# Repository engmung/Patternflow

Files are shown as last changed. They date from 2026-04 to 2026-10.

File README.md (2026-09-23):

# Patternflow








<p align="center">
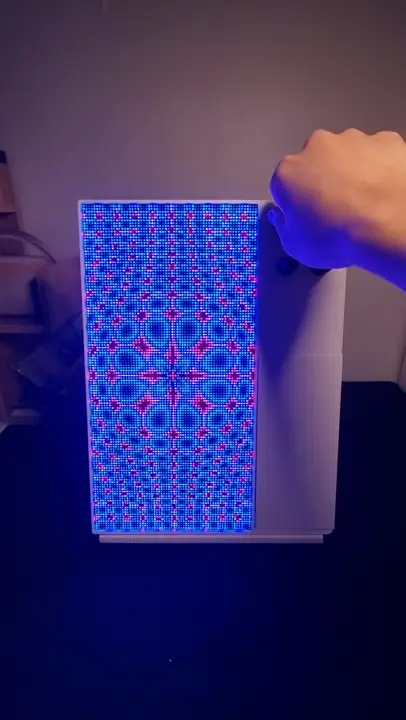
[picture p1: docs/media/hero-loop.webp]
Patternflow: a hand turns a knob and the light reshapes
  
  <a href="https://youtu.be/BPMhTChY9vg">Patternflow, the film: what it is, how it's built, and why</a>
</p>
<p align="center">
  <sub><a href="https://www.instagram.com/p/DbD2z1VSG09/">▶ the reel: <b>400k+ views</b> on Instagram</a> &nbsp;·&nbsp; <a href="https://youtu.be/BPMhTChY9vg">▶ <b>the film</b>: the whole story, on YouTube</a></sub>
</p>

> **Photosensitivity warning.** Patternflow displays rapidly changing light patterns that may trigger seizures in people with photosensitive epilepsy. If you experience any discomfort, stop use immediately.

**Patternflow is an open-source LED synthesizer.** You play it with four knobs. 8,192 pixels across a 128 × 64 matrix respond the instant you turn one; nothing is pre-rendered, every frame is computed live on the device. A pattern is just a small file, so every Patternflow plays every pattern anyone makes.

## Where it began

Almost every screen around us is a playback device. It takes in content and shows it to us, and we sit in front of it and watch. Patternflow is different: touch it and it answers in that instant, and nobody plays the same thing twice.

In January 2026 I stopped by the Nam June Paik Art Center, which happened to be running an event marking twenty years since Paik's death. That is how I ended up standing in front of *Participation TV* (1963): you speak into a microphone and the picture on the screen moves with your voice. It turned the viewer from someone watching into someone taking part. I spoke into it, and my voice became the picture.

Two months later I connected an LED matrix and a potentiometer for the first time.

Where Paik brought the audience into the work, Patternflow hands over the making of it.

I put that first pattern, *Patternflow: Origin*, on an LED matrix with four knobs and posted it online. Some people asked how to buy it; far more asked how to build it. So everything went public: schematics, firmware, 3D models, the build guide, and the whole workflow for making new patterns.

## The community responded

<p align="center">
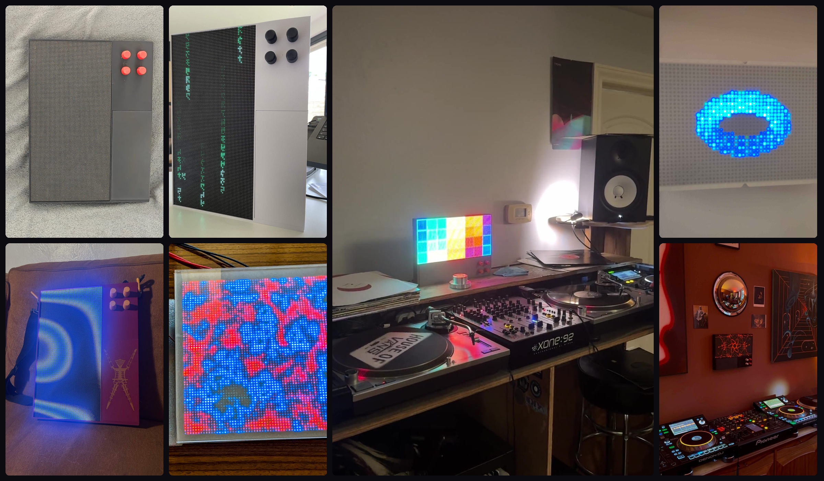
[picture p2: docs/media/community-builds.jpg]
Seven Patternflows built around the world: different enclosures, colors and materials, two of them in DJ booths
  
</p>
<p align="center">
  <sub><i>Builds by Nath (UK), shooter (Poland), day (France), Enerjoy (Norway), SimonePDA (UAE), Nick (USA), and Jon (USA).</i></sub>
</p>

Builders from around the world keep adding pins to the **[build map](https://patternflow.work/inside)**. Someone built theirs as a Raspberry Pi port with a 64 × 32 matrix, another layered paper and acrylic into a diffuser, others cut their own enclosures. Two of them live in DJ booths.

I started this alone. It hasn't worked that way for a while now. The web-upload feature wasn't mine: someone suggested it, built a proof of concept, and shared the code, and two days later it shipped as a main feature. The `.pfm` pattern modules came the same way. A contributor designed the loader, built it, and proved it on hardware before proposing it. They're core to the instrument now.

The clearest case started on the other side of the world. A media art collective took Patternflow's pattern modules, added MIDI control and a microphone, and built a browser-based instrument of their own: **[MOTIFLOW](https://azmano.art/portfolio-item/motiflow/)**, recently shown in a gallery. Patternflow had become something people build their own instruments out of.

**Patternflow is a thing we're all making now.**

## Make it yours

### 1. The device

The **[Full Build Guide](BUILD_GUIDE.md)** covers the official route: the custom PCB and a 3D-printed enclosure. Don't want to order a board? The **[Breadboard Build Guide](https://patternflow.work/build/breadboard)** wires the same electronics with jumper wires instead, and that's a real Patternflow, not a temporary prototype. Every other combination is on the **[Assembly Map](docs/assembly/README.md)**. Parts run about US$100–200 ([BOM](BUILD_GUIDE.md#1-bill-of-materials-bom)), it's all big through-hole joints, and every first-timer who has built one finished it. Most came back saying the soldering was the fun part.

**When yours lights up, tell us.** Post it in [Discord](https://discord.gg/Vr9QtsxeTk) or fill in the [Share your build](../../issues/new?template=share_build.yml) form and it goes on the build map, a globe of Patternflows where each pin carries its build's story. The map is for the ones people made themselves: every pin is someone who built one from these files, in their own material, wherever they are. The goal is simple: cover it with pins.

<p align="center">
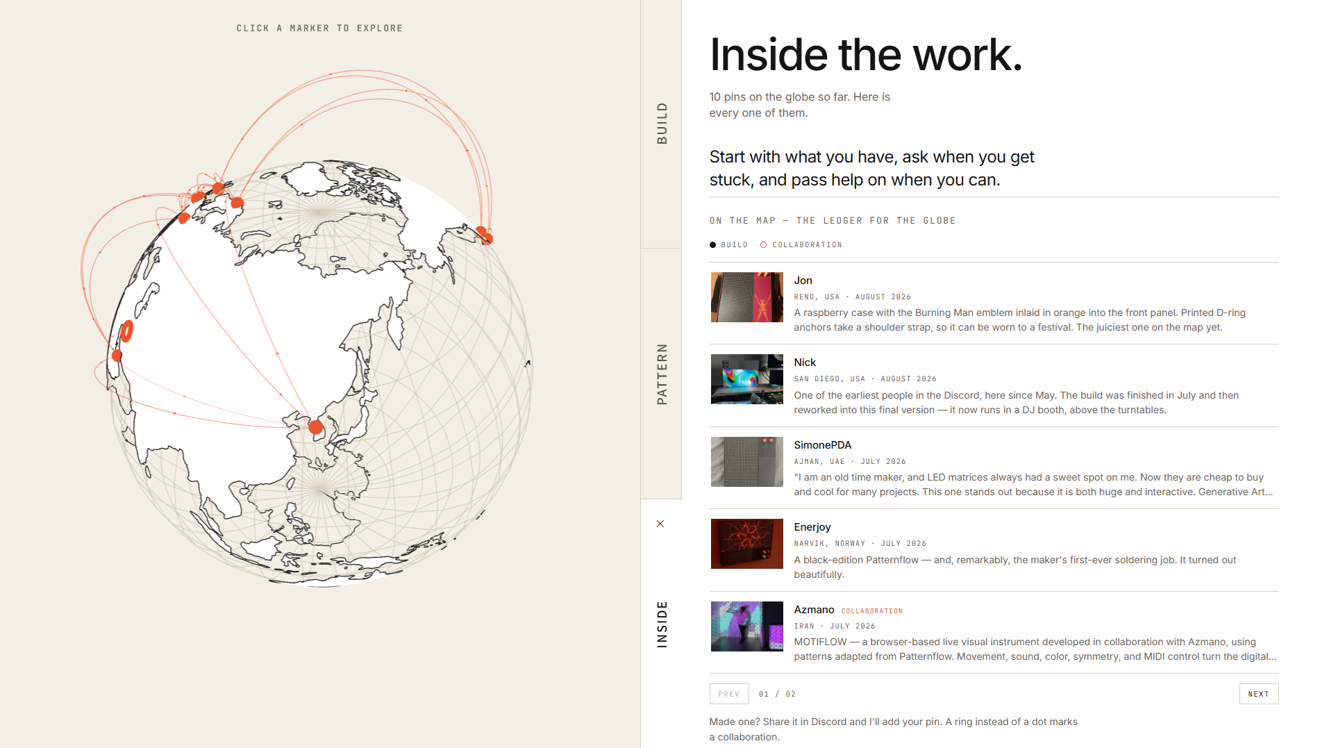
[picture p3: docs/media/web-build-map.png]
Build map: a globe of Patternflows built around the world, with the story of every build
  
</p>

If you'd rather have one arrive assembled, tested, and flashed, the **[Crowd Supply campaign](https://www.crowdsupply.com/engmung/patternflow)** is currently live. Back the campaign to have an assembled unit, DIY kit, or custom enclosure shipped worldwide.

### 2. Patterns

You don't need hardware to start. The **[Live Editor](https://patternflow.work/pattern)** is a full Patternflow simulator: turn the virtual knobs and it behaves like the real thing. Patterns start as JavaScript in the browser, and you don't have to write it yourself. Click **Copy creation prompt**, paste it into your AI assistant with a description of the look you want, paste back the code it returns, and play. You don't write GLSL or touch a rendering pipeline: the template handles the encoder mapping, brightness curve and pixel buffer, and you describe the visuals.

<p align="center">
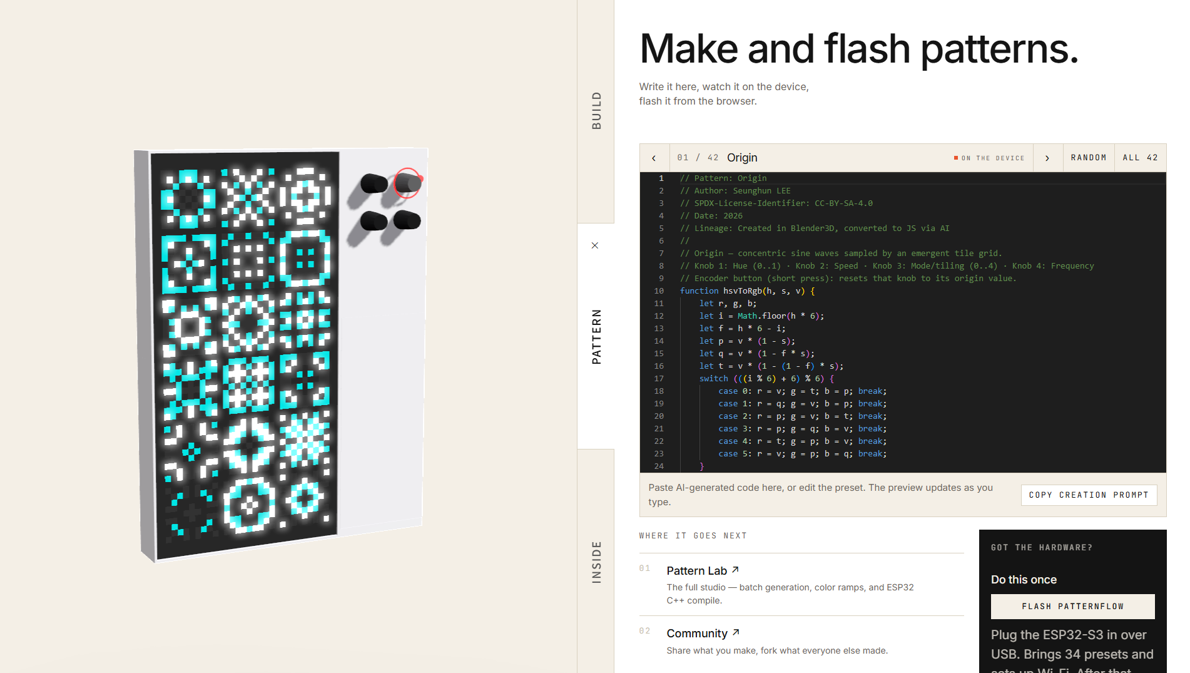
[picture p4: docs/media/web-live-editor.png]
Live Editor: a full Patternflow simulator in the browser, code beside the device
  
</p>

**[Pattern Lab](https://patternflow.work/pattern-lab)** is the full studio, and where a pattern reaches the hardware. Generate variations in batches, shape color ramps, retune knob ranges, then send it to your device: it builds into a small `.pfm` module and installs over Wi-Fi, about ten seconds start to finish. You never plug in a cable, reflash the board, or open an IDE. The Capture panel takes the same pattern off the panel: a PNG at print size for a business card, or an MP4 loop for a post, rendered in your browser with nothing uploaded.

When it looks right, publish it to the **[Community](https://community.patternflow.work/community)**. More than a hundred patterns are up already and the range keeps widening, from quiet waves to chaos-theory studies, every one written as code and every one playable under the same four knobs. Collect patterns into a deck and send it to your board in one click. Browsing needs no account, and publishing asks a username and password, no email. The **[Pattern Guide](PATTERN_GUIDE.md)** walks the whole loop.

<p align="center">
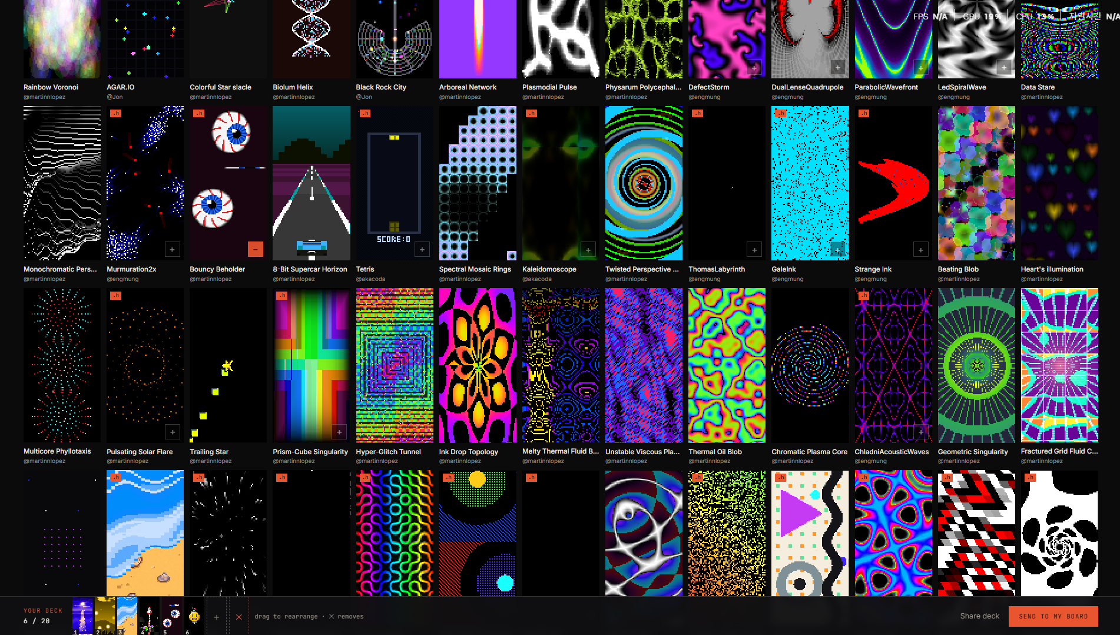
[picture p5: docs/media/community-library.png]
The community wall: dozens of patterns by different authors, each one playing, with a deck being assembled along the bottom
  
</p>

Patterns don't stay on the wall, either. New pattern studies go up on **[Instagram](https://www.instagram.com/patternflow.work)** almost daily. Publish something that stands out and it can get featured there, or ask for a collab on Instagram and we'll post yours together.

### 3. The ecosystem

Patterns are the surface. Underneath is an instrument still being designed, in the open, by whoever shows up. This is the whole system on one napkin:

<p align="center">
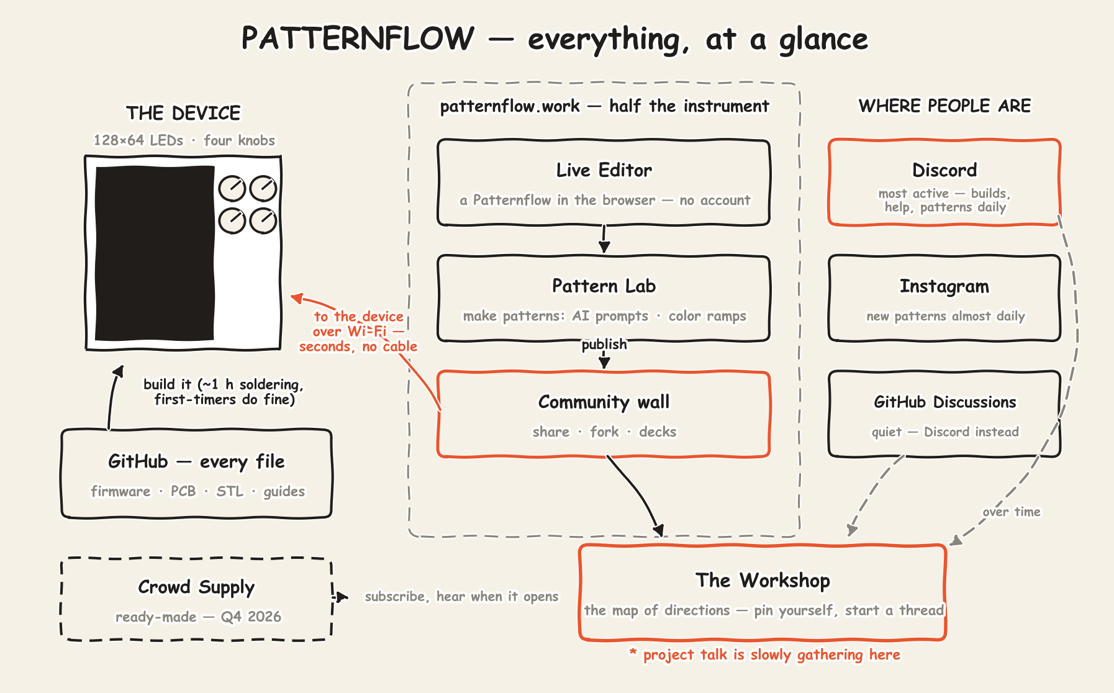
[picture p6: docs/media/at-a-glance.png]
Hand-drawn map of the Patternflow ecosystem: the device, the GitHub files and Crowd Supply routes to it; patternflow.work with the Live Editor, Pattern Lab and Community wall; Discord, Instagram and GitHub
  
</p>

It's already moving in directions I didn't choose. One contributor is building out MQTT further than I've had time to follow: units reaching each other across a network, one person's playing coming out of somebody else's device. Another is working on sound on the board itself. Another is taking the TouchDesigner link further than I did. None of it was assigned.

**[CONTRIBUTING.md](CONTRIBUTING.md)** covers how contributions flow. Questions and ideas go to the **[Discord](https://discord.gg/Vr9QtsxeTk)**; where to ask what is **[SUPPORT.md](SUPPORT.md)**.

## Quick facts

| | |
| :--- | :--- |
| **Display** | 128 × 64 HUB75 RGB LED matrix, P2.5 (320 × 160 mm) |
| **Brain** | ESP32-S3-WROOM-1 **N16R8** (16 MB flash, 8 MB PSRAM) · standalone, no sending card |
| **Input** | 4× EC11 rotary encoders with push-switch; long-press encoder 4 to switch patterns ([controls](#playing-it)) |
| **Power** | 5 V over USB from any power bank; about **4 h per 10,000 mAh** at max brightness with a typical pattern (see [runtime](#power--runtime)) |
| **Size / weight** | 245 × 325 × 36 mm (9.6 × 12.8 × 1.4 in) · 933 g (2.06 lb) |
| **Firmware** | Arduino-compatible C++, modular pattern architecture, runtime switching (no reflash) |
| **Flashing** | Everything from the browser: one USB flash the first time, then it's all Wi-Fi. Patterns install as modules in seconds, full firmware builds land wirelessly too. A local build (PlatformIO) only for firmware development or other matrix resolutions |
| **Connectivity** | Wi-Fi and USB. Network MIDI (a MIDI port in any DAW — Ableton, Logic, Bitwig), bidirectional OSC (Max/TouchDesigner/Resolume), MQTT and audio-react each ship in an [edition](docs/EDITIONS.md) you install in one click — the way patterns do — and switching keeps your patterns, networks and settings |
| **Editions** | One image ships on the board; others are a click away on [the shelf](https://patternflow.work/editions); what each feature does, with a reel of it, is on [the features page](https://patternflow.work/features). Writing a feature or cutting your own firmware starts at **[docs/EDITIONS.md](docs/EDITIONS.md)** |
| **Build** | ~1 h hands-on (≈30 min soldering + ≈30 min assembly, first-build friendly) + ~10 h 3D printing · US$100–200 in parts ([BOM](BUILD_GUIDE.md#1-bill-of-materials-bom)) |
| **License** | MIT (firmware & web code) · CC-BY-SA 4.0 (hardware, docs, bundled patterns) · community patterns are licensed by their authors ([summary](docs/LICENSE-SUMMARY.md)) |

### Power & runtime

Patternflow runs off any standard USB power bank that can supply a couple of amps at 5 V. You don't need a wall adapter, so it stays portable. Rule of thumb: **about 4 hours per 10,000 mAh** at maximum brightness with a typical pattern.

<details>
<summary>Measured runtimes</summary>

In testing, a 40,000 mAh bank dropped about 13% over 2 hours at **full brightness**, which is roughly **15 hours on a full charge**:

| Power bank | Approx. runtime (max brightness) |
| :--- | :--- |
| 10,000 mAh | ~4 hours |
| 20,000 mAh | ~8 hours |
| 40,000 mAh | ~15 hours |

These were measured with a bright generative pattern at maximum brightness, which is how the device is normally used. Lowering the brightness (long-press encoder 1) extends runtime well beyond these figures.

**Sleep mode** takes it further: the panel goes dark, the HUB75 transfer stops and the board idles, while staying on Wi-Fi so it can be woken again from MQTT or a browser. Hold encoder 2 for the NETWORK screen, then turn encoder 1; any knob or button wakes it. The pattern that was running comes back, as it does after a full power cut.

**A pattern that fills the screen with white is a different story.** The same 40,000 mAh bank dropped 9% in 30 minutes: about 26.6 W, or roughly 4.8 A at 5 V, which is above what a typical USB-A port is rated for and enough to make the connector warm. That works out to ~5.5 hours on a 40,000 mAh bank. A total-pixel-power clamp is going into the firmware so this can't happen; until then, avoid near-full-white patterns on a power bank, or use a supply and cable rated for the current.

</details>

## Playing it

Every encoder does two jobs. Turn it, or give it a short press, and you are moving the pattern that's running. Hold it down and a device function opens instead, and a second long-press closes it again.

<p align="center">
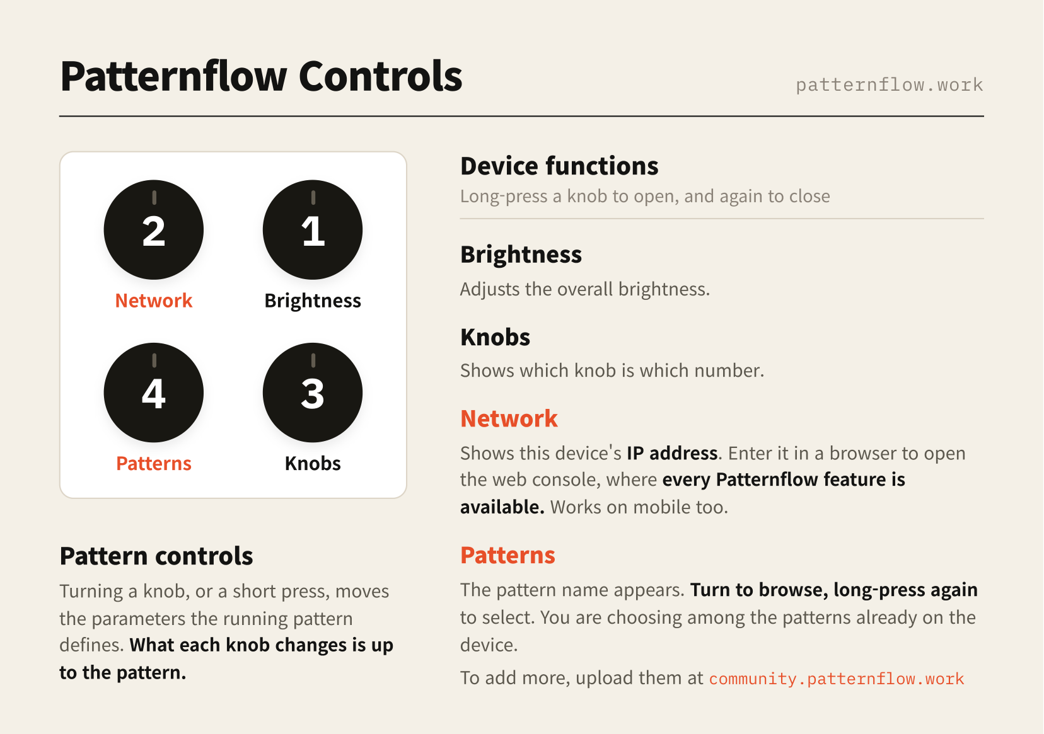
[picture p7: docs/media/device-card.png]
Patternflow controls: encoder 1 brightness, 2 network, 3 knob numbers, 4 patterns; turn or short-press to move the running pattern, long-press for device functions
  
</p>

What a knob does to a running pattern is the pattern's own decision, so the same knob feels different on every one of them. That is what encoder 3 is for: hold it and each knob puts its own number on the panel, which saves counting around the front.

The device functions themselves are fixed. Encoder 1 is brightness. Encoder 4 opens the pattern list, where you turn to browse the names and long-press again to load one, choosing from whatever is installed at the time. Encoder 2 puts the board's IP address on the panel, and typing that into a browser opens the web console, which carries every feature the device has and works from a phone.

## On the device

A new board boots into **Origin**, concentric sine waves sampled by an emergent grid, and long-pressing encoder 4 opens the list of whatever else is installed. Patterns live on the filesystem rather than inside the program. The firmware compiles in Origin alone, as the failsafe a board can always boot into, and everything else installs as **`.pfm` modules over Wi-Fi**, up to 128 of them, no reflash. Adding a pattern never costs a firmware update, and a firmware update never touches your patterns, your Wi-Fi, or your storage.

A new board is therefore nearly empty, so a set ships with it: the **Basics pack**, 33 patterns, at the top of the [decks shelf](https://community.patternflow.work/community/decks). One click installs the lot, no account and no build queue, or drop the `.zip` on your board's Patterns page yourself. The [Live Editor](https://patternflow.work/pattern) opens with its own preset library of 42 patterns, each loadable and remixable in the browser.

A local firmware build (PlatformIO, driven by `firmware/bundles/build.sh`) is only needed for feature development or targeting an LED matrix with a different resolution; the setup is [`firmware/README.md`](firmware/README.md) and a new feature starts at [FEATURE_GUIDE.md](FEATURE_GUIDE.md). Patterns never need it: [Custom Patterns](firmware/CUSTOM_PATTERNS.md). To rebuild the shipped pack from the repo's own preset sources, see [`firmware/toolchain/make_pack.py`](firmware/toolchain/make_pack.py).

## MIDI, OSC, MQTT & audio-react

<p align="center">
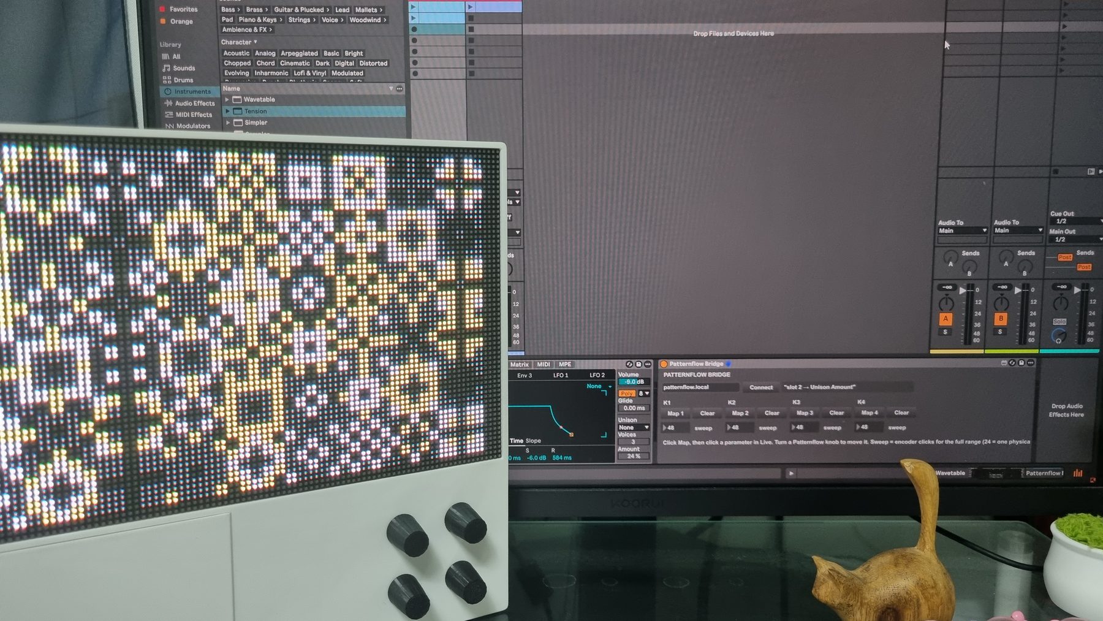
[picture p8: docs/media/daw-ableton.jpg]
Patternflow beside an Ableton Live session, with the Patternflow Bridge Max for Live device open and the four knobs mapped to Live parameters
  
</p>

Each of these lives in an **edition** — a firmware you install from [the shelf](https://patternflow.work/editions) in one click, the same way patterns arrive, and switching keeps your patterns, Wi-Fi networks and settings. MIDI, OSC and audio-react are in **Audio**; MQTT is in **Performance**, alongside sequences and the Director. Why it is arranged that way, and how to build your own: [`docs/EDITIONS.md`](docs/EDITIONS.md).

**MIDI, over the network.** *New.* The panel is a MIDI port: RTP-MIDI over Wi-Fi, native on macOS and iOS, one free driver on Windows. Its four knobs and buttons map to anything in Ableton with Ctrl-M, and a DAW drives the panel back with plain CC and Program Change — the Pattern Lab's Director exports a show as exactly those four CC lanes, so a show can play on the panel from Live's transport. Sensitivity per knob, an absolute or relative mode, and the session that reconnects itself all live on the panel's console. Step by step with screenshots: [`docs/midi-ableton.md`](docs/midi-ableton.md); the contract: [`docs/midi-spec.md`](docs/midi-spec.md).

**Bidirectional OSC.** Over Wi-Fi, Patternflow speaks OSC in both directions: knob turns, button presses, and pattern switches stream out to a remote host (Ableton Live, Max/MSP, TouchDesigner, anything that speaks OSC), and incoming OSC messages drive the device exactly like physical encoder motion. Play Patternflow as a controller for your set, let your set drive the light, or both at once. OSC is the language of Max, TouchDesigner, Resolume and Processing, and it carries more than MIDI can — pattern names, floats, a heartbeat. For Ableton Live Suite there's a ready-made Max for Live bridge in [`integrations/ableton`](integrations/ableton). Click Connect, map the four knobs to any Live parameters, done. The wire protocol is documented in [`docs/osc-spec.md`](docs/osc-spec.md).

**MQTT.** Patternflow also speaks MQTT, both ways, on the broker you already run ([the contract](docs/mqtt-spec.md)). Knob turns and pattern changes publish as they happen; messages coming the other way move the knobs and switch patterns exactly as a hand on the encoder would. Two boards pointed at the same broker follow each other, which is the short version of why it exists. It also puts the device on the same bus as the rest of a home or venue setup, so Home Assistant, Node-RED or a lighting desk can drive it without anything Patternflow-specific in the middle. Point it at a broker on the device's own **MQTT** page; a pattern can be addressed by name or by slug. Publishing `1` to `<prefix>/sleep` puts the panel to sleep and `0` wakes it, with the current state mirrored on `<prefix>/sleep/state`. That is enough for a Home Assistant switch, and it is the one command a panel obeys whether it is set to Publisher or Subscriber. Contributed by **[@SimonePDA](https://github.com/SimonePDA)** (Simone Majocchi), along with the browser-side zip unpacking that makes pattern packs install in one click.

**Audio-react.** The Chrome/Edge extension in [`tools/patternflow-audio-extension`](tools/patternflow-audio-extension) captures the current tab's audio, splits it into four bands you shape on a response graph, and sends the levels to the panel over a WebSocket. A pattern reads them as ordinary parameters, so every encoder-driven pattern reacts with no audio code of its own. The panel can also listen for itself: an on-board microphone runs the same analysis on the device, with no browser involved.

## How it's built

Patternflow is built around a standalone ESP32-S3 driving a HUB75 RGB LED matrix at low resolution, where each pixel reads as a discrete point of light with its own brightness and color. Four rotary encoders feed firmware written in Arduino-compatible C++ around a modular pattern architecture: each pattern is a self-contained module with its own setup, update, and draw routines, while the shared framework handles input, LED rendering, mode transitions, and color calibration. I designed the PCB myself; the enclosure is 3D-printed by default, with stainless steel, transparent acrylic, and laser-cut variations in progress.

## Repository & documentation

> **Moving fast.** [v3.10.4 is out](https://github.com/engmung/Patternflow/releases/tag/v3.10.4): the panel films properly on a phone. It now refreshes at exactly 300 Hz — the one rate the shutter speeds a phone actually uses (1/50, 1/60, 1/100, 1/30) all divide — so the rolling bands are gone at those; 1/120 and slow motion still band, and [the firmware README](firmware/README.md#refresh-rate-anti-flicker-for-video) says why and what to set. [v3.10.3](https://github.com/engmung/Patternflow/releases/tag/v3.10.3) made the panel's colours come out right: bright edges had been growing purple and sky-blue fringes and greys read pink; the cause was in the display driver — which bit plane each brightness window actually lights — and part of it was 3.10.1's own dark-end fix. The planes are exactly binary now, and because the fix is in the driver every installed pattern gets it without a rebuild. It also brings a [Knobs page](docs/rest-api.md#get-apiknobs-and-post-apiknobs) on the device (which way each encoder counts, set from the browser) and the [features catalogue](https://patternflow.work/features). Both editions — Audio v0.6.4, Performance v0.2.9 — are re-cut on this core. [v3.10.2](https://github.com/engmung/Patternflow/releases/tag/v3.10.2) made a Format that did not take stop reporting success, and a storage that will not mount say why. [v3.10.1](https://github.com/engmung/Patternflow/releases/tag/v3.10.1) fixed an upload that could reboot the board, a failed settings write that could make the next boot forget a good pattern, a mic-less Audio panel holding the knobs, and MIDI notes that would not let go. [v3.10.0](https://github.com/engmung/Patternflow/releases/tag/v3.10.0) made a heavy pattern come on every time. [v3.9.5](https://github.com/engmung/Patternflow/releases/tag/v3.9.5) taught the web console to survive a slow Wi-Fi link and a heavy pattern, and put thumbnails under the knob. [v3.8.0](https://github.com/engmung/Patternflow/releases/tag/v3.8.0) split the firmware into [editions](docs/EDITIONS.md) — core, Audio (on-board microphone, OSC, network MIDI) and Performance (sequences, MQTT, weather) — installable in one click and switchable without losing your patterns. [v3.2.0](https://github.com/engmung/Patternflow/releases/tag/v3.2.0) made patterns install over Wi-Fi as `.pfm` modules, no reflash. On v2.x hardware? Everything you need stays bundled at [v2.1.0](https://github.com/engmung/Patternflow/releases/tag/v2.1.0). Follow the [changelog](CHANGELOG.md) and the [journal](https://patternflow.work/journal) for what's current.

| Folder | Contents |
| :--- | :--- |
| `firmware/` | Arduino code for ESP32-S3, the custom pattern template, and the toolchain that builds patterns into `.pfm` modules and packs |
| `hardware/` | Enclosure files and electronics source files (case, PCB, Gerbers, schematic PDF) |
| `web/` | Next.js site (landing, Live Editor, Pattern Lab, community, browser flasher & build server, journal); the breadboard build guide is a React page here |
| `docs/` | The contracts (HTTP, OSC, MIDI, MQTT, audio WebSocket, show files), how the firmware is put together (`EDITIONS.md`), the assembly map, walk-throughs, records and media — indexed in [`docs/README.md`](docs/README.md), with the folder-by-folder map in [`docs/REPOSITORY.md`](docs/REPOSITORY.md) |
| `tools/` | Desktop-side helpers, including the audio-react browser extension |
| `integrations/` | Host-software bridges: Ableton Live / Max for Live (OSC knob mapping) |
| `.github/` | Issue and PR templates, and the CI that runs on every pull request (web, every firmware edition, doc links, console pages) |

**Build:** [Full Build Guide](BUILD_GUIDE.md) · [Assembly Map](docs/assembly/README.md) · [Panel Compatibility](docs/panel-compatibility.md) · [Hardware files](hardware/README.md)
**Play:** [Pattern Guide](PATTERN_GUIDE.md) · [Custom Patterns](firmware/CUSTOM_PATTERNS.md) · [Audio Guide](AUDIO_GUIDE.md) · [MIDI in Ableton](docs/midi-ableton.md)
**Extend:** [Feature Guide](FEATURE_GUIDE.md) · [Editions](docs/EDITIONS.md) · [Firmware build](firmware/README.md) · [Web architecture](web/ARCHITECTURE.md) · [HTTP API](docs/rest-api.md) · [OSC Spec](docs/osc-spec.md) · [MIDI Spec](docs/midi-spec.md) · [Director → MIDI](docs/director-midi.md)
**Project:** [Contributing](CONTRIBUTING.md) · [Support](SUPPORT.md) · [Repository map](docs/REPOSITORY.md) · [Changelog](CHANGELOG.md) · [License Summary](docs/LICENSE-SUMMARY.md) · [Manifesto](docs/manifesto.md)

**Links:** [patternflow.work](https://patternflow.work) · [Community](https://community.patternflow.work/community) · [Crowd Supply](https://www.crowdsupply.com/engmung/patternflow) · [Releases](../../releases) · [Discord](https://discord.gg/Vr9QtsxeTk) · [Instagram](https://www.instagram.com/patternflow.work)

## Contributing

Builds, documentation fixes, part sourcing tips, enclosure remixes, firmware features and host-software bridges are all welcome. **[CONTRIBUTING.md](CONTRIBUTING.md)** has one table of where each kind goes and what CI runs on it; **[SUPPORT.md](SUPPORT.md)** says where to ask. Patterns don't come here: publish them from the Pattern Lab to the Community.

## Story so far

| When | Milestone |
| :--- | :--- |
| **Jan 2026** | *Patternflow: Origin*, the first work as a new media artist, built around 3D-printed forms and the seed of what became Patternflow · visited the Nam June Paik Art Center |
| **Mar 2026** | The Origin pattern ran on a physical LED matrix with four knobs for the first time |
| **Apr 2026** | Instagram and the Arduino subreddit responded strongly (**150,000+ views and 3,700 upvotes**), and the community asked for the files, not a product, so Patternflow went open source · first PCB fabricated *(sponsored by PCBWay)* · website live |
| **May 2026** | Reached **100 GitHub stars** · the first collaborator joined · Crowd Supply agreement · Discord community growing |
| **Jun 2026** | [Crowd Supply pre-launch page](https://www.crowdsupply.com/engmung/patternflow) live, backed by countless refinements toward mass production · Instagram passed **1,000 followers** · first community-made pattern shared |
| **Jul 2026** | Refining the design for mass production · growing an active community · outreach and promotion |
| **Aug 2026** | [Crowd Supply campaign](https://www.crowdsupply.com/engmung/patternflow) officially launched worldwide · firmware split into [editions](docs/EDITIONS.md) (Audio & Performance) over an unchanged core · global press wave across Mixmag, Synthtopia, AMAZONA.de, and MATRIXSYNTH |
| **Sep 2026** | Driving the Crowd Supply campaign to funding success · preparing mass production and fulfillment logistics · FreeRTOS dual-core network isolation, fast CIE frame push, and continuous ecosystem polish |
| **Next** | Deliver rewards to backers at the highest quality · send Patternflow further out into the world · collaborate with more artists · earn academic recognition |
| **2028** | Grow Patternflow into a self-sustaining community and ecosystem, then move on to the next project |

Longer write-ups and the full story behind each step live on the **[journal](https://patternflow.work/journal)**: the whole process, written up at least weekly since the beginning, the thinking and the emotions included, and the parts that went badly too. If you want to know why this project exists and what it costs to keep alive, start there.

### Sponsor

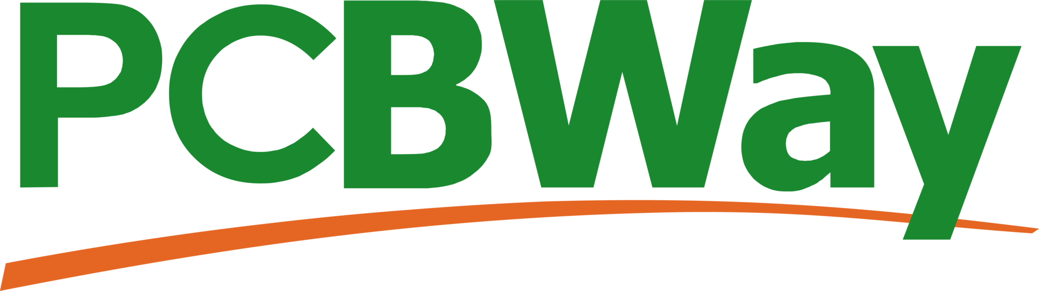
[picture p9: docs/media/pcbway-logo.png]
PCBWay


Patternflow's PCB fabrication and 3D-printed enclosure are sponsored by **[PCBWay](https://www.pcbway.com/)**. The first PCB came back clean and on-spec, ordering was straightforward, and the team has been genuinely responsive throughout. That support made these milestones possible.

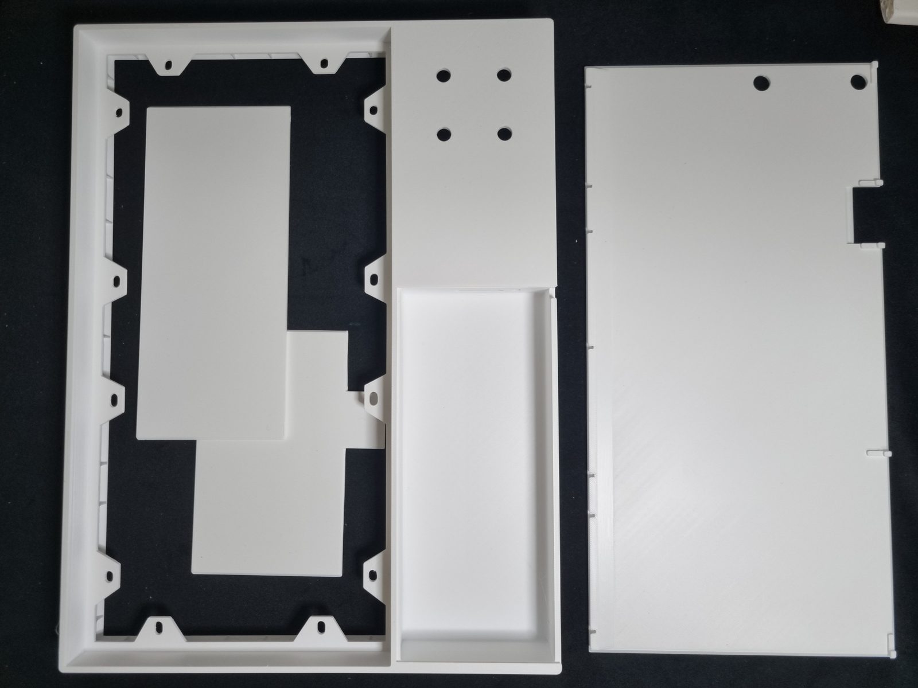
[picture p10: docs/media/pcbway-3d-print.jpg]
Patternflow enclosure parts 3D-printed by PCBWay
First Patternflow PCB fabricated by PCBWay&nbsp;&nbsp;

<sub><i>The first Patternflow PCB, fabricated by PCBWay, and the enclosure they printed.</i></sub>

## License

A file's SPDX header is the authority where one exists; folders are not license boundaries, and files that cannot carry a header (STL, Gerber, images) take the license the nearest README states. Full breakdown in the **[License Summary](docs/LICENSE-SUMMARY.md)**.

- Firmware & web code: **MIT** ([LICENSE-MIT](./LICENSE-MIT))
- Hardware, designs & docs: **CC-BY-SA 4.0** ([LICENSE-CC-BY-SA](./LICENSE-CC-BY-SA))
- Bundled patterns (the presets shipped in the firmware and the editor): **CC-BY-SA 4.0**, per-file SPDX headers.
- Patterns contributed *to the repository*: inbound = outbound. By sending a pattern as a PR, issue or Discord post you license it under CC-BY-SA 4.0, attribution kept in the code header (no CLA). See [CONTRIBUTING.md](CONTRIBUTING.md).
- Patterns published *to the Community*: **licensed by their author**, either **CC-BY-SA 4.0** (default) or **CC-BY-4.0**. Both permit commercial use with credit; CC-BY-SA additionally requires adaptations to stay under the same license. A fork can never be looser than what it came from, and carries a `Based on:` credit to the original author in its source.

"Patternflow" is a trademark of SeungHun Lee.

The Patternflow series: LED Synthesizer (2026) · Origin (2026)

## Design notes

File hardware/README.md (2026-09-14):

# Patternflow Hardware

Open hardware files for Patternflow: the board, the enclosure, the bill of materials. CC BY-SA 4.0 — see the root [LICENSE-CC-BY-SA](../LICENSE-CC-BY-SA).

## Which board is current

| Board | Status | Order | Parts | Case |
| :--- | :--- | :--- | :--- | :--- |
| **v3.9** | **Current.** The v3.0 board with the USB-C power footprint removed: `J4`, the screw terminal, is the only power input. Outline, mounting holes and every other footprint are unchanged from v3.0 | [`pcb/gerber/patternflow_v3.9_gerber.zip`](pcb/gerber/) or the [PCBWay shared project](https://www.pcbway.com/project/shareproject/Patternflow_An_LED_synthesizer_776d796c.html) | [`bom/bom_v3.9.csv`](bom/bom_v3.9.csv) | `case/bed_256mm/` or `case/bed_330mm/` + `case/knobs/` |
| v3.0 | Previous revision, fabricated and verified. If you already have one, build it: leave `USB1`, `R1`, `R2` unpopulated ([#221](https://github.com/engmung/Patternflow/issues/221)) | `pcb/gerber/patternflow_v3.0_gerber.zip` (only if you specifically want that footprint) | [`bom/bom_v3.0.csv`](bom/bom_v3.0.csv) | the same v3 cases |
| v2.1 | Legacy. Last of the v2.x generation; **does not fit the v3 cases** | `pcb/gerber/patternflow_v2.1_gerber.zip` | inside the [v2.1.0 guide](https://github.com/engmung/Patternflow/blob/v2.1.0/BUILD_GUIDE.md#1-bill-of-materials-bom) | `case/legacy_v2/` |
| v1.0, v2.0 | Archived early revisions | — | — | — |

The build itself is [`../BUILD_GUIDE.md`](../BUILD_GUIDE.md) (v3 boards) and [`../BUILD_GUIDE_v2.md`](../BUILD_GUIDE_v2.md) (v2.x); the map of every enclosure + electronics combination is [`docs/assembly/README.md`](../docs/assembly/README.md). Every v3.x firmware release runs on every v3 board; the pin map has not changed since v2.

## Folders

- `pcb/` — the circuit board ([overview with schematic and renders](pcb/README.md))
  - `kicad/` — the editable KiCad 10 project, with its local footprint and 3D libraries
  - `gerber/` — fab-ready zips, one per revision (`patternflow_vX.Y_gerber.zip`); `gerber/experiment/` is for unverified work and is empty when nothing is in flight
  - `images/` — board renders and the schematic as SVG, regenerated with `kicad-cli` (recipe in the PCB README)
  - `schematic.pdf` — the schematic without KiCad
- `case/` — the 3D-printed enclosure ([which folder to print, settings, assembly notes](case/README.md))
  - `bed_256mm/` — the standard build, split for P1S-class beds; also the Bambu Studio project `patternflow_v3.3mf`; `for_other_panels/` is the adjustable-mount variant for panels whose bolt holes differ
  - `bed_330mm/` — the one-piece body for H2S-class beds
  - `knobs/` — knob plates for 15 mm and 20 mm encoder shafts, printed with every build
  - `source/` — the Blender source for every printed part (Git LFS; download it from the [latest release](https://github.com/engmung/Patternflow/releases/latest) rather than the ZIP button)
  - `legacy_v2/` — every v2.x-board case
  - `legacy_lasercut/` — the v1/v2 acrylic drawings, kept for the record ([README](case/legacy_lasercut/README.md))
  - `remixes/` — community enclosure variants, one folder each with its own README as the license header ([how to add one](case/remixes/README.md))
- `bom/` — the machine-readable bills of materials ([sourcing notes and column reference](bom/README.md)). **`bom_v3.9.csv` is the source of truth**: the parts table in the build guide and the schematic are kept in step with it.

## How things are named

Board revisions are numbers on the file (`patternflow_v3.9_gerber.zip`, `bom_v3.9.csv`); case folders are named by the **printer bed** they fit, because the same board goes in either; and `legacy_*` holds what an older board needs. `encloser.stl` is a misspelling that shipped in a release and on MakerWorld, so the file keeps its name.

## Getting one file without cloning

GitHub's *Download ZIP* gives you every STL and Gerber (they are ordinary files). For a single file, open it on GitHub and use *Download raw file*. The Blender source is the one exception (Git LFS) — take it from a release.

## Changing the hardware

Editing the board means regenerating the Gerber zip, the renders and the schematic exports with the commands in [`pcb/README.md`](pcb/README.md), updating the BOM CSV, and checking the build guide's parts table against it — the three must agree. Editing the case means re-exporting the STLs from the Blender source as [`case/README.md`](case/README.md) describes. A variant you want to share rather than merge is a [remix](case/remixes/README.md).

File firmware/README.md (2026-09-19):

# Patternflow Firmware

Arduino-based firmware for the ESP32-S3 powering Patternflow. One image serves every board generation — the pin map is identical on v2.x, v3.0 and v3.9.

The firmware handles the ESP32-S3 DMA driver for the HUB75 LED matrix, reads four rotary encoders to control generative patterns, and supports Arduino OTA for wireless updates.

> ⚠️ **Panel compatibility.** This firmware drives the panel directly from the ESP32-S3, so the panel's **driver IC** decides whether it lights up: classic shift-register parts work, S-PWM "video wall" parts stay completely dark, and "HUB75E" on a listing proves nothing. The list of chips, and how to check before buying, is **[docs/panel-compatibility.md](../docs/panel-compatibility.md)**; the driver is selected below via `PANEL_PROFILE`.

## Reading order

This file is long because it is the firmware's reference. Most people need one part of it:

| you want to | read |
| --- | --- |
| build and flash the firmware locally | [Setup](#setup) — the board package, PlatformIO, the libraries |
| write a feature or cut an edition | [`docs/EDITIONS.md`](../docs/EDITIONS.md) first, then [Adding features — the constraints that matter](#adding-features--the-constraints-that-matter) here |
| write a pattern | [`PATTERN_GUIDE.md`](../PATTERN_GUIDE.md) (nothing here is needed); the hands-on route is [`CUSTOM_PATTERNS.md`](CUSTOM_PATTERNS.md) |
| know what a pattern can call | [Foundation modules](#foundation-modules) |
| know how `.pfm` modules load and what they cost | [Loadable pattern modules](#loadable-pattern-modules-pfm) |
| tune brightness, calibration, refresh | [Configuration](#configuration-configh) |
| know what the knobs and buttons do | [Controls](#controls), [Sleep mode](#sleep-mode) |
| drive the panel from other software | the contracts in [`docs/`](../docs/README.md): HTTP, OSC, MIDI, MQTT, audio |
| edit a console page | [`patternflow/console/README.md`](patternflow/console/README.md) |

## Building your own firmware

One image ships on the board, and it is not the only one you can run. Features
are modules in this tree; a build is a choice of which ones compile in; a
published build is an **edition**, installed from
[the shelf](https://patternflow.work/editions) in one click, with your
patterns and settings intact.

**[docs/EDITIONS.md](../docs/EDITIONS.md)** is where that starts: what a
feature is, how to write one, how to cut an edition, and the promises every
build keeps so switching stays safe. Read it before writing a feature.

## Setup

### Required board package
- ESP32 by Espressif Systems — **2.0.x, not the latest 3.x** (see below)

> ⚠️ **The core version decides how much RAM your patterns get.** Core 3.x
> ships ESP-IDF 5.5, which occupies about **71 KB more internal RAM before the
> sketch even starts** than core 2.x / IDF 4.4 — the gap is already there at the
> first heap reading in `setup()`, before Wi-Fi is up, and no sdkconfig setting
> reverses it (the Wi-Fi buffer flags are identical between the two prebuilts).
> Measured on the same board with the same source, free internal heap once the
> network services are up:
>
> | | free | largest block |
> |---|---|---|
> | core 3.3.8 (IDF 5.5) | 15,320 B | 7,668 B |
> | core 2.0.17 (IDF 4.4) | **98,708 B** | **90,100 B** |
>
> That largest-block number is the hard ceiling on a loadable module: a `.pfm`'s
> `.text` has to land in one contiguous internal executable block, because the
> S3 cannot execute loaded code from PSRAM. On core 3.x a 12 KB pattern is
> simply refused; on core 2.x it loads and runs. See
> [Internal RAM is the budget](#internal-ram-is-the-budget-everything-else-is-roomy).

### Build with PlatformIO (recommended)

`platformio.ini` in `patternflow/` pins core 2.x and is what the measurements
above come from. It also builds in ~90 s against the IDE's several minutes.

```bash
cd firmware/patternflow
pio run                       # → .pio/build/firmware/firmware.bin
pio run -t upload             # or flash it yourself at 0x10000
```

`toolchain/sync_ino_to_src.py` copies the sketch into `pio_src/` and clones the
libraries below into `lib/` on first run, so there is nothing to install by
hand. On Windows, build from a path with no non-ASCII characters, or point
`PLATFORMIO_BUILD_DIR` at one — the xtensa linker cannot write outputs
underneath a path it cannot encode.

The Arduino IDE path still works and is documented below; it is what the older
guides describe. Just install core **2.0.x** rather than the latest.

### Arduino IDE board settings
- **Board:** ESP32S3 Dev Module
- **PSRAM:** OPI PSRAM
- **Flash Size:** 16MB
- **Partition Scheme:** 16M Flash with PSRAM-aware partition
- **USB CDC On Boot:** Enabled
- **Upload Mode:** UART0 / Hardware CDC

> **Why CDC On Boot matters.** It decides whether `Serial` is the native USB
> peripheral or UART0 — and therefore which of the two USB-C ports answers the
> browser flasher's Wi-Fi setup (Improv speaks over `Serial`). Enabled puts it
> on the **left/native `USB`** port, which is what the released firmware does
> and what §8.1 of the build guide tells people to use. Building with it
> disabled produces firmware that flashes fine but whose Wi-Fi setup only
> appears on the other socket.

### Required libraries
PlatformIO clones these for you (`lib_deps` in `patternflow/platformio.ini`
is the authoritative list). For the Arduino IDE, install them via the
Library Manager:
- `ESP32-HUB75-MatrixPanel-DMA` (for driving the matrix)
- `Adafruit GFX Library` (dependency)
- `WebSockets` by Markus Sattler / Links2004 (audio-react, Audio edition)
- `NimBLE-Arduino` (the `ble` feature — in the tree, in no edition)
- `AppleMIDI` by lathoub (network MIDI, Audio edition)

> The Arduino IDE builds the default firmware. It does not build the editions:
> their feature set is chosen by `firmware/bundles/<name>/features_local.h`,
> which only `bundles/build.sh` wires in. Use PlatformIO for anything that is
> not the plain device.

> The HUB75 library is also **vendored** under `patternflow/src/hub75/`, and that
> copy is the one that compiles — it carries Patternflow's additions
> (`resumeDMAoutput()` for sleep, the brightness hook the power clamp uses). The
> installed/cloned copy only needs to satisfy headers, so its exact version does
> not matter. See `src/hub75/VENDORED.md`.

OSC uses the ESP32 Arduino core's built-in `WiFi` and `WiFiUdp` libraries, so it does not require an extra OSC library. The MQTT client (`pubsubclient`) and the HUB75 driver are vendored under `patternflow/src/`.

## Project layout

```
firmware/
├── patternflow/                 # The sketch (PlatformIO project; open patternflow.ino)
│   ├── patternflow.ino          # Main sketch: input routing, mode dispatch — THE CORE
│   ├── config.h                 # Hardware configuration (pin mappings, limits, LED calibration)
│   ├── net_config.h             # Wi-Fi / Improv / OTA / self-update defaults (core only)
│   ├── pattern_registry.h       # Presets compiled in (Origin) + .pfm modules discovered on FATFS
│   ├── platformio.ini           # The build. bundles/build.sh drives it.
│   ├── presets/                 # Curated presets (35). Only Origin is compiled in; the
│   │                            # rest ship as the Basics pack (web/public/packs/)
│   ├── abi/                     # Host ⇄ module contract for loadable patterns
│   │   ├── pf_abi.h             # Frozen C ABI: PFHostAPI, PFPatternModule, PF_ABI_VERSION
│   │   ├── pf_params.h          # The absolute parameter bus
│   │   └── pf_module.h          # Module SDK — the ONE header a .pfm pattern includes
│   ├── patternflow_secrets.example.h  # Template (copy to patternflow_secrets.h)
│   ├── src/                     # Foundation — the core, feature-free (see docs/EDITIONS.md)
│   │   ├── core_display.h       # HUB75 driver init + refresh-rate config
│   │   ├── core_encoders.h      # Encoder ISRs + InputFrame contract
│   │   ├── core_canvas.h        # 128×64 RGB888 framebuffer + gamma/WB/sat
│   │   ├── core_math.h          # PFMath — shared verbatim with modules
│   │   ├── core_color.h         # PFColor — shared verbatim with modules
│   │   ├── core_noise.h         # PFNoise — shared verbatim with modules
│   │   ├── core_mem.h           # PSRAM-first allocator (PFMem)
│   │   ├── core_tables.h        # Panel-space polar tables (host-owned, 32 KB each)
│   │   ├── core_module_loader.h # ELF loader/relocator for .pfm modules
│   │   ├── core_power.h         # Total power clamp (measures demand, caps brightness)
│   │   ├── core_sleep.h         # Sleep mode: panel off, board idle, still on the network
│   │   ├── core_wifi.h          # Multi-network Wi-Fi (up to 5 saved, tried in order)
│   │   ├── core_improv.h        # Improv-Serial provisioning from the browser flasher
│   │   ├── core_http.h          # The one port-80 WebServer every page registers on
│   │   ├── core_net_task.h      # The network task on Core 0: Wi-Fi, HTTP, Improv, OTA
│   │   ├── core_loop_sync.h     # Hands a handler's frame-touching work to the loop task
│   │   ├── core_bus.h           # Absolute knob bus (0..1000 wire scale)
│   │   ├── core_web_update.h    # Browser self-update (/update)
│   │   ├── core_patterns_http.h # Module manager (/patterns + /api/patterns)
│   │   ├── core_status_http.h   # Diagnostics (/status + /api/status)
│   │   ├── core_wifi_http.h     # Wi-Fi manager (/wifi + /api/wifi)
│   │   ├── *_index.h            # PROGMEM HTML for the pages above (generated from console/)
│   │   ├── hub75/, webserver/, pubsubclient/   # Vendored libraries (see their VENDORED.md)
│   │   └── fonts/
│   ├── features/                # Everything that is not the device: one directory each
│   │   ├── pf_feature.h         # The hook interface a feature implements
│   │   ├── pf_features.h        # The dispatcher
│   │   ├── features.h           # The default list (empty) and the escape hatch
│   │   ├── osc/  audio/  audio_in/  midi/  ble/  mqtt/  show/  weather/
│   │   └── README.md            # What a feature is and the hooks it can answer
│   ├── console/                 # The device's web pages as plain HTML — edit these
│   └── toolchain/               # PlatformIO extra_scripts (must stay sketch-relative)
├── bundles/                     # Editions: two files each naming a feature set
│   ├── audio/  performance/  clock/  midi/   # features_local.h + overrides.h (+ env)
│   ├── build.sh                 # build the default, a named edition, or `all`
│   └── shelf.sh                 # stage a publishable image for the site
├── modules/                     # The module toolchain's working folder, not an inbox — see modules/README.md
├── encoder_test/                # Standalone encoder diagnostic sketch
└── toolchain/                   # Repo-level tooling: build a module or a pack, the console pages, the CI checks — see toolchain/README.md
```

`src/` holds the foundation that patterns build on; `features/` holds everything the device can do beyond being a panel with four knobs, and the core never names any of it — that rule, and why, is [`docs/EDITIONS.md`](../docs/EDITIONS.md). Patterns and the main sketch reference the helpers via `#include "src/core_*.h"`.

The foundation files are stateless utilities — no global state to coordinate, safe to include from any pattern.

## Foundation modules

Patterns should not duplicate trig tables, color converters, or noise functions. The foundation modules provide them once, shared across every pattern.

### `core_canvas.h` — PFCanvas
The single point of contact with the LED driver. Patterns write pixels into the canvas; the canvas pushes the frame to the HUB75 panel.

```cpp
PFCanvas::setPixel(x, y, r, g, b);   // inside the pixel loop
PFCanvas::present();                  // last line of draw()
```

Patterns must not call `dma_display->drawPixelRGB888()` directly. Global brightness, gamma, white balance, saturation, and any future post-processing live in `present()` — patterns that bypass the canvas miss those.

`present()` runs three post-processing steps before pushing pixels:
1. **Saturation boost** — pulls each pixel away from its Rec.601 luma in 8.8 fixed-point. Gray pixels are mathematically unchanged; saturated colors land closer to where the JS preview puts them. LED panels look washed out vs. a calibrated monitor, so a mild boost (default 1.10×) compensates.
2. **Per-channel gamma + white balance** — three 256-entry LUTs (one per channel) with the WB gain pre-multiplied into the gamma curve. HUB75 panels are linear PWM with unbalanced LED primaries (red is brighter per duty, blue is dimmer), so a single global gamma can't cover both correction needs. The pre-folded LUT means the inner loop pays the same cost as a single lookup.
3. **DMA push** — the vendored driver's `blitRGB888()` composes both scan halves and two adjacent columns per word, preserving the DMA control bits. Saturation and LUT work above are fused into that pass.

The current word-aligned blit measured **6.86 → 5.90 ms** on the bench's
128×64, 8-bit, 260 Hz configuration, with identical output. It needs no extra
framebuffer. See the [performance and recovery bench report](../docs/investigations/2026-09-firmware-runtime.md)
for the controlled comparison and its limits.

All five calibration values are tunable from `config.h` — see "LED panel calibration" below.

### Runtime notes (3.10): activation worker, memory admission, network maintenance, MIDI transport

The follow-up [runtime research](../docs/investigations/2026-09-firmware-runtime.md)
measures whole-loop delays, upload/load overlap, simulation warm-up and memory
policy. It separates tested improvements from experimental results and proposed
architecture work; its temporary profiler is not part of a normal build.

The resulting common-runtime implementation adds a small permanent `runtime`
snapshot to `/api/status`. Its whole-loop maximum includes work outside the
rendered-frame timer; `?resetTiming=1` returns the previous snapshot and begins
a new window. This is scheduling evidence, not a physical encoder-to-photon
measurement.

Pattern activation uses one reusable Core-0 worker with a **12,288-byte stack
reserved at boot**. Keeping that stack resident costs RAM between selections,
but avoids repeatedly finding a large contiguous block in a fragmented heap.
If it cannot be created, a later activation can retry; it never runs arbitrary
module setup on the render loop as a fallback. Boot restoration still uses
the synchronous path before interactive rendering begins. An allocation refusal
can be temporary while HTTP/UDP buffers are in use. The worker retries only
that failure class, at most five times with 1.5 seconds of total backoff.
Corrupt files and unresolved symbols fail immediately; the frame never waits
on the retry delay. `moduleMemory.loaderRetries` distinguishes recovered
admission attempts from a final `loadError`.

Storage mutations use conditional frame-boundary attempts. An unfinished
loader leaves the request pending while frames continue. Once quiescent,
activation is held during file changes, and later selections retain their
module path across catalog reordering. Catalog restoration starts an
asynchronous load. The single-core HTTP fallback replies busy when it cannot
complete the attempt inline. An open upload body prevents idle recovery from
starting a module against partially written storage; abort removes that partial
file and schedules restoration.

`src/core_module_memory.h` applies a 24,576-byte internal **byte-addressable**
service reserve to module allocations, including PSRAM-to-internal fallbacks.
Admission checks the relevant largest block and rechecks service RAM after an
allocation. Executable IRAM is not presumed interchangeable with byte RAM.
This protects against module allocations consuming the reserve; unrelated
system/feature allocations can still reduce free memory. Large data prefers
PSRAM; small data can remain internal. Module dynamic allocations keep their
16-slot, unload-as-a-group lifetime and add a configurable 4 MiB limit
(`PF_MODULE_RUNTIME_MAX_BYTES`); `moduleMemory` reports usage and refusals.

During loading, the loop waits out an 8 ms minimum period and running-mode
previews refresh at most every 64 ms unless their target/canvas changes.
Input and feature hooks still run each loop. Normal rendering has no new cap.
These policies apply to existing and future modules without editing pattern
code or changing the ABI.

The network worker's Wi-Fi/name maintenance hook is also serviced while the
HTTP parser waits, a conditional loop request is pending, or a page-body
socket is backpressured. Nonblocking sends retain the existing 20 s stall /
120 s total budgets. No HTTP re-entry or extra task is involved. Filesystem
operations and other synchronous library calls can still delay maintenance;
`netMaintenance.maxGapMs` exposes those gaps.

The Audio edition's MIDI feature additionally owns a separate 4,096-byte
Core-0 transport worker. A display frame can be long enough to overflow the
SDK's six-datagram UDP mailbox when four independent CCs arrive together.
The worker parses and sends RTP-MIDI between frames, while fixed queues hand
events to/from the frame task. Their 1,536 bytes of payload storage live in
PSRAM; queue indices and synchronization remain internal. The worker never
changes the parameter bus or a pattern directly. If storage or worker creation
fails, frame polling remains available and `midi.rxDetail.worker` reports
false. This implementation lives entirely in `features/midi/`.

See the [implementation and MIDI follow-up report](../docs/investigations/2026-09-firmware-runtime.md)
for measured before/after results and remaining limitations.

### `core_math.h` — PFMath
```cpp
PFMath::buildSinLUT();                       // call from setup() — idempotent
PFMath::fastSin(angle);                      // ~5x faster than sinf in pixel loops
PFMath::fastCos(angle);
PFMath::fract(x);                            // x - floor(x), without calling floorf
PFMath::ifloor(x);                           // floor as an int; floorf() is a libm CALL here
PFMath::floorF(x);                           // floor as a float, same reason
PFMath::clamp(x, lo, hi);                    // fminf/fmaxf are libm calls too
PFMath::clamp01(x);
PFMath::jsMod(x, m);                         // JavaScript's x % m (sign of x), no fmodf
PFMath::lerp(a, b, t);
PFMath::approxLength(x, y);                  // 6.8% accurate sqrt(x*x + y*y)
```

The sin LUT is 4 KB (1024 entries, ~0.35° resolution) and shared. Do not build your own.

**`floorf`, `fminf` and `fmaxf` are function calls on this target**, not instructions - GCC emits a call into libm at every use, at every optimization level. That is what `ifloor`, `floorF`, `fract`, `clamp` and `clamp01` exist for: they truncate and correct, or compare, which the FPU does in one instruction each. Removing a single `floorf` from a per-pixel path measured *smaller* object code as well as faster, because the call sequence costs more than the inline does.

`approxLength` is an octagonal sqrt approximation — 6.8% error (measured by `toolchain/check_math.py`, which pins it; the 0.375 coefficient is the shift-friendly one, not the minimax one), no `sqrtf` in the pixel loop. Use it only when distance is a **secondary** signal. If distance IS the visual structure of the pattern (radial ripples, concentric rings, vortex centers, anything that uses `1/dist` for amplification), use real `sqrtf` instead — the octagonal contour shows up as visible polygonal artifacts in those cases.

### `core_color.h` — PFColor
```cpp
PFColor::hsvToRgb(h, s, v, r, g, b);                // h is 0..1 (not degrees)
PFColor::ColorStop ramp[] = { {0.0f, 0,0,0}, ... };
PFColor::sampleRamp(ramp, count, t, r, g, b);       // POSTERISED - flat bands, no divide
PFColor::sampleRampLerp(ramp, count, t, r, g, b);   // gradient - one divide per sample
```

### `core_noise.h` — PFNoise
```cpp
PFNoise::perlin2D(x, y);                     // NOT normalised: runs to about +/-1.51
PFNoise::valueNoise2D(x, y);                 // 0..1
PFNoise::cellHash(gx, gy);                   // 0..1
PFNoise::cellHash(gx, gy, seed);             // seed decorrelates, measured
PFNoise::fractal2D(x, y, octaves, roughness);
```

The 512-byte permutation table is shared. Do not duplicate it.

### `core_ota.h` — PatternflowOta
ArduinoOTA wrapper for wireless flashing. The main sketch only needs:

```cpp
PatternflowOta::begin();   // in setup() — connects Wi-Fi if not already up
PatternflowOta::handle();  // first line of loop() — UDP poll, ~free when idle
```

Shares Wi-Fi credentials and connection with OSC (if both are enabled, the connection is reused). When `PF_OTA_ENABLED` is 0 everything compiles to a no-op. See the [OTA Updates](#ota-updates-for-developers) section below for the user-facing workflow.

### `core_improv.h` — PatternflowImprov
Self-contained [Improv-Serial](https://www.improv-wifi.com/serial/) implementation so the **browser flasher** (ESP Web Tools, behind the website's "Flash" button) can set Wi-Fi over USB right after flashing — no rebuild, no `patternflow_secrets.h`. The main sketch only needs:

```cpp
PatternflowImprov::begin();   // in setup() — announces it speaks Improv
PatternflowImprov::handle();  // in loop()  — drains Serial, drives provisioning
```

The flasher sends the SSID/password over serial; `core_wifi.h` stores them in NVS (separate `pf_wifi` namespace) and uses them in preference to the built-in `PF_WIFI_SSID/PASS` placeholders on every boot. Shares the debug USB Serial — the host parser scans for the `IMPROV` header and ignores `println()` noise. Compiled in only when Wi-Fi is actually used (one of OTA/OSC/audio enabled) and `PF_IMPROV_ENABLED` is 1; otherwise a no-op. Set `#define PF_IMPROV_ENABLED 0` in `patternflow_secrets.h` to drop it.

## Patterns

The pattern list has two tiers:

- **Presets** — the curated showcase in `presets/`, compiled into `firmware.bin`.
  Pattern 1 is always `Origin`. They work whether or not the filesystem mounts,
  and switching between them is instant.
- **Modules** — `.pfm` files on the FATFS partition, discovered at boot and
  appended after the presets. This is how new patterns normally arrive now: a
  ~3–22 KB file installed over Wi-Fi at `http://patternflow.local/patterns`,
  **no reflash, no reboot**. See [Loadable pattern modules](#loadable-pattern-modules-pfm).

Both tiers share the same pattern shape — a namespace with:
- `NAME`
- `KNOB_LABELS`
- `setup()`
- `update(float dt, const InputFrame& input)`
- `draw()` — draws via `PFCanvas::setPixel(...)` and ends with `PFCanvas::present();`

and the same foundation (`PFCanvas`/`PFMath`/`PFColor`/`PFNoise`), so a pattern
written for one tier ports to the other mechanically. The everyday way to make
one is the Pattern Lab — [`PATTERN_GUIDE.md`](../PATTERN_GUIDE.md) — which
generates conforming C++ from a JavaScript pattern and installs it over Wi-Fi;
[`CUSTOM_PATTERNS.md`](CUSTOM_PATTERNS.md) is the hands-on route.

To add a **preset** (rare — curated set): copy `_TEMPLATE.h` into
`presets/preset_<name>.h` and add one `PATTERN_ENTRY(...)` line in
`pattern_registry.h`. To add a **module** (the usual way): see the next section.

## Loadable pattern modules (.pfm)

Patterns no longer have to be compiled into the firmware image. A pattern can
be built as a relocatable Xtensa ELF module, copied to the device over Wi-Fi,
and it appears in the list immediately.

```
firmware/modules/<slug>/pattern.cpp     ← freestanding pattern source
        │  python firmware/toolchain/build_module.py firmware/modules/<slug>
        ▼
<slug>.pfm  (+ <slug>.json sidecar)     ← 3–22 KB relocatable ELF
        │  drag onto http://patternflow.local/patterns   (several at once)
        ▼
FATFS /patterns/<slug>.pfm  →  loaded on selection in ~5–11 ms
```

The design comes from Simone Majocchi (@SimonePDA), who proved the whole idea
in a working fork: a frozen C ABI between host and module, a linker script
that collapses each module to four sections, and an on-device relocator.

**How it works, briefly.** The firmware exposes a versioned function table
(`abi/pf_abi.h` — framebuffer, present, alloc, log, millis, polar tables,
libm hooks). A module is compiled freestanding against `abi/pf_module.h`
only — never against Arduino or the HUB75 driver — and partially linked with
`toolchain/module.ld` so all code lands in one contiguous `.text` with
literals inside it. At load time `core_module_loader.h` reads the ELF from
FATFS, allocates executable internal RAM, applies `R_XTENSA_32` relocations,
resolves libm/libgcc against the host's own symbols, runs `.init_array` (so
C++ global constructors work), syncs the instruction cache, and calls the
module's entry point. Switching away unloads it; one module is resident at a
time.

**Converting an existing pattern header:**

```bash
python firmware/toolchain/port_preset.py firmware/patternflow/presets/preset_origin.h
python firmware/toolchain/build_module.py firmware/modules/origin
# outputs land in firmware/patternflow/data/patterns/ — upload from /patterns
```

The port is mechanical (drop firmware includes, add `#include "pf_module.h"`,
append `PF_REGISTER_PATTERN(Namespace)`); the body is copied verbatim because
the module SDK provides the same `PFCanvas`/`PFMath`/`PFColor`/`PFNoise`
surface — the math headers are literally the same files, included with
`-DPF_MODULE_BUILD`.

**Install paths**, easiest first:
- Community cart → "Send over Wi-Fi": opens `/patterns?src=<modules-url>`, and
  the page fetches and installs every file itself. Nothing downloaded.
- Drag any number of `.pfm`/`.json` files onto `/patterns` — a visible queue
  uploads them one by one with progress, retries, and per-file results.
- `curl -F "module=@slug.pfm" http://patternflow.local/api/patterns` for scripts.

**Costs and limits, measured on hardware** (v3.2, 2026-07, 128×64, esp32 core 3.3.8 build — a core 2.x build has more heap and renders faster; see [How to measure this](#how-to-measure-this-before-reading-it)):

| Property | Measured |
|---|---|
| Switch latency (7.5 KB module) | 6.0 ms = read 4.4 + relocate 0.6 + setup 1.0 |
| Switch latency (22 KB module) | 10.9 ms — still under one 60 fps frame |
| Runtime speed vs the same source compiled in | **~20 % slower** (Origin: 53.4 → 43.5 fps) — the cost of relocatable code (`-mlongcalls`); not fixable by `-O2` (~2 %) or memory placement |
| Comfortable module size | ~32 KB of statics on a core 2.x build — measured: 0–64 KB of static tables all render at the same 62 fps, they just spend heap. (The old "≲ 8 KB, then `.rodata` spills to PSRAM and ~14 fps" figure was the core 3.x build's 7.7 KB largest block talking; see [Required board package](#required-board-package).) |
| Panel size | Baked in at build (`-DPF_PANEL_W/H`); the loader rejects a mismatch |
| ABI | `PF_ABI_VERSION` must match; bump it on ANY layout change in `pf_abi.h` and rebuild every module |

If a module fails to load, nothing else is affected — the presets and other
modules keep working, the panel shows a `PATTERN FAILED` screen with the
reason, and `/api/status` reports it as `loadError`. Check `loadError` first
for any "this pattern is broken" report — it turns a vague complaint into a
specific one.

`unresolved symbol: X` used to be the usual cause, and it is worth knowing
what it cost before it was closed: the table carried `tanhf` but not `coshf`,
and since sech(x) = 1/cosh(x) is the closed form of a soliton, an entire
genre of wave patterns failed to load in a way that read as "too heavy for
the board". As of **v3.5.2** the table was audited in bulk — every shipped
module's demand plus a synthetic probe of the whole libc/libm surface
(hyperbolics, erf, the rintf family, 64-bit integer helpers, qsort/strto*,
string/ctype, an atexit shim) — and `build_module.py` now checks every
`.pfm` it links against the loader's own table, so a pattern the device
would refuse fails **on the build machine with the missing names spelled
out**. If a new name ever does surface, the fix is still one
`PF_HOST_SYMBOL` line in `resolveHostSymbol()` — add it there and the build
checker learns it automatically, since it parses that header.

**Pattern names are UTF-8.** "Dynamic Moiré" and "Poincaré Sphere" are real
entries in the library, and an accent used to break three layers at once: the
toolchain scripts printing a name on a cp949 console, a loader guard that
tested names for printable ASCII and called anything else a relocation bug,
and the panel's 5×7 ASCII font. Names stay UTF-8 in the ELF and in every JSON
API; only the panel folds them (`asciiFold()` in `patternflow.ino`). Any new
code that touches a name must assume UTF-8.

### How many can you install

Installing costs nothing at runtime. The registry allocates its arrays at full
capacity on boot, in PSRAM, whether or not the modules exist — so five
installed modules and 128 installed modules use exactly the same RAM. Only the
**resident** module costs internal RAM, and unloading returns all of it
(measured: 4,548 B free with a module resident → 11,692 B on a preset).

| Limit | Value | Binding? |
|---|---|---|
| Installed modules | **128** (`MAX_MODULE_PATTERNS`) | The only real cap, and it is a UX choice — 136 B of PSRAM per slot, 17 KB total |
| Storage | ~1,500 modules (10.2 MB partition, 5.9 KB median) | No — 12× the count cap |
| Per-module RAM | ~32 KB of statics comfortable on a core 2.x build (0–64 KB measured at identical fps; the old ≲ 8 KB figure was the core 3.x heap talking) | Heap only — frame rate does not move |
| Concurrent modules | 1 | By design — one pattern is selected at a time |

A large module only costs while it is the selected pattern; it has no effect
on the presets or on any other module. On the core 3.x build a resident
module dropped `heapLargest` to ~3 KB — which is what made opening a console
page pause the pattern; on the core 2.x release build the same module leaves
~65 KB and the console stays comfortable (the pause-on-open mechanism remains,
see the constraints section below).

Measured across the real 42-pattern community library: median `.pfm` 5,924 B,
largest 17,512 B, smallest 4,612 B, 281 KB for all 42 together.

### How to measure this, before reading it

`heapLargest` is not a property of a build. It decays as the device serves
HTTP, in steps of exactly 2,048 B — polling a build eighteen times walks it
down ~4 KB — so **a firmware sampled often reads worse than one sampled
rarely**, and two numbers taken over different windows do not compare.

Take it this way, or do not quote it:

> flash → `POST /api/wifi/reboot` → wait ~80 s → **one** read of `/api/status`

Two names that mean different things, and have already been mixed up here:

- **Flash.** The toolchain's figure is program storage (1,412,457 = 44.9 % of
  the 3,145,728 B partition). The `.bin` on disk is ~360 B larger — header,
  padding, hash. Say which one you mean.
- **RAM.** The build's `92,920` is static RAM *used*, 28.4 % of 327,680. Free
  internal heap is a different number and only the running device knows it.

And the rule the rest of this section exists to serve: **a heap number
travels with its build, its procedure and its date, or it is not evidence.**
The figures below are v3.5.2 on a core 2.x build and are quoted as history —
the [September 2026 runtime report](../docs/investigations/2026-09-firmware-runtime.md)
has the 3.10 numbers, taken under the protocol above. In 2026-08 the `86,004` below was copied into five
documents as a measurement of something else entirely.

### Current state (v3.5.2, measured on hardware, core 2.x build)

| | |
|---|---|
| Frame time, preset (Origin) | ~16,270 µs = **61.5 fps** |
| Internal heap, preset resident | 96,324 B free, largest block 86,004 B |
| Internal heap, module resident (Muybridge 35mm, 29 KB `.pfm`) | 76,668 B free, largest block 65,524 B — 48.5 fps |
| PSRAM | 8.33 MB idle |
| Flash | 1,148,960 B = **37 %** of the app partition |
| Globals | 84,660 B = **26 %**, 243 KB left for locals |
| Pattern storage | 131,072 / 10,235,904 B with 13 modules installed |
| Leak check | 48 consecutive page loads: **−8 B** net, largest block unchanged *(v3.1.0 measurement; not re-run since)* |

The v3.1.0 / core 3.x numbers this table used to carry — 53.4 fps, 11.7 KB
free, 7.7 KB largest block — are what the constraints section below calls the
other build. Anyone comparing a measurement against this table should first
check which core their firmware was built with.

## Adding features — the constraints that matter

Read this before adding anything to the firmware. Every item here was learned
the expensive way, with measurements to back it.

### Internal RAM is the budget. Everything else is roomy.

The ESP32-S3 has 512 KB of internal SRAM, but what a feature can actually
claim is far smaller:

```
≈320 KB   Arduino data region (of 512 KB SRAM; rest is cache/ROM/RTOS)
 −92 KB   this firmware's globals (24 KB canvas, fonts, module state…)
 =213 KB  free heap at boot                          ← measured, core 2.x
 −150 KB  HUB75 DMA framebuffers (see below)
 −49 KB   Wi-Fi socket buffers, HTTP, OSC, mDNS…
 ≈ 15 KB  steady-state free internal heap
```

**That last line is a build choice, not a hardware limit.** The figures above
are the core 3.x picture. Core 2.x gives back roughly 71 KB that IDF 5 takes
before `setup()` even runs, so the same firmware idles at **~98 KB free,
90 KB largest block** — see [Required board package](#required-board-package).
Build on core 2.x and the numbers below stop being the constraint they were.
Build on core 3.x and they are real, so know which one you measured on before
concluding a feature is too expensive.

Below roughly **10 KB free**, the web console starts failing in a maddening
way: every endpoint returns its status line and then hangs, while Wi-Fi, OSC
and OTA look perfectly healthy. A 7 KB static array added during development
took down four unrelated pages at once. So:

- **Static buffers are guilty until proven innocent.** If data is written at
  boot and read occasionally — lists, tables, names — allocate it from PSRAM
  (`heap_caps_calloc(1, size, MALLOC_CAP_SPIRAM)`). There are **8 MB** of
  PSRAM sitting idle; the pattern registry lives there for exactly this
  reason. Reserve internal RAM for hot loops and DMA.
- Check `/status` (or `/api/status`) after your change: it reports free
  internal heap, largest block, and PSRAM live from the device.

### Why HUB75 owns 150 KB and it cannot move

HUB75 panels have no framebuffer of their own and only understand on/off per
pixel. The driver therefore streams the whole frame continuously (the panel
lights 2 rows at a time) and achieves 256 brightness levels by re-sending the
frame as 8 binary-weighted bit-planes (BCM). That waveform is what DMA plays
out autonomously:

```
128 cols × 32 row-pairs × 2 B = 8 KB per bit-plane
× 8 bit-planes                = 64 KB per frame buffer
× 2 (double buffering)        = 128 KB  (+ descriptors ≈ 150 KB)
```

It must be internal RAM — PSRAM's latency jitter glitches the 15 MHz stream.
Shrinking it costs image quality directly (6-bit color = banding in exactly
the gradients these patterns live on; single buffering = tearing). This is
the standard tax every ESP32-driven HUB75 project pays; in exchange, refresh
costs zero CPU and the render loop effectively owns a core.

### The Arduino WebServer will hurt you. Known landmines:

> **Writing a client rather than a route?** The endpoints, their JSON shapes and
> the rules that follow from this section are specified in
> **[docs/rest-api.md](../docs/rest-api.md)**. Build against that file; this one
> explains *why* the server behaves as it does, which is what you need when
> adding to it.

The console shares **one** synchronous, single-client `WebServer` on port 80
(owned by `core_audio_ws.h`; other features attach routes to it). Learned so
far, each confirmed by A/B on hardware:

1. **A multipart POST with a URL query string gets an empty reply.** Send
   flags as form fields instead (`fd.append('last', …)`), never `?last=1` on
   an upload.
2. **Never do heavy work inside a request handler.** A FATFS rescan + module
   reload inside the upload handler crashed the device mid-batch — and the
   crash corrupted the FAT. Handlers set a flag; `tick()` functions called
   from `loop()` do the work ~150 ms later (see `core_patterns_http.h`).
3. **Never force-close connections from the server** (`client().stop()`).
   Each server-initiated close parks a TCP pcb in TIME_WAIT; after a couple
   of upload batches every multi-chunk transfer died until reboot.
4. **Rapid sequential uploads flake ~1 in 12** even when healthy (dead reply
   after the file was stored). Client pages pace files ~350 ms apart and
   retry each file twice; re-uploading is harmless (same bytes, same name).
5. **Never auto-format the filesystem on a failed mount.** A crash mid-write
   once corrupted the FAT and the "helpful" auto-format erased every
   installed module. Mount failure now means presets-only; formatting is an
   explicit button (`POST /api/patterns/format`).

6. **A response larger than ~5.6 KB needs the heap a loaded module is
   holding.** This one looked for a long time like a slow "leak" that
   degraded over hours; it is not. Measured on one device, one minute apart:

   ```
   module resident    internal heap  4,932   /patterns truncated at 5,633 B
                                             after a 10 s stall
   module unloaded    internal heap 11,852   /patterns whole (15,903 B), 0.43 s
   ```

   5,633 B is four TCP segments — one bufferful. Under a starved heap the
   one-shot `send()` fills that and gives up, and the client waits out the
   timeout holding half a page. The HTML renders, its script is cut
   mid-statement and never runs, and the console looks blank while every API
   underneath answers fine.

   Until 3.6.3 the console therefore **paused the pattern**: opening a page
   evicted the module and restored it after 25 s of silence. Since 3.6.3 the
   page sender streams PROGMEM in small slices under a 5-second budget, the
   pages are gzip-compressed, and the core-2 builds have the heap for it, so
   a page no longer evicts anything; `status.consolePaused` now means only
   that a pattern-install batch is in progress ([`docs/rest-api.md`](../docs/rest-api.md)).
   The memory wall below is still real, and is why pages stay small.

   **This is a memory wall, not a pacing problem.** It is tempting to read
   the 10 s stall as impatience — `NetworkClient::write()` really does send
   with `MSG_DONTWAIT` and give up after `WIFI_CLIENT_MAX_WRITE_RETRY` (10)
   non-writable selects of 1 s each, which is where the ten seconds comes
   from. Rewriting the send path to be patient does not help, because the
   number that matters is `heapLargest`: **3,060 bytes** with a module
   resident. lwIP cannot allocate the pbufs, and no amount of waiting
   creates them.

   Three fixes were tried on hardware and **do not work**; do not retry them:
   - Spilling module data sections to PSRAM to spare internal RAM — reboots
     the device the moment a module is selected.
   - Chunked transfer encoding — delivers *less*, not more (one 1 KB chunk,
     or nothing), with or without pacing between chunks.
   - 512-byte slices with a wall-clock deadline instead of a retry count
     (`core_http_send.h`, reverted in bb8e52c) — delivers **3,072 B**, worse
     than the 5,633 B it replaced, and still takes the full 10 s. It *is*
     ~3× faster than `send_P` on a healthy heap, which is exactly the trap:
     it measures beautifully in the condition that was never the problem.

   An async server (ESPAsyncWebServer or esp-idf httpd) would lift the
   one-client and upload-pacing limits, but it shares this same lwIP heap —
   do not expect it to make a 16 KB page deliverable on a 4.5 KB heap. The
   only real levers on page delivery are using less internal RAM per module
   or shrinking the pages.

### Adding a console page

The pages are plain HTML in [`patternflow/console/`](patternflow/console/); edit them there, preview with `console_serve.py`, and `console_pages.py build` splices them into the `*_index.h` headers — the whole workflow is [`patternflow/console/README.md`](patternflow/console/README.md). A page that belongs to a feature travels with the feature (`navPath`/`navLabel`/`navDesc` in its descriptor); the core never names it. Two rules that the README does not repeat:

- **Syntax-check the page's JavaScript before flashing**: extract the `<script>` body and run `node --check` on it. A single stray newline in a string once shipped a page whose script never ran — the page rendered but showed nothing, which reads as "the device is broken".
- **Never leave the render loop with nothing to draw.** If a screen decides not to paint, set `frameDrawn = false`; flipping an unpainted buffer shows a torn leftover frame, which every tester reads as "the pattern is broken".

### What is cheap and what is expensive here

Cheap (fits the platform well):
- **Wired OSC over USB-C** — the S3's native USB does CDC serial out of the
  box; OSC 1.1 over SLIP is a standard TouchDesigner/Max speak. Reuses the
  existing OSC message parser with a different transport. Near-zero RAM,
  independent of Wi-Fi entirely. A very good first contribution.
- More device pages, more OSC addresses, more module-SDK helpers (add the
  symbol to the host table + bump nothing, if it's a new function on
  `PFHostAPI` — that's an ABI bump).
- Anything whose cold data can live in PSRAM.

Expensive (think twice, or push to "Remote compute"):
- TLS clients/servers (tens of KB of internal RAM per connection).
- Many concurrent WebSockets or HTTP clients (single-threaded server today).
- Anything needing large always-resident internal-RAM buffers — that budget
  is 15 KB, total, shared with everyone.

## Configuration (`config.h`)

All hardware-specific pins and limits are centralized in `config.h`.
- **Panel Selection:** `PANEL_PROFILE` picks the driver-init path — `PANEL_STANDARD` (no init; the default and what the browser flasher ships), `PANEL_HIGHREFRESH` (FM6126A), `PANEL_FM6124`, `PANEL_ICN2038S`, `PANEL_MBI5124`, `PANEL_DP3246`. It expands to the `HUB75_DRIVER` value `core_display.h` passes to the library. **Don't set it by part number — leave it at `PANEL_STANDARD` unless the panel comes up completely dark.** The init sequence only writes a brightness register and an output-enable bit; many panels ship with those already usable, and the reference panel's FM6124 runs fine without it. A panel that genuinely needs a different profile needs one custom build. Full buyer's guide: [docs/panel-compatibility.md](../docs/panel-compatibility.md).
- **Pin Mapping:** Adjust the `R1_PIN`, `ENC1_A` etc. if you are not using the official Patternflow PCB.
- **Hardware Settings:** `INVERT_ENCODER` can be toggled depending on whether you mounted your encoders on the front or back of the PCB. `DEFAULT_BRIGHTNESS` controls the initial matrix brightness.

### LED panel calibration
LED panels render the same RGB triplets differently than a calibrated monitor — the LED primaries are at different wavelengths than sRGB phosphors, red LEDs are brighter per PWM duty than blue, and the panel reads washed-out next to a monitor showing the same frame. The defaults are the ones that ship in `config.h` (saturation tuned by eye on 2026-08-09 against the Calibration preset, on the maintainer's panel; white balance is identity since 2026-09-17, when the bit-plane weights were made binary and the earlier trim turned out to have been correcting the driver rather than the panel); every value is `#ifndef`-guarded, so a panel can override any of them from `patternflow_secrets.h`:

```cpp
#define LED_GAMMA_R   1.0f    // the pow-LUT already handles perceptual response;
#define LED_GAMMA_G   1.0f    // extra gamma here only made the panel darker
#define LED_GAMMA_B   1.0f
#define LED_WB_R      1.000f  // identity: the reference panel reads neutral uncorrected.
#define LED_WB_G      1.000f  // Judge a trim on the GRAYS screen, not on white alone
#define LED_WB_B      1.000f
#define LED_SAT_BOOST 1.62f   // strong: matches design intent on real patterns
```

Tune live from `/api/display` (the `/status` page has the sliders), then land the converged numbers in your secrets file. The comments in `config.h` above each value record how they were arrived at.

### Refresh rate (anti-flicker for video)
`core_display.h` sets the refresh floor, and the vendored driver lands the panel on **exactly 300 Hz**:

```cpp
mxconfig.i2sspeed         = HUB75_I2S_CFG::HZ_15M;  // pixel clock — see below, this is 16 MHz
mxconfig.min_refresh_rate = 240;                      // refresh floor (shipped: exactly 300 Hz)
mxconfig.latch_blanking   = 2;                        // brightness uniformity
```

> **The library's clock enum names are wrong.** `HZ_15M` is `16000000` and `HZ_10M` is `8000000` — `HZ_8M` and `HZ_10M` are the same value, and there is nothing between 8 and 16 MHz. Read the enum, not the name, and if you are hunting harmonics on a spectrum analyser the fundamental is at **16 MHz** (so 96, 112, 128, 144, 160 MHz…), not 15.

A HUB75 panel lights one row pair at a time: each row is on for 1/32 of a refresh and dark for the rest — a short pulse, not a glow. A phone's rolling shutter exposes each sensor line for the same length of time but starting a little later than the one above, so each line collects a whole number of those pulses. If the exposure is an exact multiple of the refresh period, every line collects the same number and the picture is clean. If it is not, some lines get N pulses and some N + 1, and that is the banding you see on video — its contrast is about 1/N, and how much of the picture it covers depends on how far the exposure is from a whole number of periods. A faster refresh makes the bands fainter and *more numerous*; it does not make them go away.

Exposure times are not arbitrary, though. To dodge mains flicker a phone pins them to 1/50, 1/100, 1/25 (50 Hz countries) or 1/60, 1/30 (60 Hz countries), and **300 Hz is the lowest rate all of those are whole multiples of**. The shipped chain would naturally run at 325.5 Hz — nearly the worst case for 1/50 (6.51 periods) and 1/60 (5.43) — so the driver ends every frame with 4,181 blank clocks, output off, to make it 16 MHz / 300 = 53,333 clocks exactly (`PF_TARGET_REFRESH_HZ` in `src/hub75/`, 0 to switch off; it never pads below `min_refresh_rate`). About 8% of the light, and no CPU: refresh runs on the ESP32-S3's DMA hardware in parallel with everything else.

What 300 Hz cannot fix: **1/120 and faster, and slow motion.** At 1/120 an exposure is 2.5 periods — the worst case — and the rate that would cover it, 600 Hz, is out of reach of a 16 MHz clock at 8 bits. When filming: lock the shutter at 1/60 or 1/50 (a manual camera app, or pro mode), or turn the panel *down* so the phone lengthens its exposure; lock white balance and focus; switch HDR and night modes off.

The trade-off is brightness. A row is sent as a chain of bit-plane buffers, and the vendored driver picks the brightest chain that still clears `min_refresh_rate` (`pfChainExtraPasses` in `src/hub75/`, and `VENDORED.md` beside it for why the chain is not upstream's). Every scheme is exactly binary — colour depth is never what gets sacrificed — but a shorter chain keeps less of each row lit. **Both settings move together — you cannot lower one without deciding about the other.** On the reference panel (128×64, 8-bit):

| `i2sspeed` | `min_refresh_rate` | Chain | Row lit | Actual refresh |
|---|---|---|---|---|
| 16 MHz | 240 *(shipped)* | scheme 0, 12 buffers, padded | 61% | 300 Hz exactly |
| 8 MHz | 240 | scheme 2, 8 buffers | 25% — **dimmest** | ~244 Hz |
| 8 MHz | 200 | scheme 1, 9 buffers | 44% | ~217 Hz |
| 8 MHz | 150 | scheme 0, 12 buffers — same as shipped | 66% | ~163 Hz |

So if you drop the clock, **drop `min_refresh_rate` with it** — halving the clock while leaving 240 in place is the worst of both worlds, giving up most of the panel's light to claw back a refresh rate you were not going to keep anyway. Banding on *video* of the panel is a matter of shutter against refresh, as above — at 8 MHz the frame is already longer than 1/300 s, nothing is padded, and the rates in the table are what you get. (The 8 MHz rows are computed from the chain lengths, not re-measured since the chain changed; the 16 MHz row is what the panel reports.)

> **Lowering the panel clock is also an EMI knob**, and it has been measured. 8 MHz improves Wi-Fi latency on the reference unit (median 15 → 4 ms) and one contributor found it was the difference between a usable and an unusable radio on their board — but at any `min_refresh_rate` that preserves colour depth it bands on video, so it is not shipped. Full measurements, the parts that cannot be adopted (do **not** raise the Wi-Fi TX power — it is a conformance setting), and what to try first if your unit's Wi-Fi is bad: [docs/investigations/2026-08-the-panel-clock-and-the-wifi-radio.md](../docs/investigations/2026-08-the-panel-clock-and-the-wifi-radio.md).

## Controls

The four rotary encoders control pattern-specific parameters. Each pattern exposes its own labels through `KNOB_LABELS`.

For the original defaults:
- **Encoder 1:** Hue
- **Encoder 2:** Speed
- **Encoder 3:** Mode/Preset
- **Encoder 4:** Frequency

### Longpress actions
- **Encoder 1 longpress (≥1s)** — enter/exit global brightness mode. While active, K1 rotation adjusts panel brightness (5–255, ~5 per detent), the active pattern does not see K1 input, and a "BRIGHTNESS XX%" overlay shows the current level. Exits on a second longpress or after 5 seconds of idle. Value persists across reboots via NVS.
- **Encoder 2 longpress (≥1s)** — enter/exit the NETWORK screen (portrait status view: Wi-Fi state, local IP, OSC on/off and its remote host/port, audio-react on/off). Inside the screen, settings are toggled by **knob rotation, not clicks** — right = ON, left = OFF — so that holding K2 to leave can't flip anything on the way out:
  - **turn K2** → OSC send/receive on/off (persists in NVS, so the device reboots into the same state). Wi-Fi stays connected either way; the toggle only enables/disables traffic. If the firmware was built with `PF_OSC_ENABLED 0` the row still shows but the toggle is inert ("REBUILD WITH PF_OSC_ENABLED=1").
  - **turn K3** → audio-react on/off (also persisted).
  - **turn K1** → sleep (see [Sleep mode](#sleep-mode) below). Either direction, unlike the toggles above: the screen is about to go dark, so "right = on" has nothing to mean.
  - **turn K4** → hand off to the UPDATE screen, which arms the `/update` endpoint (the arming *is* the security model — see `core_web_update.h`).

  Exits on a second K2 longpress, a **K2 click**, or after 8 seconds of idle.
- **Encoder 3 longpress (≥1s)** — enter/exit the KNOB MAP screen: it shows which physical knob is which number (front view: K1 top-right, K2 top-left, K3 bottom-right, K4 bottom-left), and turning any knob lights its digit green so each one can be verified without leaving the screen. Knob input is swallowed while it's up, so the pattern underneath never sees it. Exits on a K3 click, a second K3 longpress, or after 8 seconds of idle.
- **Encoder 4 longpress (≥1s)** — enter/exit pattern SELECT mode. In SELECT mode, K4 rotation moves the highlight through the list — three detents per pattern, so a hand does not overshoot — and the panel shows each pattern's **thumbnail** (the frame it last drew, kept from the last time it ran); the highlighted pattern loads once the knob has rested for a third of a second — on the other core, so the knob keeps answering while a heavy pattern's setup runs — then runs live behind the overlay. A pattern that has never run shows nothing but its name until it has. Longpress again to confirm — a choice the knob was still resting on loads right then.

Thumbnail ownership follows the frame boundary too: the loop owns the PSRAM
cache, and the existing network task reads/writes one immutable job at a time.
Capturing a picture copies pixels; it opens no file. A completed read is adopted
between frames, and deletion/format invalidates jobs by generation. The optional
cache and its one 16 KB work buffer use PSRAM exclusively; allocation failure
leaves the name-only preview. No extra task stack is reserved. This separation
does not shorten a module's own `setup()`; the asynchronous loader still handles
that wait. `/api/status.thumbs` separates capture cost from background I/O cost.

### One detent, one step
Knob deltas are linear: a pattern sees exactly the number of detents that were turned, however fast the turn was.

There used to be a fast-spin multiplier here (×2 to ×5 as the gap between detents shrank), meant to let one knob sweep a wide range quickly. It was removed after testing against a linear build, because it made the knobs unpredictable on exactly the parameter that most needs landing on a value — Origin's Mode knob picks a discrete preset, and a quick turn skipped five at a time. OSC had already been routed around the multiplier for the same reason, which was the tell.

**If a pattern's range feels slow to cross, raise that pattern's own step constant** (`d * 10` → `d * 25`). Linear and predictable beats a curve guessing at intent.

### Short press (per-pattern, opt-in)
There is no global short-press handler. Each pattern decides what `K1..K4 short press` does for itself, by reading `input.btnPressed[i]` inside its `update()`. The built-in patterns (`Origin`, `Wave Saw`) use short press to reset the corresponding parameter to its default. A pattern that does not handle `btnPressed` — most of the curated presets — simply ignores short presses.

When you generate a new pattern from the Live Editor, the conversion prompt does not force a particular short-press convention — if you want one, either ask for it in the prompt ("K1 short press resets hue") or add the line by hand in `update()`.

## Sleep mode

`src/core_sleep.h`. The panel goes dark and the board idles, without anything being unplugged, and it stays **on the network** the whole time.

That last part is the design decision. `esp_deep_sleep` would take the draw to microamps, but it takes the radio with it, and then the only way back is a button — which is exactly what "switch the lights off from the sofa" needs not to be true. So sleep here means:

| | |
| :--- | :--- |
| **Panel** | framebuffer blanked, brightness 0, HUB75 DMA transfer stopped |
| **Wi-Fi** | modem sleep — still associated, wakes on its DTIM beacon |
| **CPU** | 80 MHz, the floor at which the radio still works |
| **`loop()`** | returns early and yields 20 ms; no render, no flip, no power clamp |

Stopping the DMA transfer is what makes this worth more than blanking. The LEDs are most of the draw and blanking collects that, but with the transfer running the panel's driver ICs are clocked at 15 MHz forever, lit or not. `core_power.h` puts that idle floor at ~550 mA against ~1900 mA for a bright pattern.

The yield is not politeness either: without it the sleeping loop polls sockets flat out and the core never idles, so neither modem sleep nor the IDF's clock gating gets a chance.

### Entering and leaving

| Enter | Leave |
| :--- | :--- |
| the **On / Sleep** switch on the console home page (`/`) | the same switch |
| NETWORK screen (hold K2) → turn K1 | any **physical** knob turn or button press |
| MQTT `<prefix>/sleep` ← `1` / `on` / `true` / `sleep` / `toggle` | same topic ← `0` / `off` / `false` / `wake` |
| `POST /api/sleep` ← `on=1` (also `on=toggle`) | `POST /api/sleep` ← `on=0` |
| | a firmware image starting to arrive (web update or `espota`) |

"Physical" is meant literally: waking checks the raw encoder counters, not `input.knobDeltas`, because remote OSC/MQTT/audio deltas are merged into that field by the time the input frame exists. A show still streaming knob values at a sleeping panel must not switch the lights back on. Input is ignored for the first 800 ms so the second detent of the K1 turn that started the sleep doesn't end it.

Sleep is never entered while an image is being written to flash, and a device already asleep wakes when one starts arriving — whoever is flashing wants the UPDATE screen anyway.

The state is **not** persisted: a device unplugged while asleep boots awake, because a panel that stays dark after you plug it in reads as broken.

### Waking gives the pattern back

The one thing that still evicts the resident module is a pattern-install batch (a console page has not since 3.6.3). So a wake — from *any* of the three sources, not just the web switch — asks for the pattern back via `PatternflowPatternsHttp::requestReload()`, the same path the console's Play Now button uses, and gets it whether or not something was holding it. The reload happens at the frame boundary from `loop()`, never inside an HTTP transaction.

### The switch, and why `/api/sleep` is its own endpoint

The console home page carries an **On / Sleep** pair in the device card, styled like `/mqtt`'s channel buttons — the console's existing way of picking between states. It is a *view* of the device's state: K1 and MQTT change the same thing, and the page's 3-second `/api/status` poll follows them within a beat.

`POST /api/sleep` only *queues* the transition (`PatternflowSleep::request()`), so its reply reports the state as it stands, not as it will be — stopping a DMA engine and reclocking the CPU belong in `loop()`, not inside an open response. The page therefore paints optimistically and suppresses the poll for 1.5 s, or the reply would snap the switch back under the cursor.

Sleep control deliberately does **not** live on `/api/display`, where the plumbing first landed. That endpoint is independently compile-out-able (`-DPF_DISPLAY_HTTP_ENABLED=0`), which would leave the switch dead in a build with an otherwise complete console — and sleep is a power state, not a display calibration. `/api/display` still *reports* `sleep`, read-only, because a dark panel is the first thing to rule out while tuning.

### MQTT

`<prefix>/sleep` is obeyed in **either** role, unlike the knob and pattern topics — a panel set to Publisher is still a panel you want to be able to switch off. It is a broadcast for the same reason `<prefix>/message` is: one `1` on a shared prefix sleeps every panel on it. Give a panel its own prefix if that is not what you want, and send the command non-retained unless you really do want panels coming back asleep after every reconnect.

The device publishes `<prefix>/sleep/state` (`0` or `1`, non-retained) on every change and once per connection — enough for a Home Assistant switch.

```bash
mosquitto_pub -h <broker> -t patternflow/sleep -m 1
mosquitto_sub -h <broker> -t 'patternflow/sleep/state'
```

Unrecognised payloads are ignored rather than guessed at; a typo should not black out a panel.

### Compile-time flags (`config.h`)

| Flag | Default | Meaning |
| :--- | :--- | :--- |
| `PF_SLEEP_ENABLED` | `1` | compile the feature in at all |
| `PF_SLEEP_STOP_DMA` | `1` | stop the HUB75 transfer, not just blank. **Set to 0 if the panel comes back black or garbled after waking** — sleep then blanks only, which is safe on any panel and still saves the LED current |
| `PF_SLEEP_CPU_MHZ` | `80` | clock while asleep; `0` disables the switch |
| `PF_AWAKE_CPU_MHZ` | `240` | clock restored on wake |

`PF_SLEEP_STOP_DMA` depends on `resumeDMAoutput()`, a Patternflow addition to the vendored HUB75 driver — upstream's `stopDMAoutput()` is a one-way trip. See `src/hub75/VENDORED.md`.

## Remembering the selected pattern

The pattern you left running comes back after a sleep and after a full power cut. It is stored in NVS as a **slug**, not an index: installing or deleting one `.pfm` renumbers the whole list, so an index would come back as somebody else's pattern. Resolution on boot goes through `findPatternByName()` in `pattern_registry.h`, which matches display name and slug alike.

The write is debounced — it waits until SELECT mode is left and the choice has been still for 3 seconds — so spinning K4 through fifty patterns is one NVS write, not fifty. Brightness has used the same shape for longer.

A remembered pattern that is gone, or that no longer loads, falls back to Origin with a log line. The PATTERN FAILED screen is the right answer for a pattern somebody just picked and the wrong one for a boot: nobody asked for it in this session.

## Audio-react, OSC, MIDI, MQTT

None of these is in the core. They are features, and each ships in an edition you install from [the shelf](https://patternflow.work/editions): audio-react, OSC and network MIDI in **Audio**, MQTT in **Performance**. What a client sends is a written contract in `docs/` — [`audio-ws-spec.md`](../docs/audio-ws-spec.md), [`osc-spec.md`](../docs/osc-spec.md), [`midi-spec.md`](../docs/midi-spec.md), [`mqtt-spec.md`](../docs/mqtt-spec.md) — and the guides are [`AUDIO_GUIDE.md`](../AUDIO_GUIDE.md) (sound in, MIDI, OSC) and [`docs/midi-ableton.md`](../docs/midi-ableton.md). The ready-made clients are the audio extension and phone app in [`tools/`](../tools/README.md) and the Max for Live bridge in [`integrations/ableton/`](../integrations/ableton/).

From a pattern's point of view every one of them is the user turning the four encoders: audio bands, OSC deltas and MIDI CCs arrive as `knobDeltas` (or pin a lane on the absolute parameter bus), so an encoder-driven pattern reacts with no transport-specific code.

Two switches, for a local build:

- **Compile-time** — whether a feature is linked in at all is the bundle: `firmware/bundles/<edition>/features_local.h` lists the features an edition carries ([`bundles/README.md`](bundles/README.md)). A feature's own tunables live in `features/<name>/<name>_config.h` (the audio WebSocket port and knob scale in `features/audio/audio_config.h`, the OSC ports in `features/osc/osc_config.h`, the broker defaults in `features/mqtt/mqtt_config.h`), every one `#ifndef`-guarded so a line in `patternflow_secrets.h` wins. `PF_OSC_ENABLED 0` in the secrets file compiles OSC out of an edition that would otherwise carry it; the K2 info screen then shows `OFF (compile-time)`.
- **Runtime** — once compiled in, OSC and MIDI are switched on and off from the panel's NETWORK screen (hold K2), the state saved in NVS; the K2 screen shows `WAIT HOST` until the first OSC packet teaches the panel your computer's address.

## Wireless update from the browser

Once the device is on Wi-Fi, it can flash itself from any browser on the same network — no Arduino IDE, no USB cable, no TLS setup ([#232](https://github.com/engmung/Patternflow/issues/232)).

1. Get a firmware `.bin`: build one on [patternflow.work](https://patternflow.work) and hit *Download .bin*, or export one locally (`arduino-cli compile --output-dir …` — use the app image, not a merged full-flash image).
2. Open `http://patternflow.local` — the device serves a small console (audio sync / firmware update) — and pick **Firmware Update**, or go straight to `/update`. If `.local` doesn't resolve (common on Android), use `http://<ip>/update`; the device shows its IP on the NETWORK screen (hold K2) and on the UPDATE screen.
3. Drop the `.bin` on the page. The panel shows flash progress; the device verifies, reboots, and comes back on the new firmware in about ten seconds.

Notes:

- **Uploads are accepted at any time by default** (`PF_WEBUPDATE_ALWAYS_ARMED 1`): drop a .bin whenever, no trip to the device. The flip side, stated plainly: anyone on the same Wi-Fi can flash the device from a phone browser — the same exposure ArduinoOTA's no-password default already has. On shared, office, or exhibition Wi-Fi, build with `#define PF_WEBUPDATE_ALWAYS_ARMED 0` in `patternflow_secrets.h`: uploads are then refused (`403`) unless the UPDATE screen is open on the device (hold **K2** → NETWORK, turn **K4**) — a physical arming switch only someone at the device can flip; leaving the screen (K4 click, or the 10-minute idle timeout) disarms it again.
- A failed or interrupted upload leaves the old firmware running — `Update.h` only switches the boot partition after a complete, verified image. Power loss *during* the flash write is the one case to avoid; the panel says so while flashing.
- Like all wireless paths, this capability has to arrive over USB once (it ships in the stock release).
- Set `#define PF_WEBUPDATE_ENABLED 0` in `patternflow_secrets.h` to compile it out.

## OTA Updates (For Developers)

The firmware includes `ArduinoOTA` for wireless flashing from the Arduino IDE — no USB cable, no port juggling.

### One-time setup
1. Copy `patternflow/patternflow_secrets.example.h` to `patternflow/patternflow_secrets.h` and fill in your local Wi-Fi credentials:
   ```cpp
   #define PF_WIFI_SSID "your-wifi-name"
   #define PF_WIFI_PASS "your-wifi-password"
   ```
   (You don't need to enable `PF_OSC_ENABLED` — OTA brings up Wi-Fi on its own. One secrets file now covers Wi-Fi, OTA, OSC, and audio-react.)
2. Flash once over USB as normal. On boot, the serial console should print:
   ```
   [OTA] Ready — hostname "patternflow.local", IP 192.168.x.x
   ```

### Subsequent uploads
1. In Arduino IDE, open **Tools → Port** — you should see `patternflow at 192.168.x.x (ESP32)` alongside the USB ports.
2. Select that network port and hit Upload. The IDE compiles, pushes over Wi-Fi, and the device reboots into the new firmware.
3. Progress prints to serial as `[OTA] 47%` etc.

If the network port doesn't appear, make sure your computer and the device are on the same Wi-Fi subnet, and that no firewall is blocking mDNS (UDP port 5353) or the OTA port (3232).

### The upload-password prompt (and how to avoid it)
The firmware ships with **no OTA password** (`PF_OTA_PASSWORD ""`), so the device never challenges for one. But **Arduino IDE 2.x always pops a password dialog for network ports and refuses an empty field** — that's an IDE limitation, not the firmware. Two ways around it:

- **Stay in the IDE:** type any dummy character in the prompt. With no-auth firmware the device ignores it, so the upload still succeeds.
- **Skip the prompt entirely (recommended for no-password):** upload from the command line, which never asks. With the ESP32 core's bundled `espota.py`:
  ```bash
  python espota.py -i patternflow.local -p 3232 -f /path/to/patternflow.ino.bin
  ```
  (no `-a` flag = no password). Or `arduino-cli upload -p patternflow.local -b esp32:esp32:<board> patternflow/`.

To require a password instead, set `#define PF_OTA_PASSWORD "your-secret"` in `patternflow_secrets.h`.

### Known issue: `invalid int value: '{upload.port.properties.port}'`
Arduino IDE 2.x's mDNS discovery for ESP32 core 3.3.8 doesn't populate the `{upload.port.properties.port}` placeholder, so espota receives the literal string and fails:
```
espota.exe: error: argument -p/--port: invalid int value: '{upload.port.properties.port}'
```

One-time fix — create a `platform.local.txt` next to the ESP32 core's `platform.txt` (the IDE auto-merges local overrides, so this survives ESP32 core updates):

- Path on Windows: `%LOCALAPPDATA%\Arduino15\packages\esp32\hardware\esp32\3.3.8\platform.local.txt`
- Path on macOS: `~/Library/Arduino15/packages/esp32/hardware/esp32/3.3.8/platform.local.txt`
- Path on Linux: `~/.arduino15/packages/esp32/hardware/esp32/3.3.8/platform.local.txt`

Contents (one line):
```
tools.esp_ota.upload.pattern={cmd} -i {upload.port.address} -p 3232 "--auth={upload.field.password}" -f "{build.path}/{build.project_name}.bin"
```

This hardcodes the OTA port to 3232 (which is what ArduinoOTA always listens on anyway). Restart the Arduino IDE after creating the file.

### Disabling / customizing
- Set `#define PF_OTA_ENABLED 0` in `patternflow_secrets.h` to compile OTA out entirely (no Wi-Fi stack pulled in unless OSC or audio-react is also enabled).
- Set `#define PF_OTA_HOSTNAME "yourname"` to advertise as `yourname.local` instead of `patternflow.local` — useful if multiple devices are on the same network.
- OTA ships with no password by default (`PF_OTA_PASSWORD ""`). Set `#define PF_OTA_PASSWORD "your-secret"` in `patternflow_secrets.h` to require one on a shared network. See "The upload-password prompt" above for the Arduino IDE 2.x quirk.

## License

MIT - see root `LICENSE-MIT` file.

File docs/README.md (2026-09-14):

# docs/

What is here, and what is not. The rule for the split: **a guide somebody follows start to finish lives at the repository root** (`BUILD_GUIDE.md`, `BUILD_GUIDE_v2.md`, `PATTERN_GUIDE.md`, `FEATURE_GUIDE.md`, `AUDIO_GUIDE.md`); **a contract, a reference, a walk-through for one task, or a record lives here**; and a folder explains itself in its own README. The folder-by-folder map of the whole repository is [`REPOSITORY.md`](REPOSITORY.md).

## Contracts — other software is built against these, not against the firmware source

- [`rest-api.md`](rest-api.md) — the device's HTTP API (`/api/*`), the console pages, and the table for choosing between HTTP, OSC, MIDI and MQTT
- [`osc-spec.md`](osc-spec.md) — OSC over UDP (DAWs, Max, TouchDesigner)
- [`midi-spec.md`](midi-spec.md) — the panel as a network MIDI port
- [`mqtt-spec.md`](mqtt-spec.md) — MQTT topics, both directions, the roles, and why the channel decides whether a write sticks
- [`audio-ws-spec.md`](audio-ws-spec.md) — the audio-react WebSocket the browser extension and the phone app speak
- [`pfst-v2-spec.md`](pfst-v2-spec.md) — the `.pfs` show table, with test vectors in [`pfst-v2-vectors/`](pfst-v2-vectors/)
- [`panel-compatibility.md`](panel-compatibility.md) — a buying guide first (which HUB75 panels light up and which stay dark), then the reference for other sizes

## How the firmware is put together

- [`EDITIONS.md`](EDITIONS.md) — features, compositions, editions: the seam, the rule that the core names no feature, the vocabulary. **Read before touching firmware.**
- [`rfc-core-and-variants.md`](rfc-core-and-variants.md) and its [progress log](rfc-core-and-variants-progress.md) — the 2026-08 RFC that produced the seam. Historical: it says *addon* and *variant* where the tree says *feature* and *edition*, and its listing rules have been superseded by `EDITIONS.md`.

## Walk-throughs — one task, start to finish

- [`midi-ableton.md`](midi-ableton.md) — the panel as a MIDI port in Ableton Live, with screenshots
- [`director-midi.md`](director-midi.md) — how a Director show becomes a MIDI clip
- [`assembly/`](assembly/README.md) — the assembly map: which enclosure with which electronics, and where each route is documented
- [`../firmware/CUSTOM_PATTERNS.md`](../firmware/CUSTOM_PATTERNS.md) — the hands-on pattern route (the everyday one is [`PATTERN_GUIDE.md`](../PATTERN_GUIDE.md))
- [`../firmware/patternflow/console/README.md`](../firmware/patternflow/console/README.md) — editing or adding a device console page

## Building it

- [`assembly/`](assembly/README.md) — the map. The full guide is [`../BUILD_GUIDE.md`](../BUILD_GUIDE.md); the files to order are described in [`../hardware/README.md`](../hardware/README.md)
- [`build-guide/images/`](build-guide/images/) — photos for the build guides (`images/` is the v2 set, `images/v3/` the current board)
- [`LICENSE-SUMMARY.md`](LICENSE-SUMMARY.md) — MIT for code, CC BY-SA 4.0 for hardware, docs and bundled patterns, and what that means for a pattern you publish or a remix you share

## Contributing

- [`../CONTRIBUTING.md`](../CONTRIBUTING.md) — one table: what you have → where it goes → what CI runs on it
- [`../SUPPORT.md`](../SUPPORT.md) — where to ask what
- [`REPOSITORY.md`](REPOSITORY.md) — the folder-by-folder map, and the list of files that outside things link to

## Running the project

- [`RELEASING.md`](RELEASING.md) — the `dev` → `main` routine, cutting a release, what the workflows attach
- [`SERVICES.md`](SERVICES.md) — the production hosts (community, build worker) and their systemd units. Korean.

## Records

- [`investigations/`](investigations/) — dated post-mortems
- [`releases/`](releases/) — long-form notes for three July 2026 releases, kept as written; notes since 3.2 are on [GitHub Releases](https://github.com/engmung/Patternflow/releases), and `CHANGELOG.md` at the root is the complete record
- [`manifesto.md`](manifesto.md) — why Patternflow exists, and (section 6) how we treat each other
- [`images/`](images/), [`media/`](media/) — assets the guides and the site reference

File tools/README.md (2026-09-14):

# tools/

Clients that Patternflow ships and that run on their own — a browser extension, a phone app, a diagnostic script. The line between this folder and [`integrations/`](../integrations/README.md): a **tool** is a standalone program of ours; an **integration** is a bridge that runs inside or beside someone else's software (a DAW, Max, TouchDesigner, Node-RED). Both talk to the panel only through the contracts in [`docs/`](../docs/README.md#contracts--other-software-is-built-against-these-not-against-the-firmware-source).

| Folder | What it is | Contract |
| :--- | :--- | :--- |
| [`patternflow-audio-extension/`](patternflow-audio-extension/README.md) | Chrome/Edge extension: captures the current tab's audio, splits it into four bands you shape on a response graph, streams the levels to the panel | [`audio-ws-spec.md`](../docs/audio-ws-spec.md) |
| [`patternflow-audio-android/`](patternflow-audio-android/README.md) | The phone-side twin: captures what the phone is playing and drives the knobs with it, for filming | [`audio-ws-spec.md`](../docs/audio-ws-spec.md) |
| [`rtpmidi-probe/`](rtpmidi-probe/README.md) | A plain-Python RTP-MIDI session initiator that walks the MIDI contract against a panel from a machine with no MIDI driver | [`midi-spec.md`](../docs/midi-spec.md) |

## The extension is also firmware source

The band editor in `patternflow-audio-extension/` (`editor.html`, `editor.css`, `editor.js`, `editor-adapter.js`) is the **authoring source of the device's own `/audio-in` console page**: `firmware/toolchain/build_audio_in_page.py` assembles `firmware/patternflow/console/audio-in.html` from those files, and the `console-sync` workflow fails if the two drift. Edit the editor here, never the generated page, and do not move this folder — the build script and the workflow hold its path.

## License

Code in `tools/` is MIT, like the firmware and the site ([`LICENSE-MIT`](../LICENSE-MIT)). Each tool's README says how to build and run it.

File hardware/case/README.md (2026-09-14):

# Patternflow Case

3D-printable enclosure for the Patternflow LED synthesizer. Folders are named by **printer bed size** — find the folder that fits your printer.

> **These cases fit the v3 board — both v3.9 and v3.0.** The two revisions share an identical outline and mounting-hole pattern (v3.9 only removed the USB-C footprint), so either drops into the same enclosure. If you built (or are building) a v2.x board, use [`legacy_v2/`](legacy_v2/) — the v3 board is a different size and the two generations are **not** interchangeable.

> 🖨️ **Bambu printer? One-click path:** the case is on **[MakerWorld](https://makerworld.com/ko/models/3072492-patternflow-open-source-led-synthesizer-case#profileId-3459015)** with tuned print profiles — open in Bambu Studio and print. The same project ships in this repo as [`patternflow_v3.3mf`](bed_256mm/patternflow_v3.3mf) (4 pre-arranged plates, settings included). The STLs below are for everyone else.

## Which folder do I print?

| Your printer bed | Print | Design | Status |
|---|---|---|---|
| **256 mm** (Bambu P1S / X1C / A1 class) | [`bed_256mm/encloser.stl`](bed_256mm/) | The snap-fit design split for a 256 mm bed — body frame, back panels, and LED-panel mount in one STL | ✅ Standard option, ~10 h total |
| **~330 mm+** (Bambu H2S-class) | [`bed_330mm/encloser.stl`](bed_330mm/) | The one-piece original — body, closing part, and LED-panel mount in one STL, no bonding at all. Also has a **USB pass-through to the DevKit and a cable exit slot** (data only — see below) | ✅ Main design ([#113](https://github.com/engmung/Patternflow/issues/113)) |

**Whichever body you print, also print [`knobs/knobs_20mm.stl`](knobs/) — required for every build.** Knobs go in **black**, everything else in **white**; run the knob plate as its own print job. (15 mm-shaft encoders → `knobs_15mm.stl`; 15 mm and 20 mm shafts are functionally identical, and the [BOM](../bom/)'s reference part, PEC11R-4220F-S0024, is 20 mm.)

## `bed_330mm/` — one-piece snap-fit

The original mass-production-oriented design: a single-piece body plus a snap-fit closing part, wall-mount hanger hole included. No bonding step at all. Does **not** fit a 256 mm bed.

**`encloser.stl`** — everything in one STL (body, closing part, LED-panel mount), all **white** PLA; knobs from [`knobs/`](knobs/) in black. Same design as the print-&-assembly-verified 256 mm kit, just uncut.

**Wired access to the DevKit (330 mm only).** Two openings the 256 mm variant doesn't have yet: a **pass-through between the power-bank bay and the ESP32**, so a USB-C lead reaches the DevKit's own port with the case shut — that's for wired features like MIDI and OSC, and for flashing — and a **cable exit slot below the battery compartment**, so a cable leaves the enclosure instead of being pinched under the back panel.

> ⚠️ **The DevKit port is for data, not power.** Power enters at `J4`, the screw terminal, on every build — see [BUILD_GUIDE §2](../../BUILD_GUIDE.md#2-power-input--use-the-screw-terminal). Never run the panel's supply through the DevKit's USB port.

## `bed_256mm/` — the standard build

**`patternflow_v3.3mf`** is the Bambu Studio project for this kit — four pre-arranged plates with the print settings below, the same file the MakerWorld listing serves. Open it and print; the STL is for every other slicer.

**`encloser.stl`** puts the whole body in one file: frame and back-panel halves plus the LED-panel mounting part, all in **white** PLA. ~10 hours total on a P1S. Print the knobs separately from [`knobs/`](knobs/), in **black**. The LED-panel mount is sized for the panel linked in the [BOM](../bom/). **Print & assembly verified** — the [assembly video](https://youtu.be/J9C9bZgkNKs) builds from this exact file.

Design perks: **two wall-mount holes**, a **snap-fit back panel**, and recesses for the LED matrix's alignment bumps — **no more nipper-trimming** the panel back (the old [#19](https://github.com/engmung/Patternflow/issues/19) workaround).

### `for_other_panels/` — using a different LED panel?

`divided_v3_part1..5.stl` is an adjustable-mount variant whose **LED-panel mounting part adapts to varying bolt-hole positions** — panel suppliers drill them in different places. Print this instead of `encloser.stl` **only if** your panel is not the BOM-linked one. Print & assembly verified with a v3.0 board in [#169](https://github.com/engmung/Patternflow/issues/169), including USB-C port alignment.

> ⚠️ Adjustable ≠ universal: if your panel's hole layout differs a lot, even this version may not fit. Check the mounting part against your panel before committing to the full print.

### Assembly notes (both 256 mm variants)

The full photo sequence lives in the [build guide](../../BUILD_GUIDE.md) — §4 (bond the printed halves right after printing) and §6 (panel in with `HUB-75E IN` toward the top → mounting part + screws → board in, encoder nuts from the front). Two watch-outs: the panel insertion is very tight (near-zero clearance) — work it in slowly — and bonded seams can show a hairline gap, fillable with putty or baking soda + CA.

## `legacy_v2/` — v2.x boards only

Everything that fits the v2.x board generation, kept for existing builds. **None of these fit the v3 board.** Follow the [v2 build guide](../../BUILD_GUIDE_v2.md).

| File | What |
|---|---|
| `encloser_v2.1.stl` | ✅ **Recommended v2 print** — the snap-fit design cut for the v2.1 board, every part in one STL (knobs included). Print & assembly verified. No body gluing, snap-fit back panel, two wall-mount holes, and **no LED-matrix bump trimming** ([#19](https://github.com/engmung/Patternflow/issues/19) recesses built in). Assemble per the sequence in the [v3 guide §6](../../BUILD_GUIDE.md#6-case-assembly). |
| `plate_main.stl` + `plate_dividers.stl` | Classic split plates (256 mm bed, glued) — the path the [v2 guide](../../BUILD_GUIDE_v2.md) documents with full photos |
| `oneshot_v2_part1/2.stl` | One-piece snap-fit for the v2.x board (330 mm+ bed) |

(An `easyfit` plate variant existed briefly but was retired over a fit defect — [#154](https://github.com/engmung/Patternflow/issues/154). It remains browsable at the [v2.1.0 tag](https://github.com/engmung/Patternflow/tree/v2.1.0/hardware/case).)

## Print settings

- **Printer:** Bambu P1S (default profile works as-is)
- **Nozzle:** 0.4 mm
- **Layer height:** 0.2 mm (default)
- **Supports:** Standard (regular) — *not* tree supports
- **Brim:** Off
- **Aux fan:** ~20%

## `source/`

- `patternflow_case.blend` — Blender source for every printed part. Saved with **Blender 5.2 LTS**; older Blender releases will not open it.

> **Note — downloading the .blend.** The Blender source is stored in Git LFS, so GitHub's *Code → Download ZIP* gives you a small pointer file instead of the real ~52 MB file. Download it from the [latest release assets](https://github.com/engmung/Patternflow/releases/latest) instead. The STL files are regular files and download fine either way.

To re-export STLs after editing:

1. Open the `.blend` in Blender.
2. Select the entire collection for one part.
3. `File → Export → Stl (.stl)`, with **Selection Only** checked.
4. Save with the matching filename in the bed-size folder.

## `legacy_lasercut/`

`patternflow_v1.svg` / `patternflow_v2.svg` — the v1-era laser-cut acrylic case drawings, from before the printed enclosure. Kept for the record; nothing current is built from them. See [`legacy_lasercut/README.md`](legacy_lasercut/README.md).

## `remixes/` — sharing a variant

Built a different enclosure — acrylic, wood, a wall plate, a case for another panel? It goes in [`remixes/`](remixes/README.md), one folder per remix with a README that carries the author, the license and what it is based on (STL and DXF files cannot carry a header, so the README is the header). The official folders above are not edited by a remix; a remix sits beside them. Work in progress is for Discord; a folder here is something that has been built at least once.

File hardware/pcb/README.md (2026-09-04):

# Patternflow PCB

Custom board for the Patternflow LED synthesizer — ESP32-S3 DevKit on sockets, four EC11 encoders, HUB75 out, screw-terminal power input. KiCad 10 project.

**Current revision: v3.9** — the USB-C power footprint is gone. v3.0 carried a `USB1` receptacle and its `R1`/`R2` CC pull-downs that had to be left unpopulated after a delayed burnout ([#221](https://github.com/engmung/Patternflow/issues/221)); v3.9 removes them from the board outright, so there is exactly one power input and no way to pick the wrong one. Board outline, mounting holes, and every remaining footprint are unchanged from v3.0 — **the v3 cases fit both boards**. All through-hole, no SMD parts at all; every part is listed by MPN in the [BOM](../bom/).

## Board

| Front | Back |
| :---: | :---: |
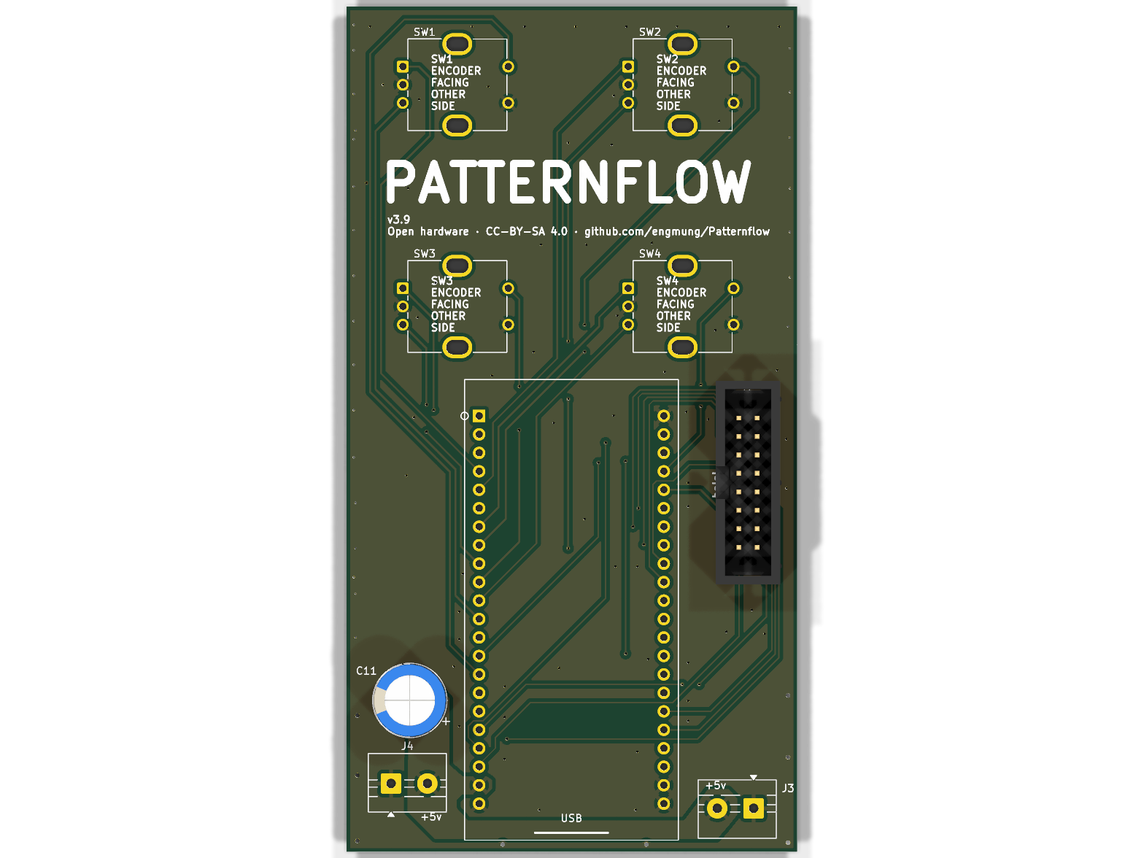
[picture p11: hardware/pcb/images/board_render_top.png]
Patternflow v3.9 board — front
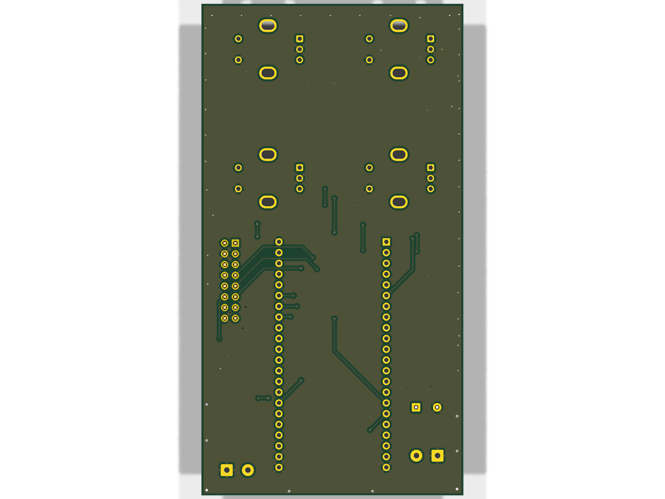
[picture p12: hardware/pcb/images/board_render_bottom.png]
Patternflow v3.9 board — back
|  |  |

- **U1** — ESP32-S3 DevKit (N16R8) on 2× 1×22 female sockets; the DevKit itself is never soldered
- **SW1–SW4** — EC11 rotary encoders, inserted from the **back** (silkscreen reminds you: *encoder facing other side*)
- **J1** — 2×8 box header; the panel's HUB75 ribbon plugs in here
- **Power — J4**: a 2-pin screw terminal on the back, and the board's only power input. Strip a USB cable from any power bank and screw the wires in. (v3.0 also had a USB-C receptacle; it was withdrawn from service after a delayed burnout at a connector pin, [#221](https://github.com/engmung/Patternflow/issues/221), and v3.9 carries no USB-C footprint at all)
- **J3** — +5V out to the LED matrix · **C11** — 1000µF bulk cap for the boot transient

## Schematic

Patternflow v3.9 schematic

Also available as [`schematic.pdf`](schematic.pdf) (no KiCad required).

## Ordering

The board is listed as a [PCBWay shared project](https://www.pcbway.com/project/shareproject/Patternflow_An_LED_synthesizer_776d796c.html) — ordering there needs no Gerber upload and supports Patternflow development. Any fab works, though: upload [`gerber/patternflow_v3.9_gerber.zip`](gerber/) to the fab of your choice (JLCPCB tends to be the cheapest).

| Gerber | Status |
|---|---|
| `patternflow_v3.9_gerber.zip` | ✅ **Order this** — current. Same board as v3.0 with the USB-C input removed |
| `patternflow_v3.0_gerber.zip` | Previous revision — fabricated, assembled, and verified ([#114](https://github.com/engmung/Patternflow/issues/114)). Fits the same cases; only order it if you specifically want the USB-C footprint, which must stay unpopulated ([#221](https://github.com/engmung/Patternflow/issues/221)) |
| `patternflow_v2.1_gerber.zip` | Legacy — last v2.x board. Only for [v2 builds](https://github.com/engmung/Patternflow/releases/tag/v2.1.0); **does not fit the v3 cases** |
| `patternflow_v1.0_gerber.zip` / `v2.0` | Archived early revisions |
| `gerber/experiment/` | Unverified WIP — never order from here |

## Folder layout

- `kicad/` — editable KiCad 10 source (`patternflow.kicad_pro/sch/pcb` + local footprint/3D libs)
- `gerber/` — fab-ready zips, one per revision
- `images/` — renders + schematic export for this README
- `schematic.pdf` — printable schematic

## Regenerating outputs

After editing the KiCad source (paths relative to `hardware/pcb/`):

```sh
# Gerbers + drill (matches the repo zip convention: 14 files, fab layers only)
kicad-cli pcb export gerbers --no-protel-ext \
  --layers F.Cu,B.Cu,F.Paste,B.Paste,F.Silkscreen,B.Silkscreen,F.Mask,B.Mask,Edge.Cuts \
  -o out/ kicad/patternflow.kicad_pcb
kicad-cli pcb export drill --excellon-separate-th --generate-map --map-format gerberx2 -o out/ kicad/patternflow.kicad_pcb

# Schematic PDF + SVG
kicad-cli sch export pdf -o schematic.pdf kicad/patternflow.kicad_sch
kicad-cli sch export svg -e -o images/ kicad/patternflow.kicad_sch

# Board renders
kicad-cli pcb render --side top    --quality high -w 1600 -h 1200 -o images/board_render_top.png    kicad/patternflow.kicad_pcb
kicad-cli pcb render --side bottom --quality high -w 1600 -h 1200 -o images/board_render_bottom.png kicad/patternflow.kicad_pcb
```

## License

CC-BY-SA 4.0 — see the root [LICENSE-CC-BY-SA](../../LICENSE-CC-BY-SA).

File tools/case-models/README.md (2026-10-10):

# Case models

The 3D models the [/build](https://patternflow.work/build) page's preview shows, one per case on its case switch, and the scripts that make them from files in this repository. Pick a case on the switch and the device in the preview is that case, with the same Patternflow inside it: the LED panel, the v3.9 board and the ESP32 DevKit, and four knobs (the official ones, or the case's own).

| Case | Model | Made from | Script |
| :--- | :--- | :--- | :--- |
| Official | `web/public/cases/official/model.glb` | `web/public/guide/case-v39.glb`, the guide's v3.9 case (itself exported from `hardware/case/source/patternflow_case.blend`) | `assemble.mjs official` |
| Besoiobiy | `web/public/cases/besoiobiy-printed/model.glb` | `hardware/case/remixes/besoiobiy-printed/source/patternbox.stl` | `besoiobiy.py`, then `assemble.mjs` |
| SimonePDA | `web/public/cases/simonepda-lasercut/model.glb` | `hardware/case/remixes/simonepda-lasercut/lasercut_layout.pdf` | `simonepda.py`, then `assemble.mjs` |
| mbchars | `web/public/cases/mbchars-horizontal-desktop-printed/model.glb` | `hardware/case/remixes/mbchars-horizontal-desktop-printed/stl/` | `mbchars.py`, then `assemble.mjs` |

Run `./build.sh` to make all four again (or `./build.sh <case>` for one). The models are committed; nothing here runs when the site builds. Every step is deterministic: the same files in give the same bytes out.

| Model | Size | Loads |
| :--- | ---: | :--- |
| `official/model.glb` | 317 KB | with the page (the guide uses it too) |
| `besoiobiy-printed/model.glb` | 345 KB | when its tab is hovered or picked |
| `simonepda-lasercut/model.glb` | 332 KB | when its tab is hovered or picked |
| `mbchars-horizontal-desktop-printed/model.glb` | 380 KB | when its tab is hovered or picked |

The landing page's model before these, `web/public/3dforweb.glb` (a v3.0 device), was 1,155 KB and loaded with the page.

## Setup

```sh
cd tools/case-models
npm ci                                   # glTF-Transform, Draco, meshoptimizer
python3 -m venv .venv && .venv/bin/pip install -r requirements.txt   # Python 3.12 or newer
```

`build.sh` uses `.venv/bin/python` when it is there (or `$PYTHON`). `preview.mjs` also needs the web app's dependencies (`npm ci` in `web/`) and Playwright with a Chromium.

## How a model is put together

A case script makes the case's *shell*: one mesh per part, assembled, in the model frame below, with material names from `lib/looks.mjs`, and a `placement.json` saying where this case holds the board and the LED panel:

```text
{ "board": [dx, dy, dz], "led": [x, y, z], "ledTurn": degrees, "knobs": "official" | "shell", "knobBaseZ": z, "knobLook": material }
```

`board` is added to where the official case has the board, the DevKit and the knobs; `led` is the panel node's translation, its z the LED face, and `ledTurn` turns the panel about its own middle (anticlockwise seen from the front), for a case that holds it on its side; `knobs` says whether the shell has its own `c1` … `c4` or takes the official ones (standing at `knobBaseZ`, in `knobLook`, black PLA unless it says otherwise). Everything but `board` and `knobs` can be left out. `assemble.mjs` then adds what every case has, from the files the guide uses and the knob's STL:

- the LED panel, `source/led_panel.glb`: the node `l` of the landing page's old model, its name, transform, geometry and UVs unchanged. `extract_led.mjs` took it out; the old file is at `git show v3.11.0:web/public/3dforweb.glb`;
- the v3.9 board, `web/public/guide/pcb-v39.glb`, and the DevKit, `web/public/guide/devkit.glb`, simplified with meshoptimizer — the preview shows them small, through a case;
- the official knob, unless the case has its own: the knob people print, `hardware/case/knobs/knobs_20mm.stl`, read and turned round (`lib/knob.mjs`, below), one mesh for all four;

sets every material's look by name (`lib/looks.mjs`; materials merge only when their names match, since the page swaps looks by name), compresses the meshes with Draco like the site's other models, and writes `web/public/cases/<case>/model.glb`.

`preview.mjs <model.glb> <out.png> [--explode]` renders a model from four sides without starting the site.

### The model frame

One unit is 10 mm. The device stands facing +z, +y up with the knobs at the top, +x to the reader's right: the LED panel on the left, the knob column on the right. It is the frame the guide's models share (`web/src/components/guide/stage/geometry.ts`, `parts.ts`); `lib/frame.mjs` copies the numbers this folder needs from there.

### The nodes the page relies on

`web/src/components/3d/caseModels.ts` finds these by name in every model, and `caseModels.test.ts` checks that they are there:

| Node | What |
| :--- | :--- |
| `l` | The LED panel. The pattern shaders draw on its front face, with its UVs. |
| `c1` … `c4` | The knobs: origin on the encoder axis at the knob's base, axis +z, no rotation. Named after the encoder nets as `case-v39.glb` names them: seen from the front, `c1` top-left, `c2` top-right, `c3` bottom-left, `c4` bottom-right. |
| `pcb_v39` | The board; its children keep `pcb-v39.glb`'s names. |
| `devkit` | The DevKit; its `module` is the ESP32 module, its `board` is renamed `devkit_board`. |

Every other top-level node is a part of the case, named by its script. Where each one goes when the preview draws the device apart is in `web/src/components/3d/cases/<case>.ts`.

## Official: `assemble.mjs official`

The guide's v3.9 case (`body`, `back_plate`, `back_slider`, `top_lid`) in white PLA, with the knobs, the board and the DevKit where the guide seats them. There is no shell script: the case is already in the model frame.

### The official knob: `lib/knob.mjs`

`case-v39.glb` has the knob as exported from the STL, a 32-sided prism, and at the size the preview draws it its flats and corners show. `lib/knob.mjs` reads `hardware/case/knobs/knobs_20mm.stl` instead: it takes one of the file's four knobs, measures its radius at every height the STL has vertices at, and turns that profile about the knob's axis with 96 sides. It keeps the outside (20 mm tall, 16.26 mm across the base, 12.89 mm across the top, a little convex), the open recess under it and the bore; it leaves out the 16 flutes round the top half, 0.14 mm deep, and the D's flat in the bore, and rounds the top edge by 0.4 mm so it catches the light (a choice for the preview: the knob prints on its top, and that edge comes off the bed sharp). Bends under 35° are smooth, the rest are edges. It stops if the STL is no longer that knob (its height and both diameters are checked). The knob's base stands where `case-v39.glb`'s does, 0.8 mm off the front.
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

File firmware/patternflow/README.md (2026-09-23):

# Patterns

> This page is about patterns. Setting up a build is [`../README.md`](../README.md); the everyday way to make a pattern is [`PATTERN_GUIDE.md`](../../PATTERN_GUIDE.md), and nothing on this page is needed for it.

A pattern reaches the panel one of two ways: as a curated **preset** compiled
into the firmware, or as a **`.pfm` module** uploaded over Wi-Fi and loaded
from the FATFS partition at runtime — no reflash, no reboot. Modules are the
normal path; presets are the showcase and the fallback a bare board boots into.

## Two kinds

```
patternflow/
└── presets/
    └── preset_<name>.h         ← curated patterns the project ships as a showcase

FATFS partition (on the device, not in this repo)
└── <slug>.pfm                  ← your own patterns, uploaded over Wi-Fi
```

- **`presets/preset_<name>.h`** is compiled into `firmware.bin`. Presets are
  curated rather than hand-edited in the IDE, so they're tucked in a subfolder.
  Because they sit one level down, their includes use `"../src/..."` (and
  `"../config.h"`). Adding one means an entry in `presetPatterns[]` and a
  rebuild — see [`../CUSTOM_PATTERNS.md`](../CUSTOM_PATTERNS.md).
- **`.pfm` modules** are how a pattern of your own gets onto a device now: a few
  KB of relocatable ELF, uploaded at `/patterns` over Wi-Fi, discovered at boot
  and appended after the presets. No reflash, no reboot, up to 128 of them.
  Build one with `firmware/toolchain/build_module.py`.

> The old `custom1.h`–`custom3.h` slots in the sketch root are **gone** —
> modules are what they were for, and no longer cost a rebuild. Only `Origin`
> is compiled in today; the rest of the curated set ships as the Basics pack
> (`web/public/packs/basics.zip`, built from `presets/` by
> `firmware/toolchain/make_pack.py`) and installs from the Patterns page.
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

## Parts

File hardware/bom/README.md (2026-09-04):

# Bill of Materials

Machine-readable BOMs for the Patternflow board and build. **The CSV is the source of truth** — the build guide's parts table is derived from it. Quantities are per unit (one Patternflow). Prices are deliberately not listed; look parts up by MPN at your distributor.

| File | Board | Status |
|---|---|---|
| `bom_v3.9.csv` | v3.9 (screw-terminal power only) | ✅ **Use this.** Same parts as v3.0 minus the USB-C receptacle and its two CC pull-downs, which the board no longer has a footprint for. Order `hardware/pcb/gerber/patternflow_v3.9_gerber.zip`. |
| `bom_v3.0.csv` | v3.0 (screw-terminal power; USB-C footprint on hold) | Previous revision — fabricated, assembled, and verified on the screw-terminal input. Kept for anyone who already has a v3.0 board; `USB1`/`R1`/`R2` stay unpopulated on it ([#221](https://github.com/engmung/Patternflow/issues/221)). |

For a v2.x build, use the BOM inside the [v2.1.0 release build guide](https://github.com/engmung/Patternflow/blob/v2.1.0/BUILD_GUIDE.md#1-bill-of-materials-bom).

## v3.9 at a glance

Seven on-board line items, all through-hole and hand-solderable. Every SMD passive went away with v2.x, and v3.9 drops the last surface-mount part on the board — the USB-C receptacle's shell — so **nothing you solder is surface-mount**, and there is no part on the BOM you're told not to populate.

**Power input: the `J4` screw terminal, on every build.** Strip a USB cable, clamp the two wires in, done — no soldering iron needed for the power input.

> 📦 **Already have a v3.0 board?** Use `bom_v3.0.csv` and leave `USB1`, `R1`, and `R2` unpopulated — those parts are not needed and should not be bought. The USB-C input was withdrawn from service after a USB-C-powered board ran fine for 20–30+ minutes and then smoked at a connector pin, destroying the receptacle and power path ([#221](https://github.com/engmung/Patternflow/issues/221)). The failure is *delayed*, so a board that seems fine at first proves nothing. v3.9 removes the footprint so the question can't come up again.

## Sourcing notes

- **Every part is specified by manufacturer part number (MPN).** Order from Mouser/DigiKey (or find the same MPN elsewhere). The one exception:
- **LED matrix panel — buy via this link:** [Full color 320×160mm P2.5 HUB75 — AliExpress](https://s.click.aliexpress.com/e/_c3SVdcQr) (affiliate link — supports Patternflow development at no extra cost). LED panels have no meaningful MPNs, and this specific listing's **mounting-screw positions are known to match the case**. Other panels may work electrically — the driver IC must be a classic shift-register type, and "HUB75E" on the listing proves nothing; read **[LED Panel Compatibility](../../docs/panel-compatibility.md)** before ordering — but are not yet verified mechanically.
- **ESP32-S3**: Espressif is the reference part; AliExpress modules generally work fine too. If yours won't cold-boot reliably, the on-module 10k GPIO0 pullup fix in [#16](https://github.com/engmung/Patternflow/issues/16) solves it — one resistor.
- **Encoders**: any 5-pin EC11 with a push switch works — the cheapest packs just fail more often. The Bourns PEC11R is the reference part; note the firmware assumes its direction ([`config.h`](../../firmware/patternflow/config.h)).

## Column reference

`category` pcb / off-board · `ref` PCB reference designator (`-` = no refdes) · `qty` per unit · `mounting` how it attaches · `optional` `no` (required — every line in `bom_v3.9.csv` is) · `notes` assembly-critical warnings — read before soldering.

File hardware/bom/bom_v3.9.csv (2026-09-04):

category | ref | qty | part | spec | mounting | mpn | manufacturer | source | optional | notes
pcb | U1 | 1 | ESP32-S3 DevKit | N16R8 (16MB Flash, 8MB PSRAM), 44-pin, 25.4mm header spacing | socketed | ESP32-S3-DevKitC-1-N16R8 | Espressif | Mouser/DigiKey/AliExpress | no | Espressif is the reference part; AliExpress modules generally work fine too. If yours shows the cold-boot issue, one 10k GPIO0 pullup on the module fixes it (Issue #16). Do NOT solder the DevKit itself; it plugs into the female sockets.
pcb | U1 (sockets) | 2 | Female pin socket header | 1x22, 2.54mm pitch | thru-hole | PPPC221LFBN-RC | Sullins | Mouser/DigiKey | no | Not a separate PCB refdes. Solder two socket rows into the U1 header-hole rows; the DevKit plugs in on top.
pcb | SW1-SW4 | 4 | Rotary encoder with push switch | EC11 footprint, 5-pin, 20mm shaft | thru-hole | PEC11R-4220F-S0024 | Bourns | Mouser/DigiKey | no | CRITICAL: insert from the BACK side — encoder bodies on back, leads soldered on front. 20mm shaft: print knobs from hardware/case/knobs/knobs_20mm.stl. Any 5-pin EC11 with a push switch works — the cheapest packs just fail more often. Substitute only if mechanically equivalent for PCB/enclosure fit.
pcb | J1 | 1 | Box header | 2x8, 2.54mm, vertical | thru-hole | 61201621621 | Würth Elektronik | Mouser/DigiKey | no | HUB75 ribbon to the LED matrix. Mechanical orientation must match PCB silkscreen/footprint.
pcb | J3 | 1 | Screw terminal | 2-pin, 5.0mm pitch | thru-hole | TB002-500-02BE | CUI Devices | Mouser/DigiKey | no | +5V output to the LED matrix. Required on every build. Equivalent part acceptable only if pitch and footprint match.
pcb | J4 | 1 | Screw terminal | 2-pin, 5.0mm pitch | thru-hole | TB002-500-02BE | CUI Devices | Mouser/DigiKey | no | THE power input, on the BACK of the board: strip a standard USB cable and screw the wires in. Required on every build.
pcb | C11 | 1 | Electrolytic capacitor | 1000µF 16V, radial D10xL13, 5.0mm pitch | thru-hole | 16PX1000MEFC10X12.5 | Rubycon | Mouser/DigiKey | no | Main bulk decoupling. Observe polarity. Equivalent part acceptable only if size/lead spacing fits the PCB.
off-board | - | 1 | LED matrix panel | HUB75, 128x64 px, P2.5, 320x160 mm, full color SMD | - | - | - | AliExpress (see README) | no | Driver IC must be a classic shift-register type (74HC595 / FM6124 / FM6126A / ICN2037 / ICN2038S / DP5125D / DP3246 / MBI5124 / SM162xx). S-PWM 'video wall' panels (ICN2053, FM6353, FM6363C/FM6373C, DP3264, ICND2055, MBI505x) stay completely dark — 'HUB75E' on the listing proves nothing. Read docs/panel-compatibility.md before ordering. Buy via the README link: its mounting-screw positions are known to match the case. Ships with HUB75 ribbon + power cable.
off-board | - | 6-12 | M4 screw | ~10mm length | - | generic | any | any | no | LED matrix mounting. The panel has 12 holes: all 12 is the exact fit, 6 spread across the corners and middle holds it firmly. Sized for the README-linked panel — if you buy a different panel, match the screws to its mounting holes instead.
off-board | - | 1 | USB cable (sacrificial) | any, will be cut | - | generic | any | any | no | Stripped and clamped into J4 — this is how the board is powered.
off-board | - | 1 | USB power bank | 5V, must physically fit the case compartment | - | - | - | user-supplied | no | Any standard USB power bank that fits and can supply a couple of amps at 5V. Runtime table (roughly 4 h per 10000 mAh at max brightness) is in the repo root README, section 'Power & runtime'.

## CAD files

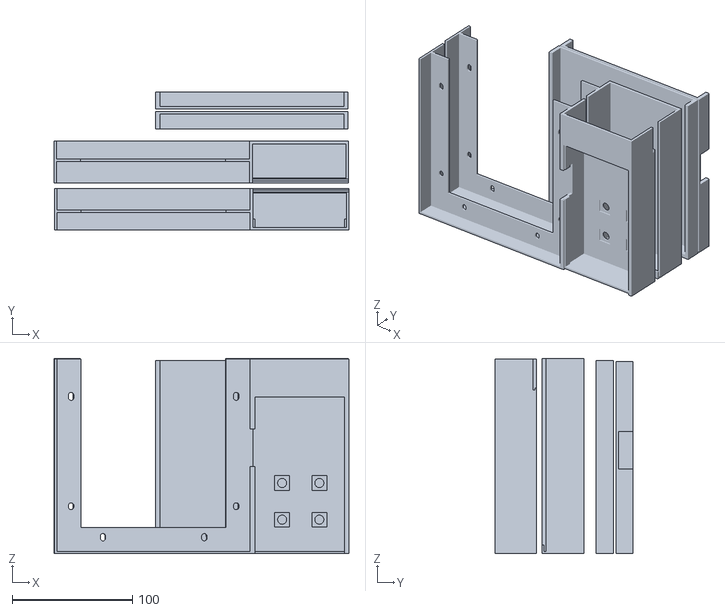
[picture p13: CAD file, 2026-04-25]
hardware/case/print-ready/01_plate_main.stl
245.6 x 115.1 x 162.7

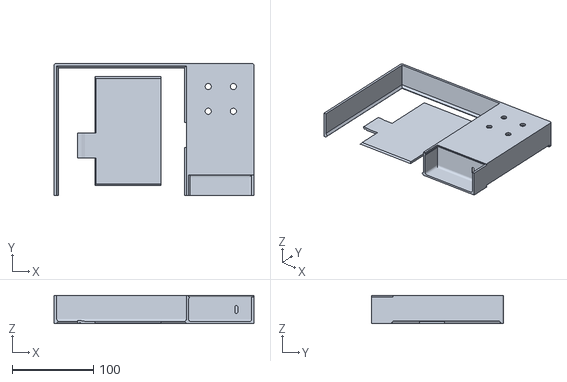
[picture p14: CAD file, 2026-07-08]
hardware/case/bed_256mm/for_other_panels/divided_v3_part2.stl
246.7 x 163.1 x 34.7

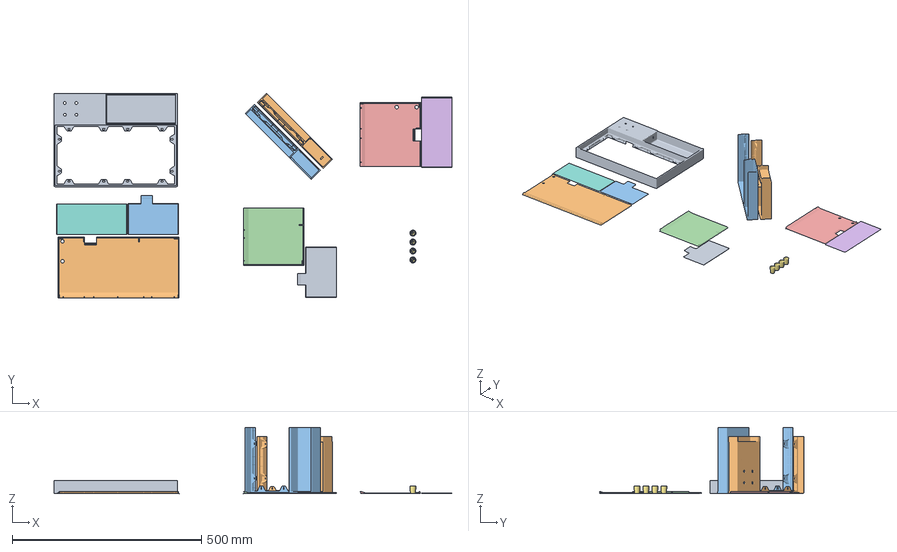
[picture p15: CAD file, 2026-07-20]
hardware/case/bed_256mm/patternflow_v3.3mf
1051.1 x 540.3 x 175.3 mm
encloser.stl_1 x 2
encloser.stl_2 x 2
encloser.stl_3 x 2
encloser.stl_4 x 2
encloser.stl_5
encloser.stl_6
knobs_20mm.stl

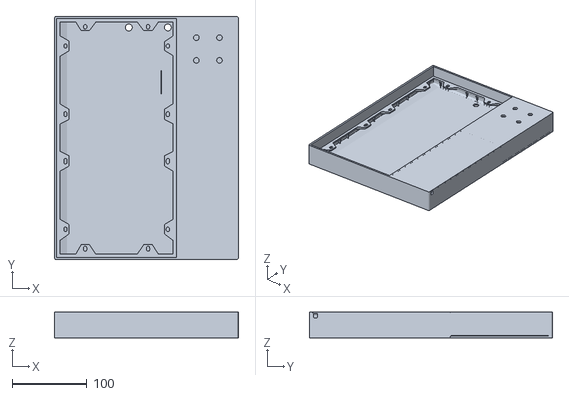
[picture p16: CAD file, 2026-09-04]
hardware/case/bed_330mm/encloser.stl
246.8 x 326.3 x 34.7

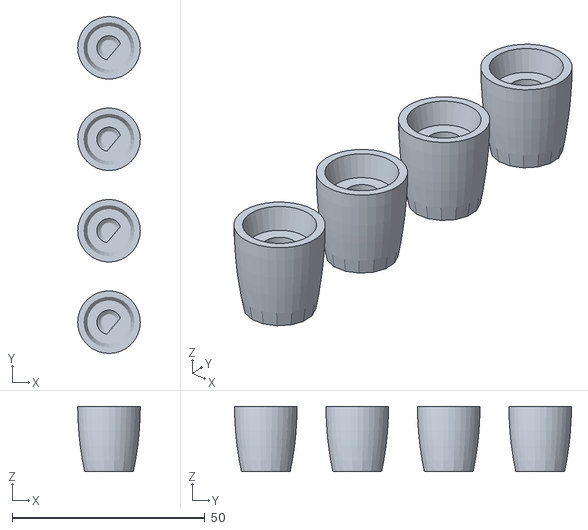
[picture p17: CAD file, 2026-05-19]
hardware/case/knobs/knobs_15mm.stl
16.3 x 87.5 x 17.0

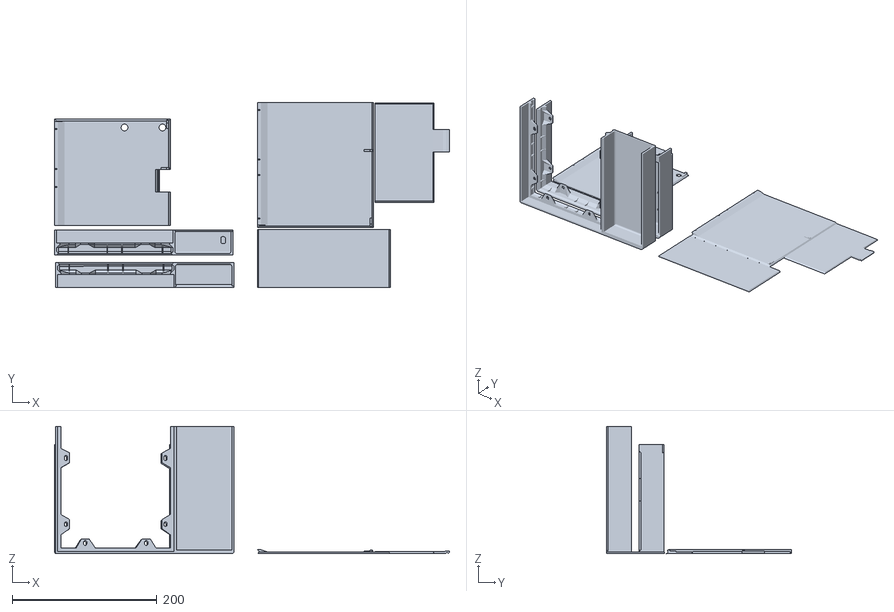
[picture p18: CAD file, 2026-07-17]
hardware/case/print-ready/experiment/v2.1_divided.stl
545.7 x 256.1 x 175.8

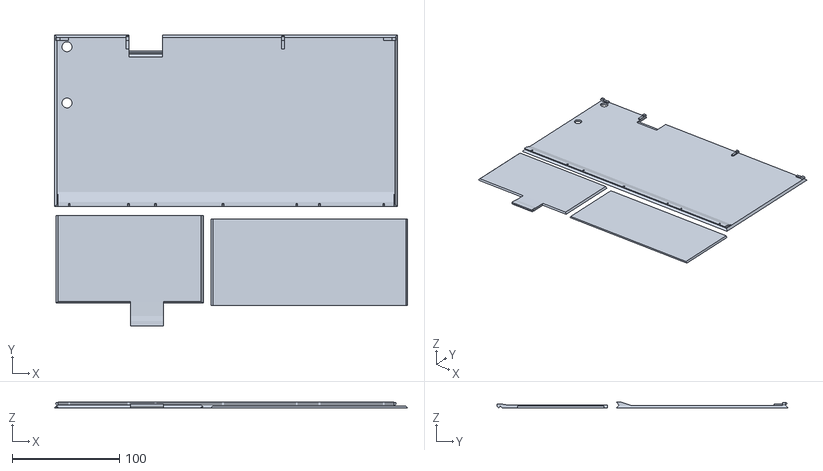
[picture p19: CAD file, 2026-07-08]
hardware/case/print-ready/variants/oneshot_v2_2.stl
329.2 x 271.6 x 5.42

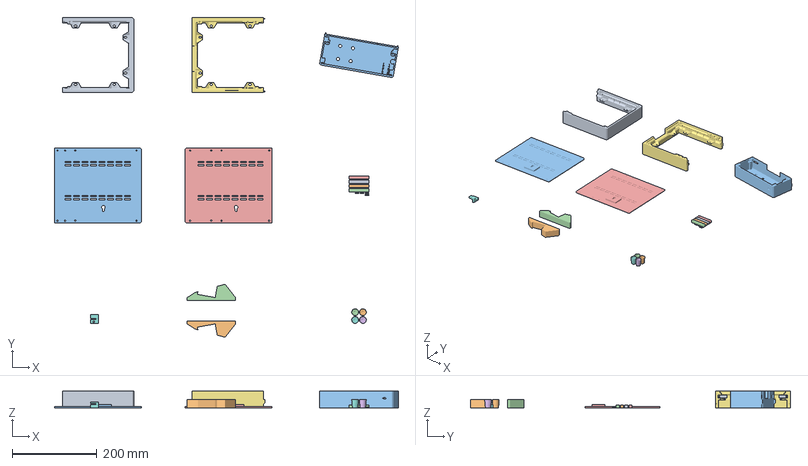
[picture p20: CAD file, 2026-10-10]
hardware/case/remixes/mbchars-horizontal-desktop-printed/print_layout.3mf
809.9 x 752.5 x 39.0 mm
white_outer_frame
knob_1
right_controls
knob_2
join_bar_1
knob_3
white_inner_frame
knob_4
join_bar_2
join_bar_3
rear_display_side
join_bar_4
rear_controls_side
pin_1
pin_2
usb_pusher_R6_short
pin_3
stand_1
pin_4
stand_2

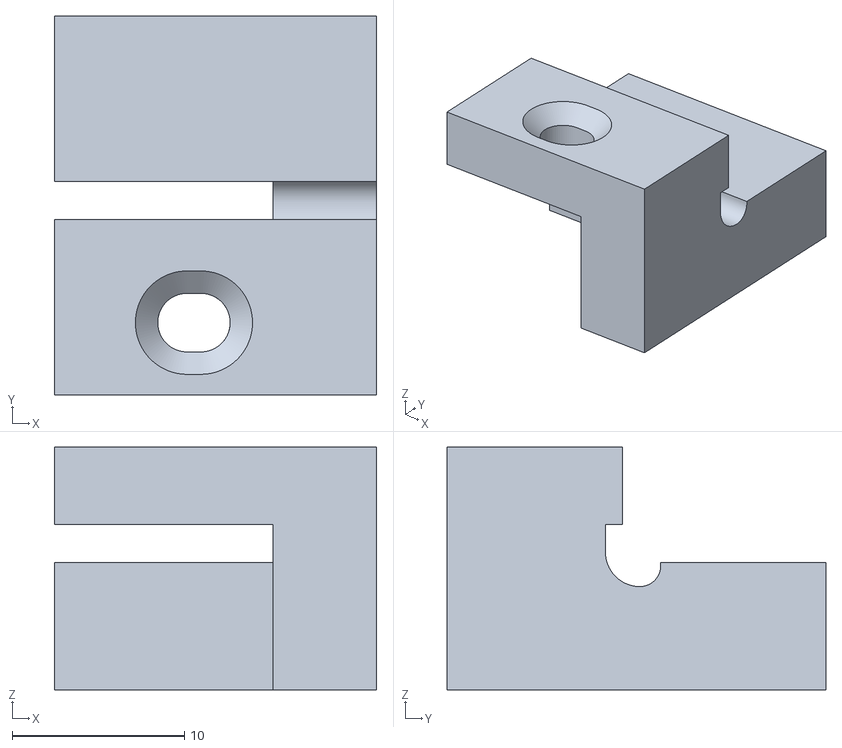
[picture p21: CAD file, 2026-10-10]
hardware/case/remixes/mbchars-horizontal-desktop-printed/stl/usb_retainer.stl
18.7 x 22.0 x 14.1

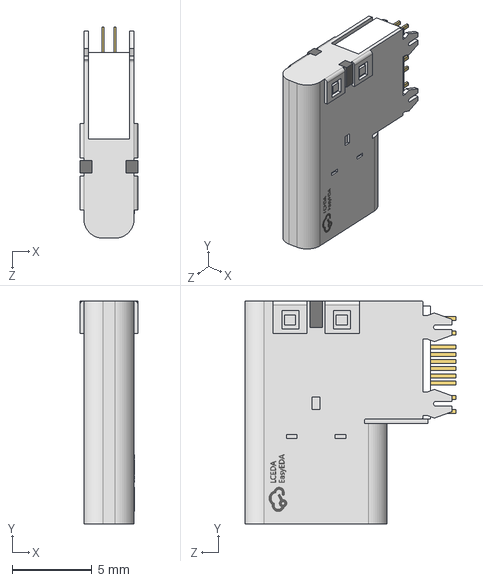
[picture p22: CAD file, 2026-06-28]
hardware/pcb/kicad/3d/TYPE-C-TH_TYPE-C-14P-CC-2.6.step
3.66 x 14.0 x 13.3 mm

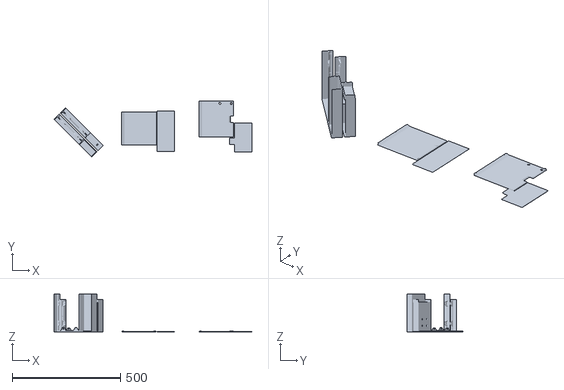
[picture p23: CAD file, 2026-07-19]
hardware/case/bed_256mm/encloser.stl
916.0 x 260.1 x 175.4

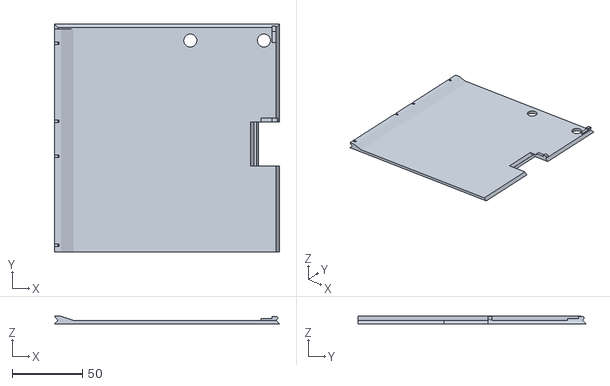
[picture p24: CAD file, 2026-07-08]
hardware/case/bed_256mm/for_other_panels/divided_v3_part4.stl
160.1 x 162.0 x 5.39

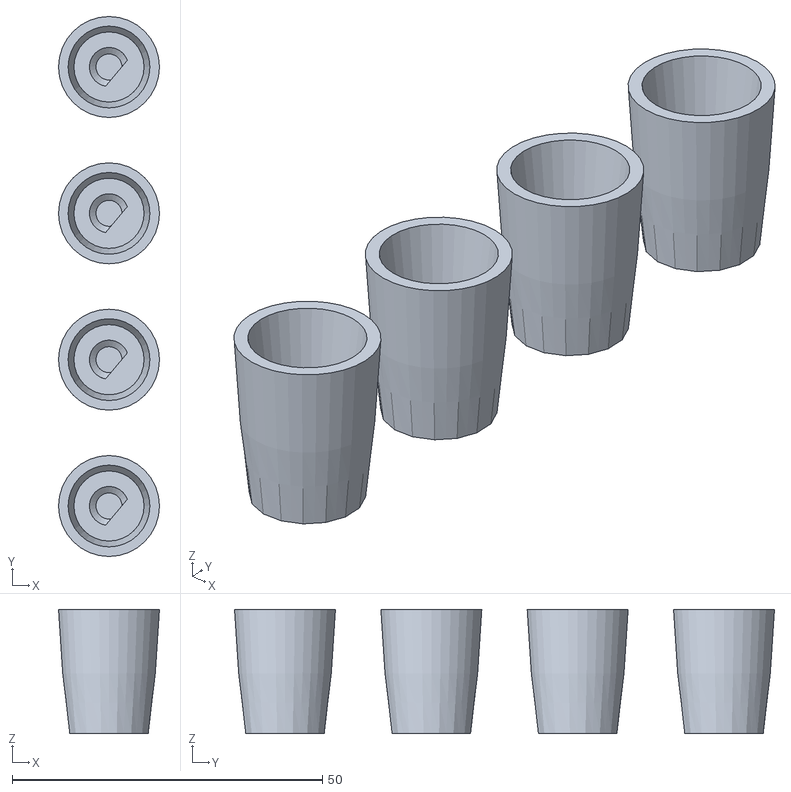
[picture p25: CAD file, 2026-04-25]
hardware/case/knobs/knobs_20mm.stl
16.3 x 87.0 x 20.0

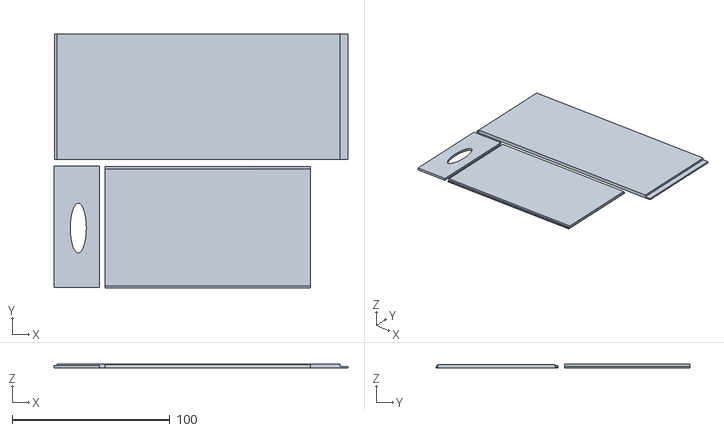
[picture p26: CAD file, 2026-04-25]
hardware/case/print-ready/02_plate_dividers.stl
186.5 x 161.3 x 2.81

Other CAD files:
hardware/case/remixes/mbchars-horizontal-desktop-printed/stl/knob.stl
hardware/case/bed_256mm/for_other_panels/divided_v3_part1.stl
hardware/case/remixes/mbchars-horizontal-desktop-printed/stl/white_outer_frame.stl
hardware/case/bed_256mm/for_other_panels/divided_v3_part3.stl
hardware/case/bed_256mm/for_other_panels/divided_v3_part5.stl
hardware/case/legacy_v2/encloser_v2.1.stl
hardware/case/legacy_v2/oneshot_v2_part1.stl
hardware/case/print-ready/variants/oneshot_v2_1.stl
hardware/case/remixes/mbchars-horizontal-desktop-printed/stl/alignment_pin_2mm.stl
hardware/case/remixes/mbchars-horizontal-desktop-printed/stl/control_section.stl
hardware/case/remixes/mbchars-horizontal-desktop-printed/stl/joint_bar.stl
hardware/case/remixes/mbchars-horizontal-desktop-printed/stl/rear_control_cover.stl
hardware/case/remixes/mbchars-horizontal-desktop-printed/stl/rear_display_cover.stl
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

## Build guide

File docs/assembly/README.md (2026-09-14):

# Build Patternflow — Assembly Map

> **Which version am I building?** Current hardware is the **v3.9 board** (the v3.0 board with the USB-C footprint removed; same case, same guide): follow **[BUILD_GUIDE.md](../../BUILD_GUIDE.md)** and take the files from the tree — [`hardware/README.md`](../../hardware/README.md) says exactly which Gerber, BOM and STL to use. The [v3.0.0 release](https://github.com/engmung/Patternflow/releases/tag/v3.0.0) bundles the previous revision's files.
> Own a **v2.x board**? Use **[BUILD_GUIDE_v2.md](../../BUILD_GUIDE_v2.md)** and the **[v2.1.0 release](https://github.com/engmung/Patternflow/releases/tag/v2.1.0)** instead. **v2 and v3 parts are not interchangeable** — the boards do not fit each other's cases.

> 🔦 **Buying the LED panel? Read [LED Panel Compatibility](../panel-compatibility.md) first.** Patternflow scans the panel directly from the ESP32-S3, so the **driver IC** decides whether it lights up — "HUB75E" on the listing does not, and a spec-matching panel with S-PWM "video wall" drivers stays completely dark with no firmware fix. Since that part number is almost never in the listing, the practical check is the **buyer reviews**: someone running it off an ESP32 or Raspberry Pi is the best evidence you'll get.

Patternflow is not a single, rigid kit. It is a modular system divided into two core parts:

1. **Enclosure** — how you house the device (3D printed; community remixes welcome).
2. **Electronics** — how you wire the hardware (custom PCB, or breadboard).

Build those two, flash the firmware, and your Patternflow is alive.

## The main route (v3.0.0)

| Enclosure | Electronics | Firmware | Status |
| --- | --- | --- | --- |
| [3D printed enclosure](../../hardware/case/README.md) | [Custom PCB, hand-soldered](../../hardware/pcb/README.md) | [Browser flash](../../BUILD_GUIDE.md#8-firmware) · [your own patterns](../../PATTERN_GUIDE.md) | **Current — fully documented** |

This is the route [BUILD_GUIDE.md](../../BUILD_GUIDE.md) walks start to finish: PLA parts on any 256 mm-bed FDM printer, the hand-soldered v3.9 board (all through-hole — deliberately kept first-timer easy), and firmware flashed from the browser. Two ordering shortcuts are wired straight to it:

- **PCB** — the [PCBWay shared project](https://www.pcbway.com/project/shareproject/Patternflow_An_LED_synthesizer_776d796c.html): no Gerber upload, and ordering there supports Patternflow development.
- **Case** — the [MakerWorld listing](https://makerworld.com/en/models/3072492-patternflow-open-source-led-synthesizer-case#profileId-3459015): tuned one-click print profiles for Bambu printers (STLs in `hardware/case/` for everyone else).

## All combinations

| Enclosure | Electronics | Status |
| --- | --- | --- |
| 3D printed enclosure | Custom PCB | **Current** — [BUILD_GUIDE.md](../../BUILD_GUIDE.md) |
| 3D printed enclosure | Breadboard / jumper-wire electronics | Available — [Breadboard Build Guide](https://patternflow.work/build/breadboard) |
| Laser-cut or any other enclosure | either | Not an official path. Community variants live in [`hardware/case/remixes/`](../../hardware/case/remixes/README.md); the old acrylic drawings are in [`legacy_lasercut/`](../../hardware/case/legacy_lasercut/README.md) |

The breadboard path exists to make Patternflow easier and cheaper to start. A breadboard build is not just a temporary prototype — if that form is enough for you, it is a valid Patternflow build. Want a more finished object later? Move to the PCB and printed-enclosure path whenever you like.

The custom PCB path is stable. PCBA may become a later electronics path for people who want the same PCB with less hand assembly.

## Firmware & custom patterns

To bring the hardware to life you flash it with firmware, and you can **create and run your own generative patterns with AI coding assistants**.

Custom patterns no longer need a local toolchain or a reflash: a pattern built in the browser installs on the panel over Wi-Fi as a `.pfm` module in seconds (the browser flasher writes the firmware itself over USB once, and sets up Wi-Fi while it is at it). The PlatformIO route remains only for firmware feature development or targeting a different LED matrix resolution.

- **[Make your own patterns](../../PATTERN_GUIDE.md)** — the Pattern Lab, the community, and sending a pattern to your device over Wi-Fi. [`firmware/CUSTOM_PATTERNS.md`](../../firmware/CUSTOM_PATTERNS.md) is the hands-on route.

## Guides & releases

| Version | Guide | Everything bundled |
| --- | --- | --- |
| **v3.9 board** (current; v3.0 is the same board with a USB-C footprint you leave empty) | [BUILD_GUIDE.md](../../BUILD_GUIDE.md) | the files in [`hardware/`](../../hardware/README.md); the [v3.0.0 release](https://github.com/engmung/Patternflow/releases/tag/v3.0.0) bundles the v3.0 revision |
| v2.1.0 (legacy) | [BUILD_GUIDE_v2.md](../../BUILD_GUIDE_v2.md) | [v2.1.0 release](https://github.com/engmung/Patternflow/releases/tag/v2.1.0) |

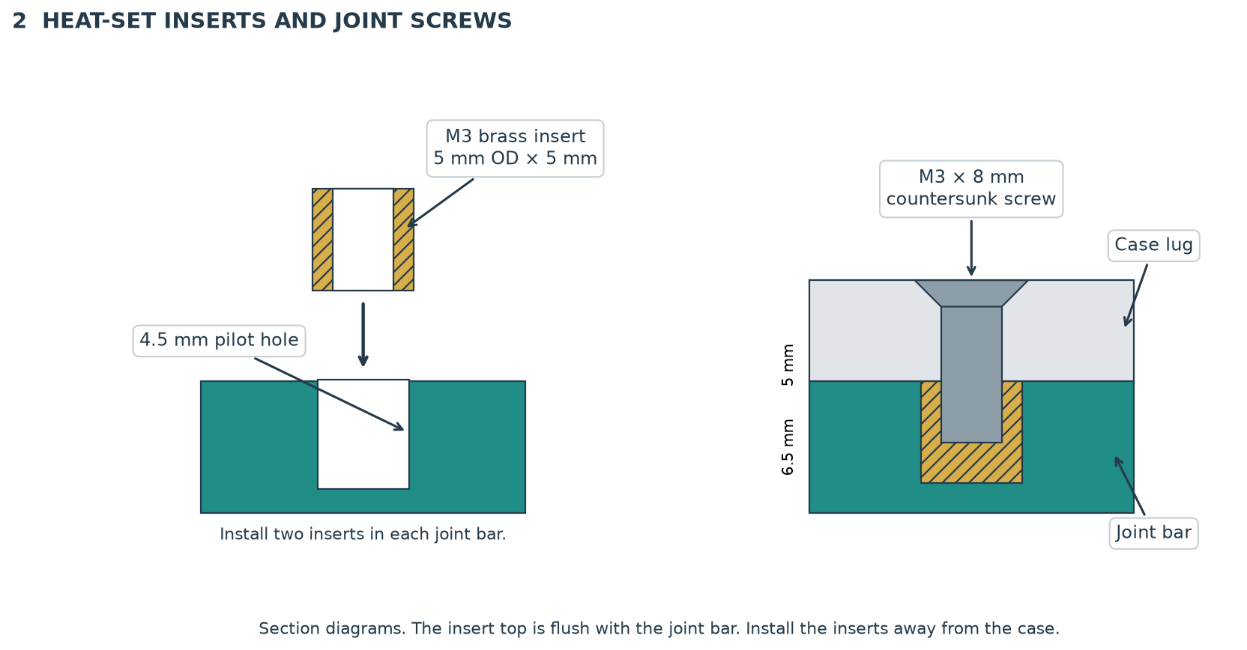
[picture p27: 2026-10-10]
hardware/case/remixes/mbchars-horizontal-desktop-printed/images/02_joint_section.png

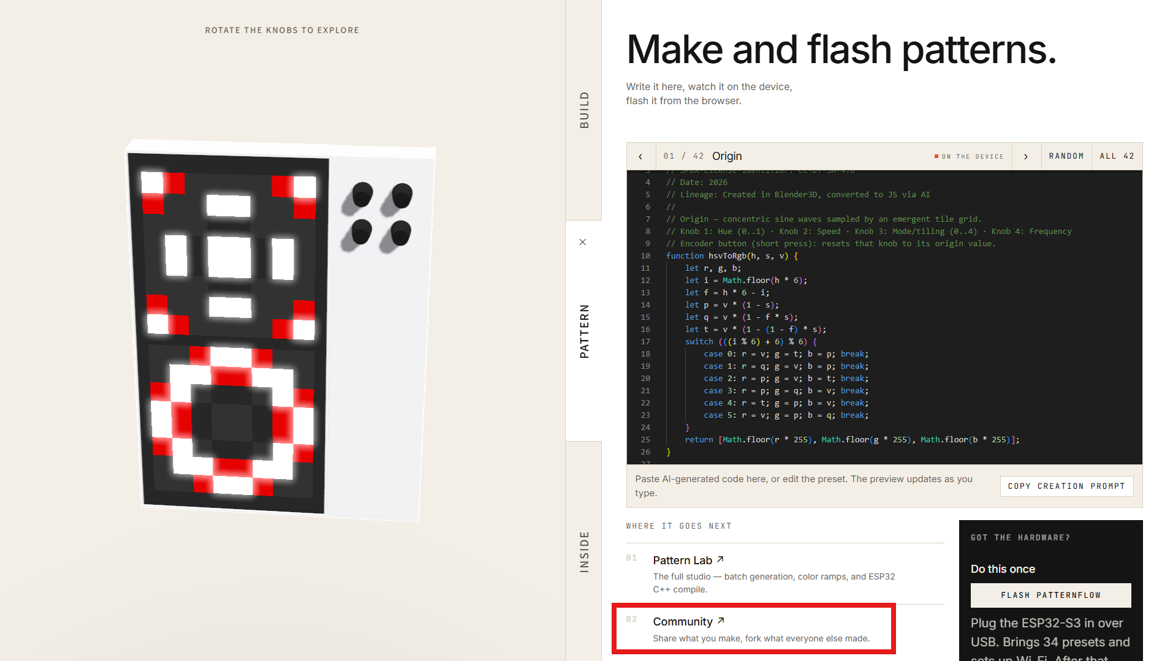
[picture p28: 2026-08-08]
docs/images/pattern-guide/01-landing-to-community.png

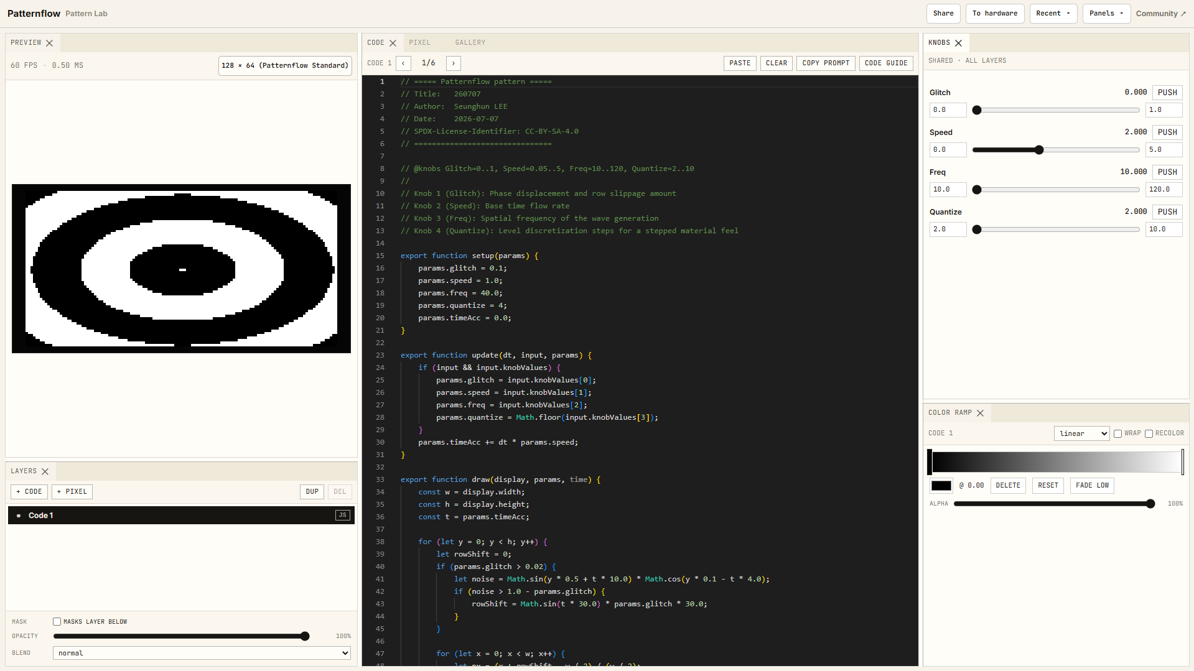
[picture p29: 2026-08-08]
docs/images/pattern-guide/11-pattern-lab.png

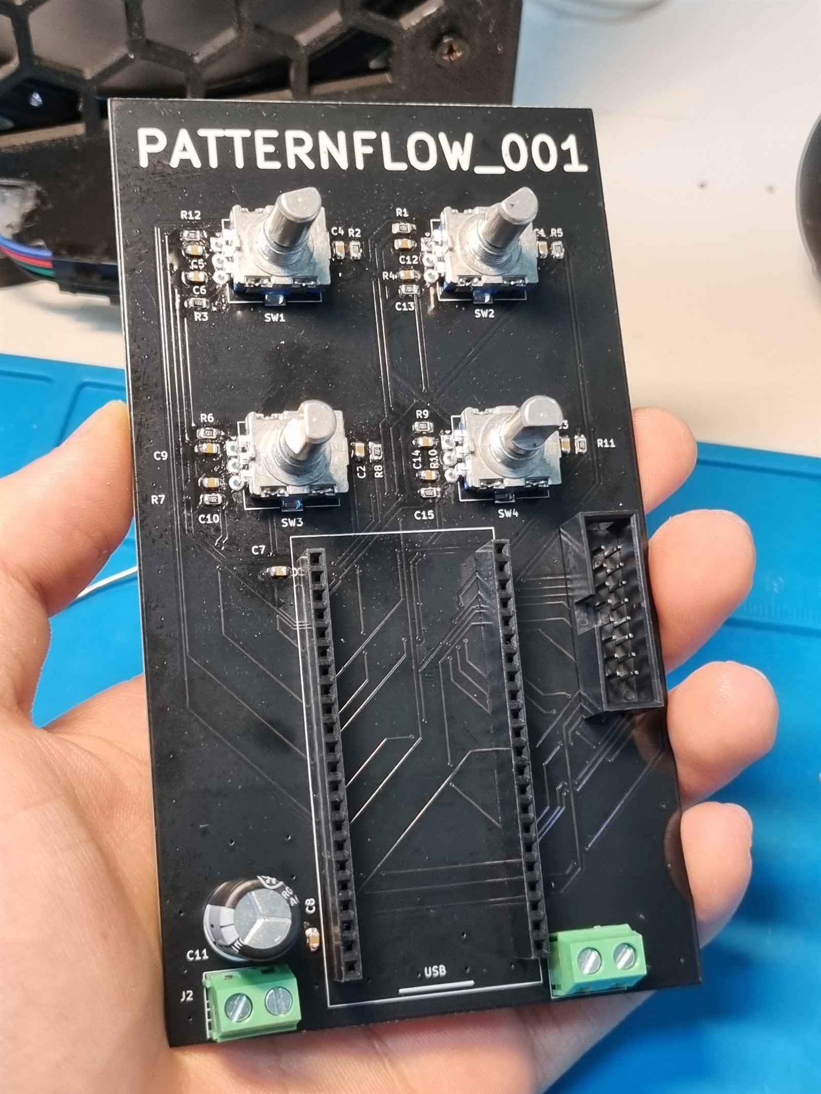
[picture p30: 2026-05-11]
docs/build-guide/images/encoder_front_wrong.jpg

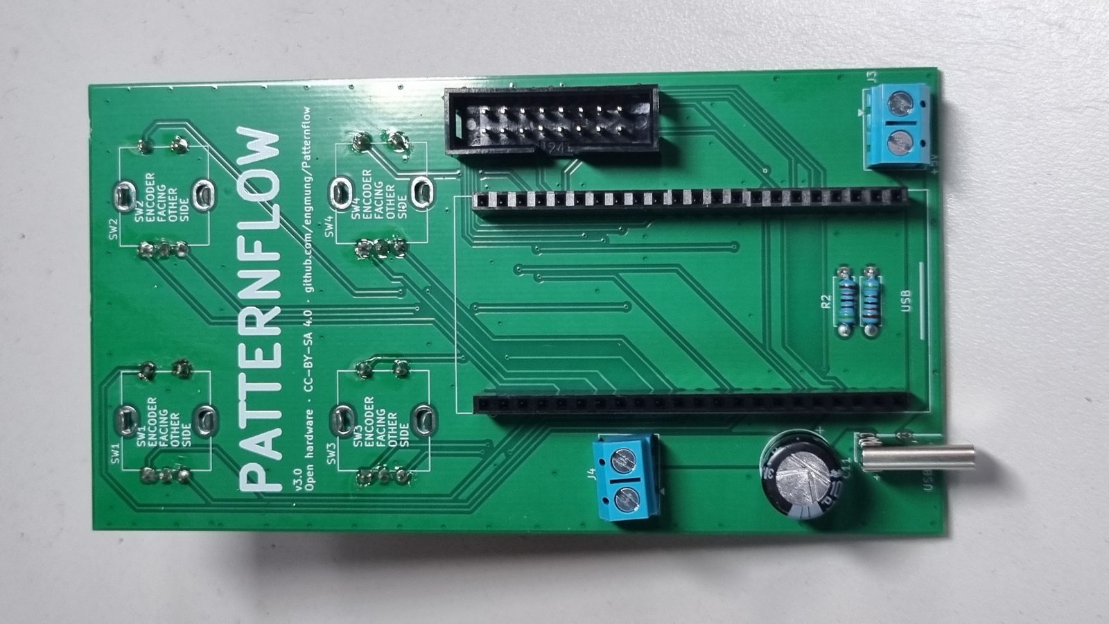
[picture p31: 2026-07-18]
docs/build-guide/images/v3/09_board_front.jpg

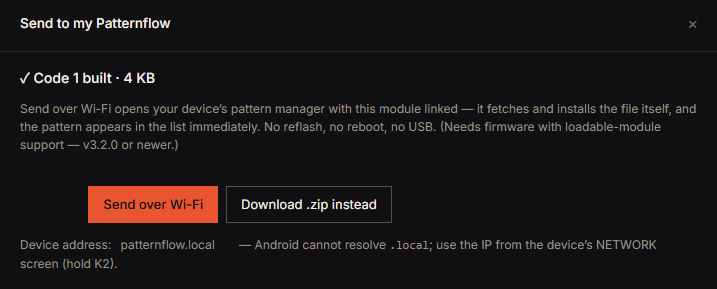
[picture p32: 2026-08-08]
docs/images/pattern-guide/17-send-over-wifi.png

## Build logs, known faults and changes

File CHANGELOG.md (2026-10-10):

# Changelog

All notable changes to Patternflow will be documented in this file, newest first. The story of each release, with its flashable images, is on [GitHub Releases](https://github.com/engmung/Patternflow/releases); this file is the complete record.

## [Unreleased]

### Hardware

- **Besoiobiy's printed case is the second enclosure remix** (`hardware/case/remixes/besoiobiy-printed/`). Two long pieces glued side by side, a frame round the panel and a box for the board and the power bank, closed at the back by four screwed-on covers, with the panel bolted through the case into its own M3 sockets. Its README takes the place of the build guide's sections 4 and 6 and sets the order of 7 to 9; check your panel against it first, because the BOM's panel takes M4 screws on another hole pattern. The build guide's printing section and the assembly map point at it.
- **Mykyta Bilous' horizontal desktop case is the third enclosure remix** (`hardware/case/remixes/mbchars-horizontal-desktop-printed/`, [#488](https://github.com/engmung/Patternflow/pull/488) by [@mbchars](https://github.com/mbchars)). The panel lies the long way across on two removable stands, with the four controls on the right. Three front sections print face down, two white frames and an orange control section, and four joint bars on brass inserts hold them together without glue; two rear covers open onto the electronics and carry wall-mount openings. There is no power-bank bay: a separate PDSink 303PDSink01 trigger module in the control section feeds J4, the screw terminal, at 5 V. One Bambu Studio project holds all nine plates, with illustrated assembly instructions and the BOM changes beside it.

### Web

- **/build lets you pick the case, and the 3D view shows the one you pick.** The Build panel's switch (the official v3.9 case, Besoiobiy's printed case, SimonePDA's laser-cut one; `?case=` links to one) brings up that case's card, a remix's opening with its README on GitHub, and swaps the device in the preview for that case, with the same v3.9 board, DevKit and LED panel inside (and, on Besoiobiy's case, its own knob caps). SimonePDA's case comes in its two finishes, acrylic and MDF. Each model is made by `tools/case-models` from the case's own files in this repository (the guide's v3.9 case, Besoiobiy's STLs, SimonePDA's cutting layout) and sits beside the case's photos, `web/public/cases/<id>/model.glb`. The model the page loads first is 0.32 MB, where the old v3.0 one (`3dforweb.glb`, now removed) was 1.15 MB; a remix's model loads when it is picked, and the guide takes its LED panel from the official one.
- **/build has a fourth case, mbchars' horizontal desktop one, in the switch and in the 3D view.** Its card is its README's facts and the author's photos, and the switch is four tabs, two by two on a phone. `tools/case-models/mbchars.py` puts its model together from the remix's STLs, since no assembled file exists, and checks it against the README; in it the panel lies the long way (`ledTurn` in `placement.json`), the official knob is printed white (`knobLook`), and the orange is the one in the author's 3MF, `#F46B16` (`pla_orange`). The model is 0.38 MB and loads when the case is picked; the other three rebuild byte for byte. The case is 41 cm across, so on a desktop's tall view it is drawn smaller, by as little as keeps it clear of the arrows; on a phone all four cases, and on a desktop the three upright ones, are still drawn at the one scale. The build map's pin for the same build goes by the maker's name now, mbchars (it was extraplojo).
- **The 3D view on /build has arrows and a name.** On the Build tab, arrows either side of the device step through the cases, round and back to the first, as the build map's arrows step through builds; the switch, the card and `?case=` follow. Over the device is whose case it is, the name on its tab (Official, Besoiobiy, SimonePDA, mbchars), in the build map's label.
- **The preview's case is white, not beige, and the rest of it looks more like the photos.** The printed parts are a neutral white PLA (`#f4f4f2`, matte), where the guide's warm white had come along; the case front measures b\* +0.4 and L\* 89.8 where it was +1.7 and 82.5. The frame goes through the shoulder of the Neutral tone curve, which leaves what is under its knee as lit and rolls off what is brighter with its channels together, so a bright light no longer clips red and green first and leaves the white yellow. The light is made on the page from light panels, as on the guide's stage, instead of an environment map fetched from a CDN at run time. The LED panel is a grid of round LEDs on a black mask where it was solid blocks on grey (each LED becomes its whole cell once it is under about three pixels across, as on a phone), its sides and back are the panel's black frame, and what glowed before (the whites, and the bright yellows and cyans of a pattern from the editor) glows as before. The official knob is the printed knob's own profile drawn round, where it was a 32-sided prism. SimonePDA's clear acrylic is clear: the canvas is see-through, and every partly covered pixel used to reach the page far too bright, which drew the sheet frosted white; its three feet, which no photo shows on it, now come out only with the parts and on Assemble. Every case is drawn at one scale, so the LED panel is the same size in all three (the remixes drew it 3.5 to 4% smaller). The three models were rebuilt with `tools/case-models/build.sh`; the official one grows by 0.8 KB.

### Docs

- **The build pages say what is true now.** Laser cut is no longer "being prepared" on /build, in the README, the v2 guide or `llms.txt`: SimonePDA's case is it. The printing time is about 10 hours for the official case on a 256 mm bed (/build said 10–12, the breadboard guide 11), the v2 guide and the assembly map name the v3.9 board, and the breadboard guide flashes through the DevKit's native USB port from the Pattern tab and links the sections that exist.

## [3.11.0] - 2026-10-04

### Firmware

- **Going back to a pattern no longer loads it again.** An installed pattern (a `.pfm` module) was unloaded the moment another pattern took the panel, so every return paid for a whole load: reading the file, relocating it, its constructors and its own `setup()`. For most of the catalogue that is 25-100 ms; for the heavy ones it was the pause you could see - Branched Flow 3.3 s, Two Stream 4.1 s, Burgers and Wave Cascade 0.6 s each. A module that has run now stays loaded in PSRAM ("parked") when another pattern takes over, and picking it again resumes it: nothing is read or relocated, `setup()` does not run again, and the pattern carries on from where it was, as the built-in presets always have. Measured on two boards, a return takes 115-197 µs. Picked while another pattern is still loading, it comes back once that load is done; picked during an install, it is loaded afresh afterwards, because an install empties what is parked. Up to 16 modules stay parked (`PF_MODULE_RESIDENT_MAX`; `0` turns this off).
- **SELECT shows patterns that are already in memory live.** A preset or a parked module comes on as the knob reaches it and runs behind the overlay instead of showing its thumbnail, as long as the pattern being left can be kept too. A pattern that has to be loaded still waits for the knob to rest.
- **A module's data now goes to PSRAM first, as its code already did.** Only a module that holds no internal RAM at all is kept, so the console and Wi-Fi give up nothing for parked patterns. Measured A-B-B-A on two boards: 13 of 16 module runs within noise (-1.1..+0.8%), Burgers +2.6% (38.9 -> 39.9 ms a frame), Wave Cascade +2.2%, Breakout Arcade +0.85%; in exchange 4-6 KB more internal heap with a module running, up to 9.9 KB.
- **Parked patterns give their memory back.** Least recently used first, whenever a new load would otherwise start with less than 4.5 MB of PSRAM free (the most one pattern may allocate, plus 512 KB), and whenever a running pattern's own allocation would leave less than 512 KB. A pattern installed, replaced or deleted - from the console, or by a feature that installs patterns - is never resumed from the old file. Checked on two boards with 12-13 modules parked: internal heap stayed flat, an install emptied the table and PSRAM came back by exactly the parked bytes (683 KB), and with five 1.5 MB test modules PSRAM never fell under about 3.1 MB free, with no refused load. `/api/status` gains `load.resumed`, `load.resumeUs` and `moduleMemory.resident`.
- **What this takes away:** a pattern that wants a fresh start every time it is picked cannot have one. `setup()` runs once per load, as `firmware/CUSTOM_PATTERNS.md` now says. A restart of the panel, or any install, delete or reorder on the Patterns page, is what starts one again.
- **The console is light, and its six core pages look like one thing.** It opens light; dark is still the toggle in the header, and a choice made there is remembered. Console, Patterns, Status, Wi-Fi, Knobs and Update now share one set of parts - buttons, chips, list rows, fields, notices, section titles - from a base block every page opens with (`console/README.md`, "The look"), with one accent, the LED orange, kept for what is live: the current tab, the playing pattern, the panel being on. The home page leads with the panel itself: what is playing with its arrows, on/sleep, brightness and the four knobs, with the device's facts under them in the same card; the arrow keys step through patterns as the arrow buttons do. Which edition the panel runs has a card of its own instead of being one more row among the facts: its name, its versions, the feature pages it carries as links, the update notice when there is one, and a button to the other editions (or a line saying the panel's own hotspot has no internet). The numbered index of every page with a paragraph each is now a list of one-line links. The header no longer scrolls sideways on a phone: Console and Patterns, the build's own feature pages, then Wi-Fi, Knobs, Update and Status, wrapped onto rows. Long explanations are a line, with the rest behind a disclosure where it is needed. Windows showed every small label in Courier New because no font in the monospace list was a Windows one; the list now includes Cascadia Mono and Consolas. The Knobs page has an *All* row that sets direction and edges per click for the four at once (it reads *Mixed* while they differ). The Status page shows the crash record (`crash` in `/api/status`) when there is one, with a button to clear it. Feature pages are not edited and take the light palette from the header. Home is 8.9 KB gzipped (was 10.9), Knobs grew by 0.15 KB for its All row, the others are within 40 bytes of what they were, and the header script is 9.6 KB. On a panel on the home network a page still opens in about 0.1 s the first time and in under 0.01 s after. Every request, control and message the pages had is still there; checked on a panel by stepping through patterns, sleeping and waking it, dimming it, dragging a knob and playing a pattern from the list. The guide's live console demo is regenerated to match.
- **The Audio page is a console page now: it says who has the knobs, and it saves only what you changed** (Audio edition). `/audio-in` was the one page the light console left behind: its own dark palette, 12 px type, square corners, a second brand line. It opens light like the rest now, with the console's buttons, chips and list rows, and it does not scroll sideways on a phone (checked at 390 and 320 px). Above the editor is a **Sources** list. *Microphone* has a chip that reads `off`, `starting`, `listening`, `not detected` (nothing on the data pin; the page says to check the DAT lead) or `not answering`, with the input gain beside it; a board with no microphone fitted used to look the same as a healthy one in a silent room. *Browser extension and phone app* is the Audio-React switch, the same one as `AUD` on the NETWORK screen, with `off`, `waiting`, `connected` or `phone app`, shown only on a build that has that path. The line at the top of the page says which of them has the knobs. It does not know about a knob pinned from the home page's sliders, MIDI CC 20-23 or `/api/params`; that knob stays pinned until its encoder is turned. Under it the mapping editor is the extension's, with what that gained in this release (see Tools): the knobs are K1 to K4 with their tabs under the plot, the level axis is in dB, and Preview takes the plot's place. On this page the line in each box, the cursor on the curve and the readout now show where the firmware has the level (`outputs` and `levelsN` from the poll); the page used to work that out a second time on its own dB scale, which is not the scale the firmware maps a hand-set window on. A panel that has heard nothing draws its stored windows dashed, where it drew four boxes flat on the axis. *Reset K1* asks the firmware for that knob's default: the page's own table of defaults was the extension's, and put a 5-16 kHz band on an axis that ends at 8. *Reset mapping* is pressed twice and says what it resets, in place of a `confirm()` dialog, which the phone app's WebView is not set up to show. Saving: nothing is written until the panel's mapping has been read. A read that failed used to leave the editor on the extension's defaults with nothing on screen to say so, and the next touch saved four default bands over the panel's own. An edit now sends the fields that changed, one request at a time - an Attack nudge is `attack=0.611`, a box's top edge is that band's `inMin` and `inMax` - where every edit posted the whole mapping, 41 arguments, and two open tabs wrote their stale copies over each other's edits. A save the panel did not take is said so, tried once more, and kept for the next change; an edit made just before leaving the page is still sent. Polling: the levels poll rides the console's shared lane (`PF.poll`) as every other page's requests do, so it waits behind an upload in another tab and slows itself on a slow link. Measured on the mock, about 9 polls a second with the microphone on, one every 1.5 s with it off (it had been 9.2 a second there too, for numbers that cannot change), one a second while the panel is not answering, and 0.6 a second on a link as slow as the hotspot. Weight: 17.2 KB gzipped as the panel sends it, where it was 19.9, because comments and indentation are dropped as the page is assembled; CI fails the page above 17.5 KB. `console_pages.py build` assembles the page as its first step, so there is one build command where there were two, and `console_serve.py` serves it assembled from its sources on every request against a port of the firmware's audio handlers, with `/mock?audio=` states for music, a quiet room, no microphone, a stalled one, the phone app and a read that never answers. Checked on that mock in Chromium, light and dark, with no console errors in any state, and on a panel with the microphone: the mapping stored on it survived the update, the page read before it wrote, one slider step posted one field (`attack=0.645`) and held across a reload, and frame time and microphone drops were unchanged with the page open. Not yet on a phone or in the phone app's WebView.
- **The Audio edition transmits at the core's Wi-Fi power** (19.5 dBm). It had been left pinned at 17 dBm when the core's 13 dBm cap was retired in 3.10.5, so it was the one build with less than full power.
- **A microphone that is not delivering no longer moves the knobs, and the microphone API takes one field at a time** (Audio edition). When the PDM driver did not start, or the microphone stopped returning samples, the analysis carried on over its built-in three-tone test signal and those tones reached the knobs, while `source` said `synth (mic stalled)`. The microphone now drives the knobs only while it is returning samples. `POST /api/audio-in` applies a band when any one of its suffixed fields is present; before, a request carrying only `inMax2` was answered `{"ok":true}` and changed nothing, because only `hzMin`, `lut`, `knob`, `muted` or `outMin` counted as naming a band. A `band` outside 0..3 is refused with `400` before anything else in the request is applied. `POST /api/audio-in/reset` takes `band=N` and resets that band and its curve alone, naming it in the answer; a full reset now includes `attack`, and still leaves the microphone switch and auto range alone. `hzRange` is printed to two decimals (`31.25`, the bound a band is really held to). The poll reply is built in one allocation where it grew through about forty, ten times a second. Nothing is removed or renamed: the phone app reads the same configuration it did, and `d=` stays in the WebSocket protocol for earlier extensions. Static RAM is what it was (161,216 bytes of DRAM, the pinned figure). `docs/rest-api.md` describes the microphone endpoints field by field, including what had been there unwritten (both spellings of a band field, `smoothing`, `attack`, `meta`, `lut`, `env`, the phone's `frame` post, every `source` string, and that a body sent without the form `Content-Type` is not read, which turns a `band=2` reset into a reset of everything). `docs/audio-ws-spec.md` 1.1 states the 500 ms lane release that version 1 said did not exist, and which senders hold a value through it: the extension does, the Android capture app does not yet. Checked on a host by running the old and the new handlers on the same requests (78 assertions), by building every composition, and by the one-field post above on a panel.

### Web

- **The guide has a fourth part: Audio** (`/guide/audio`, Korean at `/guide/audio/ko`). Getting the Audio edition onto the board first, then three sections in no order: sound from a browser tab, the on-board microphone, and MIDI with a DAW (network MIDI, Ableton Live as the worked example). The browser section runs the extension's own mapping editor on its demo source, and the boxes drawn there turn the knobs of the 3D board; a hand on a knob takes it for five seconds, as on the real one. The rest is captures of the real pages and the two photos of the microphone. OSC, the phone app and the Director's `.mid` export are links at the end. The hub (`/guide`) has four cards.

### Docs

- **The microphone is five leads on four places, and the docs say so.** `AUDIO_GUIDE.md`, the Audio card on `/editions` and `firmware/bundles/README.md` said four wires; GND and SEL both go to GND, which makes five. `AUDIO_GUIDE.md` also names the Audio page's editor by its heading, **Mapping**.
- **The MIDI console page points at Live's current settings page** (Settings → Link, Tempo & MIDI, not Preferences → MIDI) and no longer mentions a MIDI row on the board's NETWORK screen: that screen shows the first two switchable features, and on the Audio edition those are OSC and AUD. `docs/midi-spec.md` says the same.

### Tools

- **The audio extension holds the knobs through silence, and Live means the panel is being driven** (`tools/patternflow-audio-extension`, 0.2.0). The panel hands a knob back to its encoder 500 ms after the last message that set it, and the extension did not send a frame equal to the last one. So half a second into a silent tab, a paused track or a Gate curve resting on one step, the knobs were let go while the popup said Live: measured, not one message in ten seconds of silence. It now sends an unchanged frame again about every 210 ms (five a second, no gap longer than 223 ms), and the knobs rest where each band rests until Stop. A knob turned by hand during a pause goes back there when its five-second hold ends, and a microphone that is also switched on does not get the knobs during a pause. Owner's decision. Muting a knob hands it back at once (`off=N`), where it waited for the panel's timeout. *Live* used to mean the socket was open, which it also is on a panel whose Audio-React switch is off and which ignores every frame; the extension now asks the panel once when the socket opens (`GET /api/audio`), and off reads *Aud off* with a **Turn on** button. A socket that will not open is explained, where every failure read "WebSocket error": no panel at that address, a panel that does not run the Audio edition, or something that answers and refuses the socket. A silent tab reads "No sound from this tab yet." The popup has one button, Start until a tab is captured and Stop while one is; *Release knobs* is gone (Stop does that), and *Test without audio* holds each knob where its slider is put. The address is taken on Enter, on leaving the field and on Start, where it reconnected on every keystroke (typing `192.168.0.42` tried `192.168.0.4` on the way), and it has a storage key of its own, so an editor tab left open no longer writes an old address back. Closing the captured tab ends the capture and says so, and a restarted service worker no longer shows Idle over a running capture. The frequency labels under the popup's spectrum sit where their frequencies are ("1k" had been over 317 Hz). In the mapping editor the bands are K1 to K4 everywhere, the knob tabs sit directly under the plot, the level axis and the curve's readout are in dB, and the hints are plain sentences ("This band still runs its old boost curve", on a band nobody had touched, is gone). A new install starts with Auto range on and the Smooth curve, as the panel does and as `AUDIO_GUIDE.md` already said; a mapping that is already stored keeps what it has. Switching Auto range off goes back to the windows set by hand, where it replaced all four with wherever the boxes were; dragging a top or bottom edge is what takes them over. Preview puts its scope where the plot is, so the sliders, the curve and the output range it demonstrates stay in reach, where it was a dialog over them. The editor holds together at half a screen's width, and on a touch screen a swipe that starts on an empty part of the plot scrolls the page while one on a box drags it. One model (`mapping.js`) holds the defaults and the level-to-knob arithmetic for the capture, the popup, the editor and the panel's page, where the first three each had a copy. The extension keeps its cream skin. After pulling, press Reload on `chrome://extensions`; the card should read 0.2.0. Reload keeps the stored mapping, so a copy you already had opens as it was, which unless you had changed them is Auto range off and no curve: for the new defaults, press Reset on each of the four knobs in the editor and switch Auto range on, or remove the extension and load it again (which also forgets the panel's address). Checked with the unpacked extension in headless Chromium against a loopback socket and a stand-in for the panel's HTTP side (44 popup checks, and the wire in each state), and against a panel: a tone in the captured tab swung K1 between 0.30 and 0.85, four seconds of silence left the lanes held at their rest value where they used to be released after half a second, switching Audio-React off on the panel turned the popup to *Aud off*, and Stop handed the knobs back to the microphone. Touch was tried only in emulation, and the panel requests only in the Chromium Playwright ships, not in a current Chrome with its local-network permission prompt.

### Patterns

- **Installed patterns run faster, and nobody has to edit one.** A pattern on a panel is a small compiled program (a `.pfm`). Two things about how it was compiled were costing frames, and both change where a module is built:
  - It was built for size (`-Os`), on a note in the SDK that `-O2` bought about 2 %. Modules are now built at `-O2` (`build_module.py`).
  - Every `floorf`, `ceilf`, `truncf`, `roundf`, `fminf`, `fmaxf` and `fmodf` in a pixel loop was a call out of the pattern into the firmware's maths library: 185 to 840 ns each as timed (`truncf` was not), 8,192 pixels a frame. The module SDK now gives those seven inline code (`abi/pf_libm.h`), so a header that calls them per pixel - most community patterns do - stops paying for the call.

  Frame time on one board, in one boot. The Basics presets as they are today, GCC 8.4:

  | | 0510 | 0512 | 0515-4 | 0520 | 0531 | 0601 |
  |---|---|---|---|---|---|---|
  | `-Os` | 11.9 ms | 23.2 | 15.0 | 23.4 | 13.7 | 15.0 |
  | `-O2` | 10.3 ms | 22.6 | 11.2 | 19.7 | 12.4 | 13.6 |

  That is 3 to 34 % more frames a second; GCC 14.2 at `-O2` was another 1 to 8 % faster. Four presets as they stood before they were tuned by hand, with `floorf` and `fmodf` per pixel:

  | | 0510 | 0515-4 | 0520 | 0601 |
  |---|---|---|---|---|
  | built as before | 14.8 ms | 25.3 | 26.9 | 26.0 |
  | `-O2` | 13.3 ms | 23.7 | 23.1 | 24.5 |
  | `-O2`, maths inline | 10.3 ms | 17.5 | 20.3 | 20.2 |

  The last row was measured with a first version of the header. With the header as committed, all 147 distinct public community patterns build (the old recipe's compiler crashed on two of them), and each was loaded and run on a board: no reset, no refused load.
- **What is exact, and what is not.** The seven functions are exact: for every input, each returns the bits the library function returns. Each computes inline only the inputs that have one right answer, and hands the rest - a NaN, an infinity, a magnitude past the range its proof covers - to the call the pattern made before. `check_libm.py` holds them to that in CI: all 4,294,967,296 floats through `floorf`, `ceilf`, `truncf` and `roundf`, 419 million pairs through `fminf` and `fmaxf`, 481 million through `fmodf` by each of its two paths - twenty billion comparisons, no mismatch, under GCC with sanitizers and under MSVC. `check_module_libm.py` then reads a module the real compiler built, to see that this code is what a pattern's calls became, and `tests/modules/_math_probe` is the module that checks on a board what no PC can: that the panel's multiply-subtract is fused. It reported `math ok 9/9` on a board, over 1.17 million comparisons against the firmware's own library. One footnote: for `fminf`/`fmaxf` of a zero against a zero, or of a NaN, "the call the pattern made before" means what that call got from this compiler, which is not always newlib's answer for the arguments as written - GCC answers a call with constant arguments itself, and GCC 12 and later may swap the fallback's operands.

  What is not exact is the pattern's own arithmetic. `-O2` and inline code both move where GCC fuses `a*b+c` into one instruction (`-ffp-contract=fast`), so a value in a rebuilt pattern can differ in its last bit from the build before. Two cases, worked through:
  - The cell hash written as one line, `sinf(floorf(x)*12.9898f + floorf(y)*78.233f)*43758.5453f`: 20 of 128 cells hash differently.
  - A helper that ends in a multiply and that `-O2` inlines - a smoothstep: `mul.s` then `sub.s` becomes one `msub.s`.

  It shows only where a pattern amplifies the last bit: a float hash, state carried between frames, rarely the edge of a `floorf` band. Of 168 public community headers, one uses the 43758 float hash; 21 use the integer `PFNoise::cellHash`, which is unaffected.
- **The Basics pack is rebuilt**, for the first time since 15 August: the same 33 patterns in the same order, from today's preset sources, at `-O2`, with the firmware's own compiler. Against the August binaries on the same board, every one of the 33 is faster: 1.11 to 2.36 times the frames a second, 1.52 at the median (47 fps to 77 across the pack).

  | | 0510 | 0512 | 0515-4 | 0520 | 0531 | 0601 |
  |---|---|---|---|---|---|---|
  | August pack | 18.1 ms | 25.1 | 26.1 | 34.4 | 15.5 | 28.5 |
  | rebuilt | 10.3 ms | 22.6 | 11.1 | 19.7 | 11.1 | 12.7 |

  It is also the first rebuild to carry the two SDK fixes of 3.10.1, and those change what is drawn. `cellHash`'s seed decorrelates, so Firefly Hollow and Midsummer Sea get a different random stream. `hsvToRgb` rounds, so the 16 patterns in the pack that colour through it are up to one level brighter on a channel. The pack is 166 KB where it was 122, and holds 104 KB of code where it held 63.
- **What the new builds need from the firmware.**
  - **3.5.1 or later, for Basics.** Its modules are now stamped for the parameter bus (descriptor 2, where August's were 1), so a show can drive them - and firmware 3.2.0 to 3.4.0 refuses all 33. Update the firmware *before* reinstalling the pack: reinstalling replaces files that load with files that firmware will not.
  - **3.10.5 or later, for the larger ones.** Firmware before 3.10.5 places a module's code in internal RAM, and the new builds are larger: 1.36 times the code at the median, over 145 community patterns built both ways with GCC 8.4. Thirteen of those 145 fitted an Audio build's budget of about 7.8 KB before and no longer do; nor does Breakout Arcade in Basics, at 14.2 KB where it was 5.4. From 3.10.5 code runs from PSRAM, and its size does not decide whether a module loads.
  - Nothing else: a module built this way imports only names every loader since 3.2.0 resolves.
- **What you have to do.** A pattern already on a panel keeps the build it was installed with; nothing is rebuilt on the device. Update the firmware if the list above says to. Then install the Basics pack again from the site, and send a community pattern or a deck again: the community server keeps one build of each pattern, keyed by everything that goes into a build, so once it is redeployed each is compiled again the first time someone asks for it.
- **A module is 2.7 % slower than the same pattern compiled in, not 20 %.** The SDK said 20 % (a 2026-07 measurement: Origin, 53 fps against 43) and blamed the relocatable code model. Measured again on one board, A-B-B-A in one boot: Origin compiled in draws a frame in 9.56 ms, Origin as a module in 9.81.

## [3.10.5] - 2026-10-02

### Firmware

- **A panel that crashed says where.** `resetReason` in `/api/status` said `"panic"` or `"task_wdt"` and nothing else - not where, and not which of forty installed patterns was on. The SDK had been writing a core dump to its own flash partition on every panic all along, and nothing read it. At boot the firmware now reads that dump's summary - the task, the cause, the faulting address, the PC and up to sixteen return addresses, and the hash of the image that crashed - and it keeps a breadcrumb through the reset: the pattern's slug, which of its calls was running (loading, constructors, `setup`, `update`, `draw`, or none of them) and where the module's code was executing from. Status gains a `crash` object with both. With the two together an address inside a module comes out as an offset (`"+0x4e"`) that the `.pfm`'s own symbol table resolves, whether the code ran from PSRAM or from internal RAM. `DELETE /api/crash` clears it, and the same record is printed on serial at boot (`[CRASH] ...`). It reports and does nothing else: no pattern is skipped, no reboot is forced, and what the panel does after a crash is what it did before. The breadcrumb covers the boot that follows a panic or a watchdog and is gone with the power; the dump stays in flash, so a board that panicked on an older firmware shows that dump, marked `fromThisReset: false`, until it is cleared. Checked on a board: a module stored through a null pointer in `draw()` while running from PSRAM, and after the reboot status named the pattern, the phase, `pc` `+0x4e` and the caller at `+0xb6` - the offsets the module's own symbols give for those two functions - with the dump read in 62 ms; a dump left by an earlier firmware appeared as `fromThisReset: false`. It costs 296 bytes of internal RAM. `docs/rest-api.md` ("The crash record") says how to read one and decode it, and `firmware/toolchain/check_crash.py`, a new host check, boots the logic through every reset reason against every state of the breadcrumb and the dump; CI runs it.
- **Every pattern is 2.45 ms a frame faster.** Copying a finished frame to the panel's bit-planes was the largest fixed cost in the loop: 5.96 ms of every frame, nearly half of Origin's. The kernel was one long loop with more live values than the CPU has registers and a plane count it only learned at run time; it is now three short passes with the 8-bit case written in, 390 instructions a column pair where there were 635, emitting exactly the same words (`check_blit.py` compares 70 million of them). Measured on two boards, alternating images: `presentUs` 5,960 -> 3,496 µs on the default and Audio editions alike, so Origin goes from 12.1 to 9.6 ms a frame and a 30 ms pattern to 27.6. With white balance or gamma tuned away from the defaults it is 3.8 ms. It also takes 1 KB less internal RAM than the loop it replaces. `/api/status` gains `loopStackMin`.
- **A pattern's code no longer competes with the network for memory.** A loaded module's code used to need one contiguous block of internal executable RAM - the same RAM the console, lwIP and every feature run on - because "the S3 cannot execute from PSRAM". That is true only of the address the heap hands back: on the S3 the instruction and data buses share one MMU table, so the same PSRAM page can be fetched at that address + `0x06000000`. The loader now places code in PSRAM, writes and relocates it through the heap's pointer, and runs it through the alias (`src/core_module_memory.h`, `execAddress()` in `src/core_module_loader.h`). On the Audio edition a module with 23 KB or 32 KB of code was refused and now loads, and internal heap with a module resident is about 27.8 KB whatever the size of its code, where a 10 KB one used to leave 21-23 KB. On a second panel a community pattern with 8 KB of code was being refused one load in four for want of 528 bytes; it now loads every time and leaves 29 KB free instead of 22. Measured on two boards, same boot, alternating: catalogue and community modules within -0.1..+1.2% of their old frame time; modules built to be the worst case (10-32 KB of code, all of it executed every frame) 2.6-5.3% slower; 400 switches between modules of different sizes with no reset and no refusal. The code block is given whole cache lines to itself, the load reads it back through the instruction bus before calling it, and a unit on which that ever fails goes back to internal RAM until reboot (`moduleMemory.codePolicy`). `load.code` in `/api/status` says where the code is. Module files and the ABI are unchanged.
- **A request that stops half-way can no longer reboot the panel.** A multipart `POST` that ended after its first boundary - to any address, not only an upload - left the web server's form parser reading empty lines for ever with nothing to wait for, and the Core-0 watchdog reset the board five seconds later. The parser now knows a line that never ended from a blank one and gives the form up, tells an upload handler whose file had already arrived that it was aborted, and leaves none of the form's fields behind to answer for the next request (`src/webserver/VENDORED.md`, Fix 4). Reproduced on a panel before, gone after.
- **Three more requests that could reboot it, found on a PC first.** `curl -X POST` to `/api/patterns` or `/update` with no form in it called the upload handler with no upload to read and panicked the board; a multipart request naming a 9,000-character boundary overflowed the network task's stack; and a raw `PUT /update?size=N` never saw its own `size`. All three are fixed in the vendored server (`VENDORED.md`, Fix 5), and all three came out of `firmware/toolchain/check_parser.py`, a new host check that replays cut-off, stalled and malformed requests - 13,953 of them - through the real parser and fails if it ever spins or holds; CI runs it.
- **A quote in a pattern's name no longer breaks the pattern list.** `/api/patterns` wrote names into its reply unescaped, so one `"` or `\` in a title made the whole reply unparseable and the `/patterns` page could not list, select or delete anything - including the pattern responsible. Names are escaped now, a sidecar name is read as the JSON string it is - an escaped quote no longer ends it, and `\uXXXX` becomes the character, so "Dynamic Moiré" is that before the pattern has ever been loaded and not only after - and a name too long for its slot is cut between characters rather than through one. The hotspot password got the same escaping in `/api/hotspot`.
- **A module's global constructors can use the host.** They ran before the module had been handed its host API, so a pattern with a namespace-scope initialiser that allocated, logged or asked for a random number (`float* trail = PFMem::allocFloats(n);`) crashed the panel every time it was picked, having built and uploaded cleanly. Constructors now run after the entry point and before `setup()`.
- **Lanes keep working past day 25.** The five seconds a knob keeps to itself after a hand touches it was timed with a signed compare meant to survive the 49-day millisecond wrap; what it did was move the wrap to 24.9 days, after which a lane on any knob not touched since was held off for the following 24.9. A panel left alone would have stopped answering its microphone (Audio) or its weather (Performance) on day 25. Found by reading, not by waiting: the hold is a flag that ends once now.
- **A pattern that never returns no longer takes the console with it.** A module's `draw()` runs on the render loop, and the render loop is on no watchdog: one `while (a > PI) a -= 2 * PI` on a value that has reached infinity - which float32 does where the browser's doubles did not - and the panel holds its last frame for good. The first console request that needed the loop then waited for it without limit, and the `/patterns` page opens with one; the server answers one connection at a time, so `/api/status`, `/update` and Reboot, which need nothing from the loop, went silent behind it, and a frozen panel could be neither diagnosed nor restarted without pulling the plug. A request now gives the loop up once it has not reached its frame boundary for 20 s (`PF_LOOP_STALL_MS` - measured from the loop's own stamp, not from how long the request has waited, so an upload waiting out a slow `setup()` is not mistaken for it) and answers `503 render loop is not answering`; the request is taken back with one atomic exchange, so the loop can never run it on a stack frame that has already returned. `/api/status` carries `loopAgeMs`, `loopStalled` and `loopSyncGaveUp`, read without the loop's help, and every handler in the core and in the features answers the refusal instead of using what its body never set. The Status page says "not answering for 47s" in red, where it would have gone on showing the frame rate from before the stop under "awake". Nothing restarts the panel by itself: this reports and survives, and the Reboot button does the rest. Twenty seconds is clear of one feature lookup with the internet down and not of two in a row, so on Performance with a dead uplink a healthy panel can read "not answering" for some seconds and then carry on - which is why it does not say "hung". The console has to have come up once for any of this: its routes are registered by the loop on the first network link. Found by reading - no stock pattern hangs - then reproduced on a panel with a module that hangs on purpose: before, the pattern list got no reply and after it neither did status, until the board was reset over USB; after, the list answered 503 in 18 s, sixty more requests were refused at once with the heap unchanged, the Status, Update and home pages still loaded, and Reboot brought the panel back. Held by a host test that races the two sides against each other; `firmware/toolchain/tests/modules/_hang_probe` is a module that hangs on purpose, for the bench (`src/core_loop_sync.h`).
- **No more stray letters on the panel's own screens.** A portrait line holds ten characters, and Adafruit GFX wraps an eleventh onto the next line by itself: the KNOB MAP's "TURN = SHOW" put a lone "W" in front of "K3 = EXIT", the install screen's "web console" did the same, and the default host name "patternflow" lost its "w" on the hotspot and UPDATE screens. The labels are shorter now ("TURN=SHOW", "console"), and names that can be longer than a line are broken into lines of ten by `drawCenteredFit` — "pattern" / "flow-a1b2", "pattern" / "flow.local" — keeping every line where it was.
- **A deck sent from the community's dock keeps its order.** The console's one-click install from a link (`/patterns?src=`) took only `.pfm` and `.json` from a build's file list, so the `catalog.txt` every deck build carries was left behind and the deck landed in alphabetical order. It now takes exactly what a dropped zip does (`catalog.txt` and `.pfs` too) - one rule, `installable()`, for every way in.
- **A firmware upload survives a Wi-Fi hitch.** The `/update` connection now waits up to two minutes for a stalled upload instead of five seconds, and the page gives up after five minutes with a message instead of waiting forever. Checked on a panel with a 12 s stall halfway through a flash. `PUT /update` takes a raw image, for `curl -T`. From Simone Majocchi ([#450](https://github.com/engmung/Patternflow/pull/450)).
- **Two 64×64 modules chained make a 128×64 panel.** `PANEL_GEOMETRY` in `config.h` picks the stock 128×64, one 64×64, or two 64×64 daisy-chained (the `firmware64x2` PlatformIO env). The driver is told the module and the chain, and everything else sees the canvas; the stock build is unchanged. From Simone Majocchi ([#446](https://github.com/engmung/Patternflow/pull/446)).
- **Performance v0.4.0 carries the clock and a Weather face**, and its show catalogue holds 100 sequences instead of 48. An MQTT subscriber following a fast sequence stream now drains the broker and applies the latest value per knob each frame instead of falling one message per frame behind (a jump of more than 16 clicks in one frame is capped), and a publisher no longer replays its own retained snapshot when it reconnects. From Simone Majocchi ([#445](https://github.com/engmung/Patternflow/pull/445), [#448](https://github.com/engmung/Patternflow/pull/448), [#449](https://github.com/engmung/Patternflow/pull/449)).
- **The panel is a network of its own.** With no known Wi-Fi in reach it raises a hotspot, `patternflow-a1b2` (its alias), WPA2, password `patternflow` until changed, and the whole console is at `http://192.168.4.1/` on it - patterns, knobs, the Wi-Fi page to add the next place's network, updates. Modes on `/wifi`: `auto` (default: up fifteen seconds after the last link, down once a network is joined and nobody is on it), `always`, `off`; `GET`/`POST /api/hotspot`, and a `hotspot` object in status. The NETWORK screen shows the name while the hotspot is what there is. What the bench decided (`src/core_hotspot.h` says why, line by line): the channel comes from a scan - the least loaded of 1/6/11 - never a fixed one; alone, the radio runs AP-only, and the station comes back only for a rare probe with nobody connected or when credentials arrive; a DNS responder on the hotspot resolves every name to the panel and the phone's internet probe fails within a second instead of timing out for twenty; the hotspot is 20 MHz. Pretending to be the internet was tried and put a Samsung into its limited-connectivity state, which drops the network.
- **Console services start on any link.** Every core page, and the audio, microphone, clock and MQTT pages, used to wait for `WL_CONNECTED` before registering - on the hotspot a phone got an address and port 80 never opened. `PatternflowWifi::linkUp()` is the condition now, the station or the hotspot, and the hotspot raises the same link edge the station does.
- **Full transmit power.** The 13 dBm cap from 2026-08 is retired (`PF_WIFI_TX_POWER` is the radio's 19.5 dBm again). Measured on the hotspot: a phone next to the panel took 4-9 s per 10 KB page at 13 dBm and under a second at full power - the phone's own transmitter had hidden the asymmetry, and a router's antenna had hidden it on the home network. Owner's decision.
- **Switching console tabs no longer downloads the page again.** Page addresses carry the firmware's build (`/patterns?v=2a535f30`), and a page asked for under the running build is cached for good - a second visit to a tab costs no request at all (measured on a panel: `/patterns` 15.5 KB in 335 ms the first time, nothing and 16 ms after). A new build is a new address, so an update is never answered from an old copy; an open console notices the new `build` in `/api/status` and moves to it by itself, unless you are in the middle of typing or an upload, when it offers a reload instead. Pages without `v` revalidate every time (`ETag` + `304`), an old `v` gets a `302` to the current one, and the shared header script is addressed by its own checksum (`/pf-console.js?h=…`, stamped in by `console_pages.py`). Only names that can only be the panel - an IP, a bare name, `.local` - are ever given a cache lifetime: the hotspot answers every DNS name, and a phone must not keep the console as someone else's site. On a home network the other tabs are fetched in the background once the page is idle, so even a first visit is instant; not on the hotspot, where the link is the scarce thing. `/api/status` gains `build`, `viaHotspot` and `busy`, and escapes the network's and pattern's names (an SSID with a quote in it made the reply invalid JSON).
- **One header for the whole console, and one way to talk to the panel.** The shared header now lives in a shadow root, so no page's CSS moves it - it had a different height, width and position on every tab, which is most of why switching felt jumpy. On a phone it is two fixed rows with the tabs in one sideways-scrolling strip (Knobs is a tab now), and it says when the panel is not answering, restarting, or has been updated. Pages reach the device through `window.PF`: polls wait for the previous reply, back off on a slow link, pause in a hidden tab and stop the moment you tap another tab, so the next page is first in the one-connection server's queue; the page's own requests go before the header's status request; uploads hold everything else back and ask before you leave. A small fallback is stamped into every page, so a page still works if the header script fails to arrive. `console_serve.py --slow` makes the desk as slow as the hotspot (round trips, a 5.7 KB TCP window, one request at a time) to design against.
- **Setting the panel up from its own hotspot.** `/wifi` puts *Add a network* first when you are on the hotspot or nothing is saved, lists the networks the panel's channel scan saw so you can tap one instead of typing it, stops a case-only typo with an inline "did you mean" before it is saved, and reports what became of the network: joined, with the address to open, or why not - wrong password, not found, refused, no answer - on the page and on the panel's LEDs. On the hotspot with no station link, a network sent from the page is tried at once. The console's pages were gone over for phones on the way: sliders that let the page scroll, inputs that do not zoom iOS, `accept="*/*"` for the Android file picker, the hotspot shown as what it is instead of "offline", a status page that copies its diagnostics, an update page that confirms the new version after the reboot.
- **`always` no longer keeps the panel off its network after a boot.** Raising the hotspot starts with a channel scan, and the scan cuts the station's first connection attempt short; with the hotspot up the station is retried only every five minutes, so a panel set to `always` with good credentials sat off its network for five minutes after every boot (the console looked dead from the LAN). The hotspot now gives the station one attempt the moment it is up - on the bench it joined 1.4 s later - and goes AP-only only if that fails. The console also stopped calling a slow link dead: one reply over the timeout (now 12 s at least, not 5) no longer turns the header's state to offline, two failures in a row do - with the hotspot and the station both up, pages took 4-5 s and the console read "offline" after the first one.
- **The console's server waits one second, not five, for a connection that sends nothing.** A browser opens connections it never uses; each idle one held for 5 s put the page's real requests behind it, which on the hotspot was the console appearing only after the browser gave up on its spares.

### Web

- **A guide you can play along with, in three parts, at [/guide](https://patternflow.work/guide)** (work in progress, marked WIP). `/guide` is where you pick one by where your Patternflow is, each with its chapters, in order. **Build**, at [/guide/build](https://patternflow.work/guide/build), is for soldering one from bare parts: 01 Gather (the parts list is `bom_v3.9.csv` itself), 02 Order & print, 03 Solder, 04 Into the case, 05 Wire & power, 06 Firmware (which hands over to Play's 01 Flash) and 07 Check & close, each step played on the real v3.9 board and case in 3D, in the order the build happens; the board's known issues stay in `BUILD_GUIDE.md` §10, linked. **Play**, at [/guide/play](https://patternflow.work/guide/play), is the first hour with a built one, 01 Flash, 02 Knobs, 03 Patterns, 04 Console, on the real v3.9 hardware in 3D, running a port of the firmware's input logic and screens, with the real flasher dialogs and a live copy of the device console. **Make**, at [/guide/make](https://patternflow.work/guide/make), is 01 Community and 02 Pattern Lab, done by hand: on a big enough screen your own Pattern Lab, a practice community (placeholder patterns, connected to nothing) and a practice AI with set answers sit beside the steps, and a pointer shows each move and waits for yours; phones get the real screens. Sound, MIDI & OSC, MQTT, Clock, Performance and Editions join Make as they are written. Each guide numbers its own chapters from 01. Links into the first version, when Play was `/guide` itself (`/guide#flash`, `/guide#knobs-3`), land on the same step under `/guide/play`. English and Korean. Every step has a "Stuck here?" link to a GitHub issue that already says which guide, chapter and step (`guide_stuck.yml`). The 3D stage is one continuous world: moving between the hub, Build and Play is a scene rather than a page load, and pointing at a guide on the hub previews it on the device (Build comes apart, Play turns a knob, Make redraws the panel). The LED panel lights the room with the pattern it is playing, and the page's accent follows that colour. Pretendard is now served in four script-range files, so an English page no longer downloads the Hangul glyphs (a Korean page renders identically). README, BUILD_GUIDE, PATTERN_GUIDE and the assembly map link to the guide.
- **The community's Performances note says .pfs**, which is what the Director saves, instead of "Save-JSON".
- **A moderator can take a pattern or deck off the wall without deleting it.** Somebody else's public pattern or deck now offers moderators *Make private*, with an optional reason: the softer removal, for things like the same pattern posted a fifth time. Nothing about the work changes and its author keeps it — they can still open it, edit it, take it into the lab — it just stops being shown to anyone else. On a pattern the reason is posted underneath as the moderator's comment, where the author can answer it; either way the author is told in their alerts. While the take-down stands the author cannot make it public again (a take-down its subject can undo in one click is a request); *Restore to public* puts it back exactly as it was. A moderator still cannot publish what an author made private themselves. A deck slot left empty by a take-down reads "made private by a moderator", not "by its author". Moderators can now comment on private patterns and keep their alerts about them, so the thread under a take-down works both ways. Migration `0025` adds `hidden_at` to patterns and decks; `check:hidemod` drives it all through the real routes.
- **One press of Publish is one post.** A double-click on *Publish to the wall*, or a mouse switch that bounces, could put the same pattern on the wall twice in the same second ([#455](https://github.com/engmung/Patternflow/issues/455)). The button's disabled state was React state, a render too late for the second click, and after a successful publish it came back enabled while the page changed. The publish, thread, reply, deck, header, performance and report forms now refuse a second press in the same tick (`useSubmitLatch`), and a published pattern keeps its button down until the page changes; a thread whose files failed to attach offers *Open the thread* instead of posting it again. Behind them the server answers an identical submission from the same account within a minute with the post it already made, looked up and inserted in one synchronous transaction so two requests arriving together cannot both get through. `check:publish` fires two identical publishes into the route at the same instant; a version that awaits between the lookup and the insert fails it.

## [3.10.4] - 2026-09-19

### Firmware

- **The panel refreshes at exactly 300 Hz, because that is what a phone can film.** A row is lit once per refresh for 1/32 of it - a pulse, not a glow - so a rolling shutter collects a whole number of pulses per sensor line, and unless the exposure is an exact multiple of the refresh period some lines get N and some N + 1: bands. Phones pin exposure to 1/50, 1/100, 1/25 or 1/60, 1/30 to dodge mains flicker, and 300 Hz is the lowest rate all of those divide. 3.10.3's 325.5 Hz sat close to the worst case for both 1/50 (6.51 periods - the whole picture banded) and 1/60 (5.43), and it showed: more lines on video than the 260 Hz it replaced, which had happened to sit nearer whole numbers. Every frame now ends in 4,181 blank clocks, output off, bringing it to 16 MHz / 300 = 53,333. Simulated band contrast at 1/25, 1/30, 1/50, 1/60 and 1/100 goes to zero, and it looked that way through a phone. It costs about 8% of the light and no CPU at all - the DMA engine walks the chain by itself; frame and push times on the panel are unchanged. **1/120 and faster still band**, at any rate this clock can reach (that would take 600 Hz), and so does slow motion: lock the shutter at 1/60 or 1/50, or turn the panel down so the phone lengthens its exposure. `PF_TARGET_REFRESH_HZ` (0 to switch off); never pads below `min_refresh_rate`. The old claim in `firmware/README.md` - past 240 Hz a camera "averages 4+ cycles and the bands disappear" - was wrong, and is replaced with how it actually works.

## [3.10.3] - 2026-09-17

### Hardware

- **v3.9 board** (2026-09-04). The USB-C power receptacle `USB1` and its CC pull-downs `R1`/`R2` — which v3.0 shipped and every document told you to leave unpopulated after the delayed burnout in [#221](https://github.com/engmung/Patternflow/issues/221) — come off the board. `J4`, the screw terminal, is the only power input there is. Edge cuts and mounting holes are byte-identical to v3.0, so the v3 cases fit both. The 330 mm case gains a pass-through to the DevKit's USB port (data, for wired MIDI/OSC and flashing — not power) and a cable exit slot. Gerbers, BOM, renders and schematic regenerated; `bom_v3.9.csv` is the BOM source of truth.

### Firmware

- **Purple and sky-blue fringes round bright edges are gone, greys stop reading pink, and the panel refreshes at 325 Hz.** A plane's bits are on the LEDs while the *next* buffer in the DMA chain clocks in, so the OE window written into buffer `b` lights the plane latched before it - the driver's own `clearFrameBuffer()` says so. 3.10.1 read upstream's full window on buffer 0 as an LSB bug and shrank it; it was the top plane's display time, and raising a code from 127 to 128 then lowered the light by 42% (upstream: 28%). On a pattern with a near-white background each channel crosses that code at a different point along every edge that fades to dark, so edges grew a purple and then a sky-blue fringe. 3.10.1's analysis was also made at transition bit 0; this panel ran at 4. Upstream's chain cannot be made binary without throwing light away - solved exactly it keeps 42% of the row lit, and on the panel that was too dark - so the chain is new as well: twelve buffers a row (`0 1 2 3 4 5 6 7 6 7 7 7`) instead of fifteen, windows `1, 1/32 … 1/2, 1, 1`, exactly binary, 66% of the row lit (upstream, not binary: 80%) and 325 Hz where it was 260. `begin()` now picks a chain *scheme* against `min_refresh_rate` rather than a transition bit: a slower clock costs brightness, never colour depth. `oe_test.cpp` walks the chain itself instead of sharing a formula with the driver; the 30,000 assertions that passed 3.10.1 had modelled delivered light the same wrong way. Checked on hardware at every step by switching builds. The power clamp's full-white figure was measured on upstream's windows and now over-estimates by about a fifth; left alone until measured. **White balance is identity again:** `LED_WB_*` 0.930 / 1.000 / 0.975 had been converged by eye at full white on top of upstream's weights, so it corrected the driver at one level and not the panel; it read pink across the greys, and the reference panel uncorrected reads neutral (checked on the GRAYS screen). A panel that carries its own `LED_WB_*` in `patternflow_secrets.h` should re-judge it. `/panel-tuner.html?device=<ip>` connects straight to a panel.
- **Knobs page.** `/knobs` on the device console, and `GET`/`POST /api/knobs` behind it: which way each encoder counts and how many edges make one click, per knob, with a live readout to check against. These are properties of the part soldered in - some encoders count the other way round, some give two edges per detent - and until now the answer was `INVERT_ENCODER` in `config.h` and a rebuild. Stored on the device; a saved change does not move the knob. The Live guide also gains the one setting that made a wired or wireless MIDI knob pin itself and tick: *Remote* on the port's Output row sends every mapped value straight back.
- **The Clock edition leaves the shelf.** The clock is a feature; `bundles/clock` stays in the tree as a composition CI keeps compiling, and its last image, `clock-v0.1.5`, stays on the v3.10.2 tag. The shelf is what its maintainer stands behind — Core and Audio, and Performance from its own — and it is short on purpose.
- **An edition ships on its own.** `release.py edition <name> vA.B.C` bumps, shelves, points the card and commits: one command for an edition's maintainer to cut from a pull request, with no core release in between. Firmware CI builds the five compositions in parallel, one job each, and pins each one's static RAM.
- **MIDI edition** (`firmware/bundles/midi`, v0.1.0): the DevKit's USB port as a class-compliant MIDI device, beside RTP-MIDI — plug the panel into a computer with the cable it is flashed over and it is a MIDI port named `Patternflow`, no driver and no session. Same map as every transport (`docs/midi-spec.md`); `midiUsb` in `/api/status`. The port has to be the S3's USB-OTG controller for a MIDI device to exist, which is a build flag the other images cannot carry (it is what makes the port their serial console), so the edition builds in its own PlatformIO env — `env`, the third file a bundle may now have. Data only: the panel is powered from `J4` as always. In the tree and built by CI; not on the shelf yet.
- **Storage errors say why.** An upload whose destination will not open reports `errno`, so a missing `/patterns` (ENOENT) reads differently from a volume that will not write (EIO), and storage is diagnosed again after a successful mount, so a later failure carries a reason instead of an empty `fsError`. From RayWolters' investigation on [#424](https://github.com/engmung/Patternflow/issues/424).

### Web

- **The features page.** `/features` is the catalogue the shelf never was: every feature as one row — name, one line, and a tag saying where it lives (every firmware, Audio, Performance, a recipe in the tree, or an attempt that did not work) — so the whole list fits on a screen, and a row opens to what it needs, which firmware carries it, the links and a reel of it running. No headings between rows: which firmware carries a feature is a fact on its row, never a category over it, or the shelf would be back one level up. Reels are Instagram embeds by permalink, loaded only when a row is opened. The shelf and the catalogue share one header: Firmware and Features as a pair of tabs where the title was, the current one the title, the other a click away.
- **Try-out images on the features page.** The clock and the USB-MIDI build are not on the shelf, and until now trying either meant building it. Their rows carry a frozen image now — `clock-v0.1.5` as it shipped with 3.10.2, `midi-v0.1.0` built from the tree on 2026-09-17 — installed the way the shelf installs, through the panel's own `/update` page. Frozen means frozen: the image is the whole firmware as it was, core included, and nobody bumps it when the core moves; patterns, Wi-Fi networks and settings stay, and the way back is one click on the shelf. `check_versions.py` reads these folders from `features-data.ts`, so the rule that the shelf holds only what is named still holds.

### Docs

- **The repository explains itself to a contributor.** One table in `CONTRIBUTING.md` of what you have → where it goes → what CI runs on it; `docs/REPOSITORY.md` as the folder-by-folder map for people; `SUPPORT.md`, `CODE_OF_CONDUCT.md`, `SECURITY.md`, `CITATION.cff` and a root `LICENSE` pointer; a README in every contributor-facing subtree (`tools/`, `integrations/`, `firmware/modules/`, `firmware/toolchain/`, both `presets/`); `docs/mqtt-spec.md` beside the other contracts; `hardware/case/remixes/` as the named home for community enclosure variants, with a one-step CI check of its READMEs. Dead pointers removed: GitHub Discussions (never enabled), pattern pull requests (patterns are published from the Pattern Lab to the Community), the `.agents/` folder, `release.yml`. Stale facts fixed in place: the assembly map and `hardware/README.md` now name the v3.9 board, `firmware/README.md` no longer teaches the console pause that ended in 3.6.3, and the Ableton bridge says "install the Audio edition" instead of "rebuild with OSC".

## [3.10.2] - 2026-09-11

### Fixed — pattern storage

- **A Format that did not take no longer reports success.** `FFat.format()` never
  reads back what it wrote, and the flash driver never checks that a program
  landed. On a board whose flash silently drops writes, every step returned OK:
  the console said "storage ready", and the next mount failed with the same
  `Error: -1` as an unformatted board, which sent the owner round the Format
  button indefinitely (#424). The mount that follows a Format is the first read,
  so it now decides the result: if it fails, Format fails, and says why.
- **A failed mount says why.** The core's line is `Mounting FFat partition
  failed! Error: -1` whatever the cause, because FATFS's own reason is logged at
  a level this SDK compiles out. The first failure in a boot now reads the boot
  sector through the wear-levelling layer and records what it found: `not
  formatted`, `format did not stick: storage reads back blank`, or the first and
  last bytes of a sector that is not a filesystem. The reason goes to serial and
  to the new `fsError` field in `/api/status`. It runs at most once per boot and
  once after a Format, and never on a mounted volume.
- `/api/status` gains `flashId`, the flash chip's JEDEC id, so a fault that
  follows one flash part is visible without USB.
- A comment in `pattern_registry.h` still described the automatic
  format-on-failure removed in 3.2.0, and was being read as current behaviour.

## [3.10.1] - 2026-09-10

### Fixed — the pattern SDK

Two helpers that every pattern compiles into itself did not do what their
names said, and a third gained a variant it was missing. The two fixes change what a pattern draws, and because `abi/pf_module.h`
*includes* these files rather than calling into the host, the change reaches only
**newly built** `.pfm` modules: an installed module and a rebuild of its own source
will render differently on the same firmware. Rebuild a module to pick these up.

- **`PFColor::sampleRampLerp` is new; `sampleRamp` is unchanged.** `sampleRamp`
  holds the last stop at or below `t`, giving flat bands with hard edges. That
  reads like a gradient function that forgot to interpolate, and it is not one —
  Origin is built on it and its stepped colour is deliberate. Patterns that want
  a gradient now call `sampleRampLerp`, which interpolates between the bracketing
  stops and costs one soft-float division per sample; the C++ conversion prompt
  names both and says which is which.
- **`PFColor::hsvToRgb` rounds.** Each channel was `(uint8_t)(f * 255.0f)` —
  truncation, no `+ 0.5f` — so the function sat half a level dark on every channel,
  always in the same direction: a mean of **−0.470 LSB** swept over the HSV cube.
  `buildPowLUT`, four functions below in the same header, has always rounded.
- **`PFNoise::cellHash`'s seed decorrelates.** It was added to `gx` before the same
  hash, making `cellHash(x, y, s)` identical to `cellHash(x + s, y)` at **every one
  of 262,144 lattice points** — two layers seeded 0 and 1 were one field and a copy
  of it slid a cell sideways. The cost is visible in `preset_0713`, which draws seeds
  7 through 13 for each firefly's speed, phase and brightness and got one sequence
  offset by one index each time, so every "independent" parameter was the same
  stream in disguise. The seed now passes through the permutation table, because it
  cannot enter by addition anywhere in that expression: adding it to the final index
  is the same as adding it to `gy`, and adding it to both coordinates merely
  translates diagonally — measured against every shift within ±4 cells, that obvious
  repair still correlates **1.0000** with the unseeded field. What shipped correlates
  **0.0128**. Two extra reads of a 512-byte table that is already hot.
  The two-argument overload is untouched, so `valueNoise2D`, `perlin2D` and
  `fractal2D` render exactly as before.

### Improved — pattern authoring

- **`floorf`, `fminf` and `fmaxf` stop being calls inside the SDK's own helpers.**
  On this chip each one is a call into libm, not an instruction. `PFMath` gains
  `ifloor`, `floorF`, `clamp` and `clamp01`; `fract`, `hsvToRgb` and the noise
  lattice now use them, with results identical bit for bit. Measured on a rebuilt
  module on the panel: 1.2% faster. The C++ conversion prompt now tells new
  patterns to use them — and stops telling them that `sqrtf` is cheap or that
  `perlin2D` spans −1..1 (it runs to about ±1.51). Installed `.pfm` modules are
  unchanged; the helpers reach a module when it is next built.

### Fixed — the panel

- **Raising a code no longer lowers the light.** A bit plane's contribution is
  its OE window times the number of times the DMA descriptor chain repeats it,
  and the repeats already carry one factor of two per plane. The window had to
  supply the rest, and it was derived by shifting — which can only halve, and
  could not express the ratios the repeat counts need. Worse, the plane index
  was mapped through `(2 * depth - colouridx) % depth`, which sends plane 0 —
  the least significant — to the branch that hands it the same full-length
  window the most significant plane gets.

  Measured at depth 8: the planes delivered `125, 31, 126, 500, 1000, 2000,
  4000, 8000` where binary wants `62, 125, 250, 500, …`. Plane 0 twice what it
  should be, plane 1 a quarter, plane 2 a half. Swept over all 256 codes and
  three channels that is **26 places where raising the code lowers the light**,
  two of them by half, back to back — and 44 of 256 levels whose channel ratio
  departs from the configured white balance. Seen on a panel: level 14 reads red
  where level 13 is neutral grey.

  The window is computed now rather than approached: `u · 2^d / repeats(d)`.
  Inversions go to **zero** and the ratio departures to 11, at every brightness.
  Full-scale luminance moves about 1%, so the eye-converged brightness and
  white-balance constants keep their meaning. No per-pixel cost — this runs once
  when brightness changes.

  The arithmetic is now a pure function, `pfOEWindowPixels()`, lifted verbatim
  into a new host suite (`check_oe.py`). Nothing had ever tested it, because
  reaching `setBrightnessOE` needs a live DMA allocation — but the defect was
  never in writing the buffer.

- **The blit refuses a colour depth it cannot represent.** Its plane fields pack
  five planes into each of two words, so ten is the ceiling; above that the
  shifts lost bits and then became undefined, while the configuration allowed up
  to twelve. Nothing ships above eight, so this was latent — and the host suite
  swept 2–8, so nothing would have found it. It now sweeps 2–10.

- **Dark greys stop coming out coloured.** Only the top bits of the 16-bit CIE
  value reach a bit plane, and the rest was dropped rather than rounded. Truncation
  is biased downward by up to half a plane step everywhere, which is invisible in
  the bright half and is the entire signal in the dark end: eight input levels
  emitted nothing at all, and neighbouring neutral greys came out as *opposite*
  colour casts, because each channel crossed its threshold at a different code.
  Seen on the panel: a neutral level 9 read blue, 17 read cyan and 18 read red.
  Rounding to nearest is one line in a table built once per depth change — no
  per-pixel cost at all. Computed over all 256 levels and three channels: dead
  levels 8 → 4, level 9 becomes neutral, 17 and 18 both become the same neutral
  grey, and mid-tone ratios land closer to the intended white balance (level 64
  goes from 10/11/10 to 10/11/11). Full-scale white moves by one unit on blue
  only, so the hand-converged `LED_WB_*` constants keep their meaning and do not
  need re-converging.

  Because the blit is firmware rather than part of each module's compiled copy,
  this is the one fix in this release that reaches **already-installed `.pfm`
  modules** — every pattern gets it without being rebuilt.

  What this is *not*: the panel's response was already monotone. Claims that
  raising a code could lower the light were tested directly — alternating levels
  63/64, 107/108 and 127/128 against a control pair that pulses obviously — and
  nothing was visible at any of them. There are no inversions to fix.

### Fixed — audio in

- **A panel with no microphone no longer takes the knobs.** The Hann window used
  the symmetric denominator (`N - 1`) where a stream analysed hop after hop needs
  the periodic one (`N`). Only the periodic window has a DFT of exactly three
  bins, so only it keeps a constant input out of every other band — and the
  dead-rail check downstream is precisely a test for "constant input, nothing in
  the bands". Computed over the shipped band edges with a flat rail, the
  symmetric window gave 0.0666 / 1.8e-3 / 1.3e-4 / 1.3e-5, three of the four
  above the 1e-4 threshold; the periodic one gives ~1e-13 in all four. So the
  check returned false for every dead rail there has ever been, an audio-edition
  panel with the mic switched on but nothing wired claimed all four lanes and
  pinned them, and a hand on a knob sprang back. The measurement recorded in that
  function's own comment was taken before there was a window at all, which is how
  adding one broke it without touching it.
- **A backlogged microphone no longer colours the lanes for seconds.** The drain
  loop keeps only the newest hop, so after it ran the window was built from two
  pieces of audio that were not adjacent, spliced at index 256 — the exact centre,
  where the Hann term peaks at 2.0 and attenuates the discontinuity by nothing.
  Reading alternately into two hop buffers keeps the hop that actually precedes
  the newest one. The drain itself was right and is unchanged; only the seam was
  wrong.

### Fixed — MIDI

- **A stuck note can be cleared, and stops disabling the panel's own button.**
  Held-note state had exactly one clearing edge — a note-off for that note — on
  the one input path that can lose packets. Three ways out were missing: the
  channel-mode messages (All Sound Off, Reset All Controllers, All Notes Off) fell
  through the CC handler and did nothing, so the control a person reaches for when
  a note sticks was inert; turning MIDI off at runtime discarded the note-off
  while `fillInput` kept asserting the button, because it was the one handler with
  no runtime gate; and an RTP peer that vanished took the release with it. All
  three now clear. This matters more than it sounds: `observeFrame` reads
  `btnHeld && !noteHeld` to decide a press was physical, so a stuck MIDI note also
  silenced the encoder button under it.

### Fixed — the parameter bus

- **How far a legacy pattern travels no longer depends on how finely the sender
  chopped the move.** An absolute write reaches a delta-only pattern as clicks at
  ten bus units each, and the rule "never fewer than one for a change" turned a
  smooth ten-second ease into one click per update: 830 of them at 83 fps where
  the travel means 100, and half that at 41 fps. The remainder is carried now, so
  the total is the travel and the frame rate is out of it — which is what the show
  player already claimed of itself.
- **`dN` on an unheld channel works.** `applyRemoteDelta` accepted a click on any
  channel but only the held branch drained the queue, so a delta sent to a channel
  nobody was holding did nothing visible and then arrived in full the moment
  something held it, or was wiped by the next release. It is also bounded now:
  `d1=999999999` was accepted and handed to a pattern as that many clicks.
- **`POST /api/params?rN=1` releases a channel.** The bus could be written over
  HTTP but not let go of over HTTP — the only ways back were a hand on that
  encoder, or MQTT and the show player, which the default, audio and clock
  editions do not carry. And since holding a channel also clears the audio lane
  under it, one console slider could silence a mic lane with no way to undo it
  from the same console.

### Fixed — patterns and storage

- **Re-uploading a pattern updates its picture.** Both upload paths and the
  library pull invalidated the sidecar cache under a slug and not the thumbnail,
  so editing a pattern in the Lab and sending it back under the same name left the
  previous version's frame on the volume, and SELECT drew it under the new name.
  It survived reboots.
- **A stalled frame no longer makes the picture jump.** `dt` was an unbounded
  `millis()` delta, and installing a pattern, an NVS commit or a thumbnail write
  all produce frames far longer than a nominal one — measured at 273,949 µs
  against 12,000 µs on an ordinary upload session. Every pattern integrates
  against that number, so it moved everything a quarter of a second in one step.
  Bounded at 100 ms, at the single place it is produced.

### Fixed — firmware core

- **An upload that stalled could panic the board.** The wait loop in the request
  parser's `_uploadReadByte()` was the one of three that never yielded: upstream
  writes it brace-less, so inserting the maintenance poll above the `delay(2)`
  without adding braces made the poll the entire body and left the delay outside the
  loop. It runs on the network task — Core 0, priority 1 — where a loop that never
  blocks starves the idle task, and this SDK configuration watches that idle task
  with a panic at five seconds. Installing a pattern is precisely when the link is
  under load.
- **A failed settings write no longer deletes a good pattern.** Two paths cleared
  their own retry flag *before* the write it guarded. The damaging one is the boot
  latch: it cleared its flag and then wrote `pat_trying = false`, so a write that
  failed left the latch set on disk with nothing left to clear it — and the next
  boot reads a set latch as "the last boot died with this pattern resident" and
  forgets a pattern that was never at fault. Both now clear only once the write is
  confirmed, the pattern save reuses its existing 3 s debounce as a retry backoff,
  and the namespace open is checked. `/api/status` gains `nvs.usable` and
  `nvs.failures`, because the whole difficulty with this failure is that its symptom
  arrives a boot later. The brightness, power and Wi-Fi writes are unchanged.

### Added — checks

- **`check_math.py`** pins what `core_math.h`, `core_color.h` and `core_noise.h`
  compute. `abi/pf_module.h` includes those three into every `.pfm`, so they are the
  published pattern SDK — and nothing here had ever run a number through them. Their
  accuracy lived in doc-comments, two of which were wrong about their own function
  (`fastAtan2` is 7.4× tighter than it claims; `approxLength` is 6.8% where the
  comment says ~5%). 19 rows, each a **band** rather than a ceiling, so an accuracy
  change fails in either direction and has to be re-pinned deliberately. Note what
  `abi.sums` cannot do here: it hashes the three files in `abi/`, so it passes
  unmoved while the behaviour those files include changes underneath it.
- **`check_footprint.py`** reads each edition's elf and pins its static internal RAM.
  CI built four images and then printed their flash sizes — the one resource that is
  not scarce. Internal DRAM is, and the module code budget is its residual. Measured
  by the *address* of the linker's own `.dram0.heap_start` marker rather than a sum
  of section names, which would quietly measure less if a toolchain renamed them.
- **The shipped modules are priced, not just validated.** The ELF suite already
  opened all 33 `.pfm` in the Basics pack; it now sums their executable sections by
  the loader's own admission rule and fails over a ceiling. Nothing checked that the
  modules this repository ships can be admitted by the firmware it ships, which is a
  failure it has already had, and which took a hardware bisect to find.
- **A declared hook must be dispatched, and a dispatched hook must be called.** The
  boundary checker had five rules and all five policed what the core must *not* say.
  The worst regression this project has shipped went the other way: the per-frame
  feature dispatch went missing and every feature's loop silently stopped, on a build
  that compiled, linked, ran and served every route. Compiling four editions cannot
  catch that — a hook nobody calls type-checks perfectly.

## [3.10.0] - 2026-09-08

### Improved — Audio MIDI
- Network MIDI socket service runs independently of pattern rendering, with ordered, bounded event queues and PSRAM payload storage. Incoming controls still apply on the render task. Per-knob receive counters, queue overflow and RTP/parser diagnostics expose where traffic is lost.
- Absolute-bus compatibility clicks no longer appear as physical encoder MIDI output, preventing incoming automation from being reflected as outbound CCs.

### Improved — firmware core
- **Pattern storage mutations wait outside the render loop.** Conditional frame-boundary requests retry until a loader finishes; uploads/deletes then hold new activations until the catalog is rebuilt. Selections made during the hold retain their file identity across reordering. Restoration is asynchronous, and interrupted uploads remove their partial file before resuming. A reusable loader worker reserves its stack at boot, avoiding repeated stack allocation and a synchronous fallback under fragmentation; that stack is 8 KB, against a measured 2,980 B high-water across the heaviest catalog modules.
- **Module allocations are priced once, for the whole module, before anything is allocated.** The service reserve now *places* data and *prices* code: a module's executable sections are summed from its ELF section headers and admitted against `free - reserve` in a single decision, so the verdict cannot depend on the order sections are walked. Executable sections are placed first, because they are the only part with no PSRAM to fall back on; data can lose its placement to PSRAM but can never fail a load on its own. Nothing allocates in order to discover whether it was allowed to. Dynamic module allocations retain the existing 16-slot lifetime model, with a configurable 4 MiB byte limit and usage/refusal counters. `/api/status` publishes both sides of the comparison as `moduleMemory.budget` and `codeBytes`. Pattern code and the frozen ABI are unchanged.
- **Loading work has a defined cadence and the whole loop is observable.** A loading loop has an 8 ms minimum period; unchanged running-mode thumbnails refresh at most every 64 ms. Status gains whole-loop timing, short mutation timing, module allocation/worker-stack diagnostics and network-maintenance counters. Normal pattern rendering remains uncapped.
- **Slow HTTP traffic leaves opportunities for Wi-Fi/name maintenance.** Page bodies use nonblocking socket writes under the existing progress and total-time budgets; request-parser waits and conditional loop waits also service a bounded maintenance hook. This adds no network worker or stack, and does not re-enter HTTP handling.
- **The HUB75 blit now emits word accesses for its paired columns.** Its `memcpy` preserved aliasing rules but hid the DMA buffer's alignment from Xtensa GCC, which generated byte loads/stores and a stack temporary. Supplying the proven alignment retains the same colour/control bits and reduces measured `presentUs` from about **6.86 to 5.90 ms (14%)**, without another framebuffer. An odd-width buffer uses the scalar path. The host suite compares over 30 million DMA words, including FIFO order and depths 2–8. Bench conditions and frame-time results: [`docs/investigations/2026-09-firmware-runtime.md`](docs/investigations/2026-09-firmware-runtime.md).
- **Thumbnail disk I/O leaves the frame loop.** One immutable PSRAM snapshot is handed to the existing network task; completed reads become visible at a frame boundary. No additional task stack, and optional thumbnails never fall back to scarce internal RAM. Deletion/format generations reject stale results; a new capture wins over a pending read. `/api/status` gains `thumbs` counters and separate capture/I/O timing.
- **Wi-Fi gives a brief dropout time to recover on the working SSID** before cycling saved alternatives. DHCP address changes also trigger the connection hook. Name-service startup and partial registration failures retry on the network task, preserving services registered by features; duplicate announcements for one connect edge are coalesced. The MIDI feature retries its own service registration. Status gains `network` diagnostics and `POST /api/wifi/reconnect` requests a delayed reconnect without rebooting or rewriting credentials.

### Fixed — module loader
- **A module could be refused while the RAM it needed was free.** The service reserve was applied as a veto rather than a placement rule, and for executable allocations the check ignored the requested size entirely, so a 2 KB `.text` was refused exactly as hard as a 200 KB one whenever byte-addressable internal free dipped under the reserve. Combined with a persistent 12 KB loader stack, the module's share of internal RAM fell to about 3.7 KB against roughly 700 B of boot-to-boot variance — heavy patterns started intermittently, and which ones changed with every boot. Pricing the whole module up front and returning 4 KB of loader stack raises that share to about 7.8 KB, enough for the heaviest module in the shipped Basics pack (5,364 B of executable image) to clear it by 2.4 KB. An admission failure now counts as a refusal so the loader's existing retry absorbs a transient dip caused by an in-flight HTTP response.
- **`api->alloc()` is zeroed again.** The frozen ABI documents it as a PSRAM-preferred *zeroed* allocation, and the runtime rework dropped the fill, so a pattern that allocated a trail map or accumulator and read it before writing was reading whatever the previous module left behind.
- Reject overflowing allocation/relocation ranges and unterminated ELF string-table entries; share header validation between upload and load. Copy unresolved-symbol diagnostics before freeing the image they point into. The frozen module ABI is unchanged; native regression tests also accept all 33 shipped Basics modules.

## [3.9.5] - 2026-09-06

### Added
- **Clock edition** (`firmware/bundles/clock/`, v0.1.0) — a panel that tells the time, and carries nothing else. Cut for a request from outside, and shelved on `/editions` under Community rather than Official: good fun, and not what Patternflow is about — Official is the maintainer's own list of what is.
- **`features/clock/`** — the hours and minutes cut out of whatever pattern is running: huge anti-aliased digits, hours over minutes on an upright panel, four across on a wide one. Inside the digits the pattern or a solid colour; outside them the pattern dimmed to taste or a solid colour; between the rows an optional bar (across, the face's own colon), cut from the pattern exactly as the digits are; the gap adjustable; the minute change crossfaded. So one layout is a cut-out, a stencil, solid digits over the pattern, or a plain clock on a coloured ground. Seven faces to choose from — Bebas Neue, Anton, Oswald, Saira Extra Condensed, Barlow Condensed, Six Caps, Squada One, all OFL — rasterised offline into 4-bit alpha cells by `toolchain/build_clock_glyphs.py`, which is also where a face of your own goes (a TTF and one line). Everything is blended into the frame on its way to the panel rather than stamped over it afterwards. `/clock` sets it up with a live preview that draws the same glyphs the panel does and sends every change as it is made — one-tap presets for the four fills, the faces as chips drawing their own digits, and the browser's own colour picker beside the swatches; `GET`/`POST /api/clock` and `GET /clock/glyphs.bin` are the contract (`docs/rest-api.md` 1.3). The time zone is a POSIX TZ string with its DST rule — the weather page's UTC offset cannot say when summer time starts — and the clock owns it: whatever else sets `TZ` is put back within a second. On first boot the offset a panel had already given the weather page is read, never written, as the starting zone. Nothing is drawn until NTP has answered once. Orientation counts quarter turns from the wide way; 1, upright, is the default.
- Core: `PatternflowClock::beginSyncTz()` and `assertTz()` in `src/core_clock.h`, the POSIX-zone entry points beside the minutes-offset one; and **`composeFrame`**, a new hook at the tail of `PFFeature` — the finished canvas on its way to the panel, before the blit, so a feature can blend with real alpha or mask the whole frame. `PFCanvas::present()` asks one function pointer, the sketch wires it to the dispatcher, and the canvas itself is never written (patterns that accumulate across frames own it).
- The tooling knows the fourth composition: `build.sh all` builds and scans `clock` (the feature's marker is `[CLOCK] /clock ready`), `release.py cut --clock vX`, `check_versions.py`, the console page list and the fake device (`/api/clock`, `/clock/glyphs.bin`).

### Added — panel
- **Browsing with K4 no longer loads every pattern it passes.** A module's cost on the way in is its own `setup()` — 10 ms for a light one, 2.3 s for *Branched flow*, 2.9 s for *Two-stream* — and SELECT mode paid it on every detent: the loop stood still for that long while the encoder kept counting, and the accumulated detents landed all at once when it came back, a panel that froze for two seconds and then jumped five patterns. The knob now moves only the highlight, three detents per pattern (one per detent overshot); the pattern loads once the knob has rested for a third of a second, and until then the panel shows the pattern's **thumbnail** — the 128×64 frame it last drew, taken off the canvas when a pattern is left after running for two seconds, kept in PSRAM and written beside the module as `/patterns/<slug>.thumb` (16 KB each; `src/core_thumbs.h`). Captured before gamma and white balance and painted back through the same `present()`, so the picture is what the pattern looked like. A pattern nobody has played yet shows only its name until it has; the first slow pass through the list builds the set. Deleting a module deletes its picture, formatting the volume forgets them all, and `GET /api/patterns/file?ext=thumb` hands one to a console or a site. The load itself runs on a task on Core 0 (`activatePatternAsync`): the frame never stops and the knob keeps answering while a heavy `setup()` runs, the panel shows the thumbnail until the pattern is ready, and where the knob rests last is what loads next. The same path serves switches from the console, OSC, MIDI and a show; `/api/status` says `loading` while one is on its way, and uploads and deletes wait for a load in flight before evicting.

### Fixed — panel
- **The UPDATE card no longer tears against the pattern while an image is received.** Since the upload handler moved to the network core (3.9.1) its progress callback kept drawing the card and flipping the panel from there, while `loop()` went on drawing the pattern — two tasks flipping one DMA buffer for the length of the upload. The callback now only reports the percentage; `loop()` shows the card, as it does every other one.
- **The name that appears when a pattern is chosen from the console reads upright.** It was drawn along the panel's long axis — sideways on a panel stood on its end — and is now portrait like the SELECT screen, wrapped the same way for long names.

### Fixed — core
- **The console survives a slow Wi-Fi link.** A panel whose link was moving 2–5 KB/s (round trips of ~0.4 s with retransmissions; a healthy panel on the same network does 3–60 ms) got every console page cut short: the page sender's hard 5-second budget — written for the days when a send ran inside `loop()` and stalled the render — broke off with the header already promising the full `Content-Length`, so `/` arrived as 10–25 KB of 26 KB and the 63 KB audio page never at all, and the browser showed a page whose script ends mid-word. Since 3.9.1 the sender runs on the network core and the render never sees it, so the budget was only ever hurting. It now gives up only when the peer stops accepting bytes for ~20 s (or after a two-minute ceiling), and when it does it closes the connection instead of leaving a short body looking complete; on the single-core fallback the 5 s cap stays. Measured with a client holding a 1 KB window: 17.5 KB delivered whole in 22 s where it used to be cut at 5; a client that reads nothing is dropped at 20 s and the next one is served in 30 ms.
- **Console pages are sent gzip-compressed** — `console_pages.py build` lays a gzip twin under every page literal (and under `pf-console.js` and the unzip library), the handlers send that with `Content-Encoding: gzip`, and `check` proves each twin still decompresses to its page in CI. A third of the bytes cross the air (26.5 → 8.6 KB for `/`, 63 → 17.6 KB for `/audio-in`), which on a bad link is a third of the time; the raw literals stay in the headers for the tooling and drop out of the image, which shrinks by ~140 KB.
- **The network core no longer reboots on a request that stalls.** The vendored `WebServer` read request lines, headers and raw upload bodies through Arduino's `Stream::timedRead()`, a spin loop that never yields. Harmless while the server ran on Core 1; since 3.9.1 it runs on Core 0, whose idle task feeds a 5-second watchdog that panics — so a request that paused for five seconds mid-header, or a `.pfm` upload trickling in over a slow link, took the whole board down. Reproduced on a bench panel (`Task watchdog got triggered: IDLE0`, reset, back in ten seconds) and gone after: the parser now waits with `delay(1)` between bytes, bounded by the same timeouts as before (`src/webserver/VENDORED.md`, fix 2).
- **A big pattern can no longer take the console down with it.** The module loader placed a module's data sections in internal RAM whenever they fit, and internal RAM is what Wi-Fi, lwIP and every HTTP connection are made of. A community pattern whose tables came to 46 KB left 2.7 KB free after boot: the panel drew on, every connection died at the SYN, and nothing anywhere said why. Data sections over 16 KB, or any that would leave less than 24 KB of internal heap, now go to PSRAM first (`PF_MODULE_DATA_INTERNAL_MAX`, `PF_MODULE_INTERNAL_RESERVE`); the same pattern now leaves 42 KB free with 3.9 KB of it internal, and the console answers in 50 ms while it plays.

### Changed — features
- **MIDI and OSC report hands, not lanes, and MIDI knob output is paced.** On the Audio edition the microphone moves the knobs through lanes, and by the time the frame reached the MIDI and OSC features that motion looked like an encoder — so a quiet room's noise floor went out as 26–43 control changes a second (two datagrams per knob per frame over OSC, once a host is known), filled the Wi-Fi driver's eight transmit buffers, and starved the console's own traffic behind a wall of `could not send data: 12` on the serial log. Both features now skip a knob a lane is moving (`PF_MIDI_OUT_LANE_MOTION` / `PF_OSC_OUT_LANE_MOTION` restore the old behaviour), and MIDI sends at most one CC per knob per 50 ms, trailing-edge, so the last value always lands (`docs/midi-spec.md` 1.1, `docs/osc-spec.md` 1.1).

### Added — API
- **A brightness slider on the console home page**, under the panel switch — the value K1's long-press session sets, written over `GET /api/display?brightness=5..255` (applied through the power clamp on the next frame, saved to NVS once it has been still for 3 s) and reported in `/api/status` as `brightness`, so the slider follows the knob and the knob follows the slider.
- `GET /api/status` gains `resetReason` (`"poweron"`, `"sw"`, `"panic"`, `"task_wdt"`, `"brownout"`…) next to `uptime` — two reboots went unnoticed in one afternoon because from the network they look exactly like a power cut — and `load.internal` / `load.psram`, where the resident module's sections landed. The same reset reason is printed once at boot. `docs/rest-api.md` 1.4.

## [3.9.4] - 2026-09-04

### Changed — web
- **One pattern runtime.** The community's sandbox page (`public/pattern-sandbox.html`, the XSS boundary every preview and thumbnail renders inside) was a hand-kept plain-JS copy of the lab's runtime, with "keep the two in sync" notes on both sides. It is now built from the lab's own code: `scripts/build-sandbox.ts` bundles `src/sandbox/sandbox.ts` — only the canvas, the live loop and the postMessage protocol — with `lib/pattern/harness.ts`, `ramp.ts` and `matrix.ts`, and `check:sandbox-sync` (in `check:ci`) fails when the committed page is not that build. Two drifts came out in the wash: the sandbox turned a knob 20 detents a revolution where the lab and the encoder turn 24, and a pattern that threw reported its message without the line the lab quotes. The default ramp for a `setValue` pattern with no `@ramp` line is kept; every other output was compared pixel for pixel against the old page before it was replaced.

### Docs
- `docs/SERVICES.md` records the community host as it is: the build worker's systemd sandbox (the drop-in, the three writable paths, what it does not cover — files the worker's own user can read still reach a compile error, and the two steps that close that), and the host update procedure.

### Added
- **A release is two commands.** `python firmware/toolchain/release.py cut vX.Y.Z [--audio vA] [--performance vB]` bumps every version site, dates the changelog, runs `shelf.sh` for each image, points the flasher manifest and the `/editions` cards at them, runs the web checks, commits and tags; `release.py publish vX.Y.Z --notes FILE` pushes, opens and merges the dev → main pull request, and creates the GitHub release with the edition images attached. `check_versions.py` (in CI) reads the six files a version lives in and the shelf, and fails on any disagreement. `docs/RELEASING.md` keeps the checklist as the description of what the two commands do.

## [3.9.3] - 2026-09-03

### Changed — core
- **Rebuilding the pattern list no longer stops the render for two seconds.** After an install batch, and on deleting the module that is drawing, the registry rescanned `/patterns` and opened every module's sidecar twice; with forty modules that was 2.4 s with the frame held (3.9.1's `loopSyncMaxUs` put the number on it). The sidecar's two facts are now cached by path and forgotten only by the writer that changed them (upload, delete, format, library pull), and the scan reads the directory with `readdir` instead of opening every entry to build a `File`. Deleting the drawing module answers in 0.29 s where it took 2.4; the render pauses 55 ms where it paused 2,160. Boot still reads every sidecar, once.
- **`PFMath::jsMod` — JavaScript's `%` without `fmodf`.** A pattern ported from the lab reached for `fmodf` on every pixel for a hue wrap like `(h + 0.33) % 1`, and in a module that is a call into the host's libm. `jsMod(x, m)` is one division and one truncation with JS's sign rule; the 22 preset twins that used `fmodf` (52 calls) now use it, and the lab's C++ prompt says to. `0510` rebuilt: 20.8 → 17.9 ms a frame.
- **The frame push writes two columns at a time.** Adjacent columns share one aligned 32-bit word in every plane, so the blit does one read-modify-write per plane for two pixel pairs instead of two; the CIE table it sums on-time from lives in DRAM, and the function in IRAM. Bit-exact, like 3.9.2's tables. 7.0 → 6.9 ms; the DMA engine's own reads of that memory are what remains.

### Added
- **Firmware compiled in CI.** `.github/workflows/firmware-build.yml` runs `firmware/bundles/build.sh all` — default, audio, performance and the marker scan that proves each image carries exactly its features — on every pull request that touches `firmware/`, with the PlatformIO packages cached. Until now the checks in CI were greps; the compiler ran at a desk.
- **Edition write-ups are releases too.** The firmware-release workflow no longer fails on a tag that is not a core `vX.Y.Z`; an edition's own release (`audio-v0.5.3`) attaches its image by hand from the shelf. The first one is the Audio edition's.

## [3.9.2] - 2026-09-03
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

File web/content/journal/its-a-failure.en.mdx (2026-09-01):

---
title: "It's a Failure"
date: "2026-09-01T16:40:00+09:00"
excerpt: "In a different direction"
cover: "/journal/its-a-failure/pdm-mic.jpg"
coverCaption: "A PDM mic wired onto the ESP32"
hideCover: true
draft: false
---

Through last weekend I posted about Patternflow to several subreddits and sent cold emails to about fifteen magazines. I was trying somehow to drive traffic to the Crowd Supply funding page and create conversions. Naturally the response in the communities was good, and more than the cold emails, the Reddit posts that got a lot of upvotes spawned plenty of purely organic articles. Or did Crowd Supply take some action on their end? I can't tell whether they're doing anything.

Anyway, I got picked up by several electronic music and synthesizer magazines like Mixmag, Synthtopia, MATRIXSYNTH, and MMR Magazine, and traffic came in. Conversions didn't happen. Is the price the problem? GitHub stars and Discord arrivals come, but they don't buy.

The PETG 3D enclosures I'd ordered in advance, anticipating a successful funding, arrived yesterday. PCBway sponsored again, and the quality is very good. It feels much better than last time. I'd worried the material would feel more plastic-y than PLA, that it would be glossy, but it doesn't look like a problem at all. It feels cleaner, which is great. And the shipping was, again, carefully packed to avoid breakage and arrived safely.

<figure className="journal-md-figure">
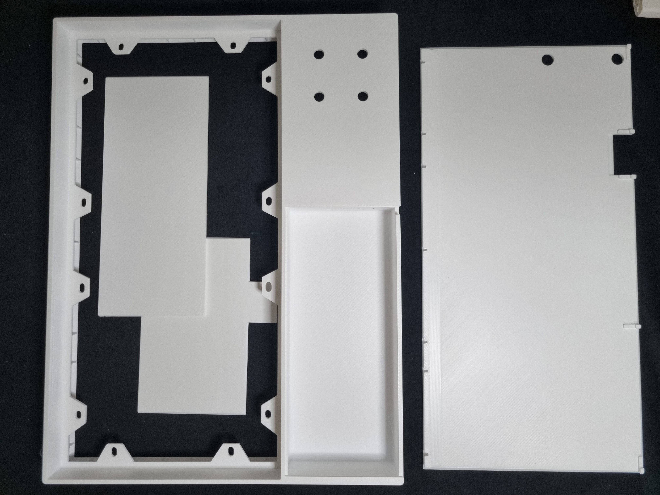
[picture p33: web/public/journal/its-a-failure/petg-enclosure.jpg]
The PETG enclosure parts printed by PCBway
  
  <figcaption>The PETG enclosure that arrived. None of the gloss I'd worried about; if anything it looks cleaner.</figcaption>
</figure>

But this too only becomes useful if the funding ends successfully… I hope it doesn't turn out to have been for nothing. To make sure it isn't, I'll have to put in a lot of effort and cost, and I've been thinking about that a lot. Do I use the new grant to force the funding into success somehow and use that as an asset for the next steps? Or, based on the data that conversion isn't happening even after generating sufficient traffic from precisely the right target, do I quickly admit failure and pivot to a different direction?

Actually, "pivot" isn't the accurate word. It's more like deciding whether to skip a bonus stage. The plan was to use the funding to bring in people who don't have time to build a Patternflow themselves, and specifically to activate the pattern community. What's already been proven wrong is that owning a Patternflow device has no connection to creating and sharing patterns. For everyone besides me, even though Pattern Lab's AI system made making patterns easy, the reason to make them is lacking. There's no reason to make a new pattern. The person who's made the most, most consistently, doesn't even own a device. Anyway, what I mean is that this is a separate problem.

On the other hand, the number of people building Patternflow themselves keeps growing. From March, when I started publicizing the project, until now, about 50 people have built their own Patternflow. Amusingly, the evidence for this came from an unintended mechanism. It comes from the AliExpress affiliate link and from a structure born out of a chronic limitation in building Patternflow right now. Whatever else you use for the other parts, I'd noted that for the LED panel specifically you should buy exactly that company's model to make building easy, so the majority of builders end up recorded as a number.

There were 64 orders in total, and assuming one person builds several units, around 50 people seems about right. One disappointing part is that the people who voluntarily share their Patternflow on Discord number only about ten. So soon I'm going to put out a request to tally up the people who've built one. Of course there's a good chance they won't bother. In which case, nothing to be done.

So the foundation for growing Patternflow as a community and an open-source ecosystem can be considered mostly in place. Which means there's enough to attempt the next steps even without the funding.

I have to build a structure where countless variations and experiments happen voluntarily within the community and get shared. To that end I recently tore up the firmware on a large scale. You can see the details in [this issue](https://github.com/engmung/Patternflow/issues/349). It made me quite uncomfortable to do. The truth is I forced the people who had already built and contributed to follow my changes, and there was a clash of opinions in the process. Whether it was really a clash or just a miscommunication, and whether the relationship has recovered, I can't tell. On the surface things are better, but when it comes to people I tend to carry a lot of worry and anxiety, so I can't easily put my mind at ease.

Now there's a foundation for people to add the features they want to the firmware and share them. And the area I'll focus my own development on is audio. Ninety percent of the people who've built and used a Patternflow were most interested in syncing with audio. I've gone back to improving the features I'd dropped while preparing the funding, and I tested attaching a PDM microphone to the ESP32. It works well, and I think there's a lot of potential this way. Except the reel I posted yesterday with high hopes came out with the worst results yet, so I do doubt a little whether this is really right.

<figure className="journal-md-figure">
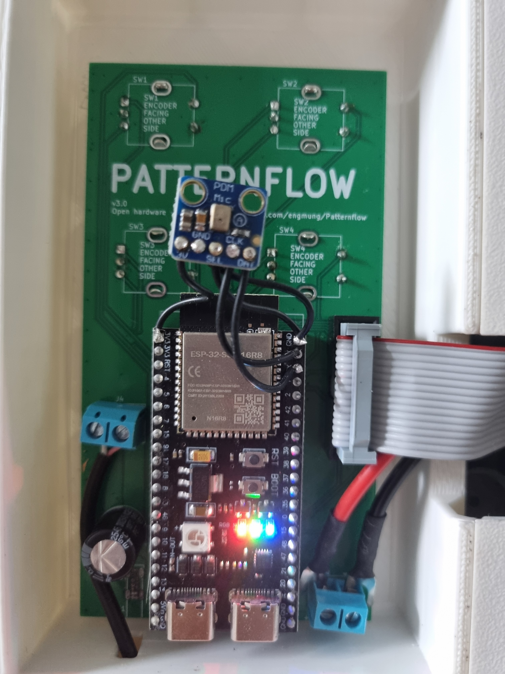
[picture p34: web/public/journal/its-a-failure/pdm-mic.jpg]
A PDM mic module wired to the ESP32 on the Patternflow board
  
  <figcaption>A PDM mic wired onto the ESP32. It works.</figcaption>
</figure>

How to document it and let people try it themselves, I don't know. There are plenty of features I want to build right now, plenty of places that need fixing, and I still don't want to give up on the funding either. And in the middle of all this, organizing what I've made and writing it up is the thing I find most tedious… but it also seems like what's most needed right now. I don't know. The project feels disorganized at the moment. I need to open up the paths…

Coming back around, then, I have to think about how to make money. Today is the first day of the semester, and I took a one-year startup leave of absence. Which means I have to make money with Patternflow. If I were just going to end it as an art project, there'd be no reason to take leave. If I sell few at a high price, the buyer could be a company or an individual. Going after companies means building up actual cases little by little; going after individuals means becoming known. I have to make good use of what I've achieved so far.

Anyway, that's how it is. My thoughts have piled up again and it's irritating. I wish some brilliant idea would just pop out, but I don't see room for that. I already know all the directions; what I lack is the conviction to boldly choose one and push. If I were doing this alone I'd just act first and think later, but with several people involved now, it seems I can't. The thing that catches most is the funding, of course. I signed a contract, and much of what I've achieved so far was built on that funding, so is giving it up right? People spent time and did work assuming the funding would succeed, so is it right to render that meaningless?

I should separate the rational perspective from the emotional one, and think about whether my discomfort right now stems from relationships with people, and whether I'm overthinking it on my own again. For now, having decided on the leave of absence, it's right to treat this not as a simple project but as a matter of survival.

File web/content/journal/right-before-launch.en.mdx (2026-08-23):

---
title: "Right Before Launch"
date: "2026-08-23T18:20:00+09:00"
excerpt: "Where things stand"
cover: "/journal/right-before-launch/business-cards.png"
coverCaption: "The business cards I ordered"
hideCover: true
draft: false
---

Launching next week. 8 o'clock on Wednesday the 26th, Korean time; the day before, US time.

I switched the 3D printing material from PLA to PETG. The Patternflow device doesn't generate much heat so I figured it'd be fine, but apparently it melts during shipping. Printing costs went up 1.6x and the sale price went up to $269. I don't know how PETG will feel. From experience, very plastic-y? That smooth… I think the slightly mass-produced feel will get stronger. PCBway kindly sponsored again so I'll receive it next week, but whether I'll like the material is uncertain. Even if I don't, nothing to be done. It's far better than having it melt.

For CE and FCC certification, I've arranged to go to a test lab next week. I've also requested the relevant documents from the panel vendor. It's hard to be optimistic in this area at all, but I hope some way through opens up. It's strange that I didn't ask the vendor sooner. I'd handled everything for the ESP32, so why? The LED panel only occurred to me now. Well, at least I've asked, so that's that.

I was selected for an arts pre-founder program. They provide 5 million won worth of indirect support along with help on market validation. Whether it can run alongside the program I was already selected for, though, I have to ask next week. I hope it works. If not, I'll have to think about which to choose. With these support programs, I've gotten some confidence in IR pitching and interviews. I go in with almost no prep, freestyle it, and pass every time. Maybe having numbers is enough that they just take you.

Since I recently registered the business, I designed and ordered business cards yesterday. For that I built a feature in Pattern Lab to export as image and video. It seems pretty decent. There are a lot of uncommon patterns, and you can adjust the colors too, so I thought people on the design side could put it to good use if they worked at it. Anyway, I only put one simple pattern on it and it looks quite distinctive, which I like.

<figure className="journal-md-figure">
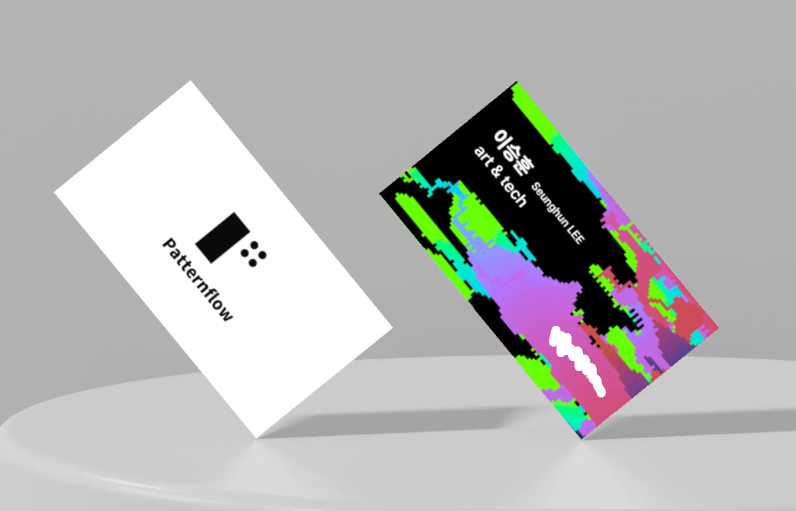
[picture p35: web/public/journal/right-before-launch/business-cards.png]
Preview of the ordered business cards, carrying a pattern exported from Pattern Lab
  
  <figcaption>The business cards I ordered. One pattern straight out of Pattern Lab.</figcaption>
</figure>

I haven't been sleeping well lately, so I'm tired. Insomnia is genuinely the worst. Yesterday too I lay down at eleven and couldn't fall asleep until three, so I got up, killed time, and slept at five. Hm.

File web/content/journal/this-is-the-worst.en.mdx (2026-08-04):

---
title: "This Is the Worst"
date: "2026-08-04T19:20:00+09:00"
excerpt: "Nothing but uncertainty"
cover: "/journal/this-is-the-worst/studio-product-shoot.jpg"
coverCaption: "Patternflow set up in the photo studio"
hideCover: true
draft: false
---

My mental state lately is truly the worst. When stress piles up I tend to dream about fighting a lot, and yesterday I spent the whole day in hand-to-hand combat. That's how irritated, anxious, and tense I am. From the moment I passed the 150 subscribers needed to move to Crowd Supply's launch stage, it's felt like some timer started running in my head. I have to handle everything as fast as possible. Crowd Supply seems to be easing back into work now that the Teardown conference is over. In the meantime I'd prepared the materials and drafts for the launch, and yesterday I got the detailed guidance.

Starting with the various certifications for selling electronics globally, then re-quoting with tariffs and fees included, then reviewing every option for production and for shipping to the Crowd Supply warehouse. My head is killing me. What's more frustrating is that I can't control any of it. I ask the other party about everything, and until a reply comes I have to wait with the uncertainty just sitting there. It's driving me mad.

I honestly don't understand how anyone manages and bears all of this alone. I've got AI's help and I'm working through it step by step, but the people before that? How they did it is genuinely worthy of respect. If I could go back a few months, I'd want to talk myself out of crowdfunding altogether. I wonder how it would have been to focus on the open source instead, on building it as a community. Not that I'm neglecting that part. I'm doing both at once. Whether I'm doing it well, I don't know.

The community does feel like it's growing bit by bit, but just as much, countless things needing improvement keep appearing. And parts of the communication have started to feel quite inefficient. How to improve that, I don't know yet. I've added a small test feature to the community page on the site. But whether to tell people about the feature I made or not, well, I'm not telling them. Probably because I'm afraid. Out of anxiety about whether it'll work properly, I'd rather not announce it, so I can take comfort in it obviously not working out.

Even if the funding launches successfully and there are plenty of buyers, I won't make money from it. Running the numbers makes that much clearer. Including the factors I haven't accounted for yet, even the currently planned $199 could be cutting it close. I could just set the price high, but the things I've told people before make me resistant to that. And I'm not sure whether it's right to sell something for several times the price when you could build it yourself for $100. Factoring in the setup, effort, and time it takes to make, is it a fair return?

I was also selected for the Seoul Foundation for Arts and Culture's arts startup incubating program. I'd wanted to take the 3 million won grant and use it for prototype production and testing costs, but I got an answer that it isn't possible. Apparently the support only covers transactions with domestic businesses. It seems to be because overseas parties can't issue tax invoices. So where on earth should this 3 million go? Should I just burn all of it on CE and FCC certification? But I don't have a feel for the quotes yet, so even that's murky. I looked into other arts startup support programs, and their usage restrictions are even more specific. In most cases I can't use it the way I want. Money's tight enough that I'm getting by on school cafeteria food for every meal, so spending my own on anything is hard. I also have to think about whether to stay enrolled for the second semester. Part of me wants to just take a leave of absence, but if it's possible, doing both is better. I think I'll decide this based on how hard the crowdfunding launch prep gets. At the level I'm feeling now, absolutely impossible.

What is there to do apart from the Crowd Supply funding prep? First, I have to update the materials in the README. All the screenshots and photos need swapping to the latest version. The photos of the Patternflow device especially, since they were shot on a phone in the very early days, absolutely have to be redone. So I'm on my way back from borrowing a camera and testing it. It looks hard to capture the feel of the LEDs, though. ISO, shutter speed, all of it… it's my first time using a proper camera at all, and it was difficult. Still, I'd rather do it myself than ask someone else to.

<figure className="journal-md-figure">
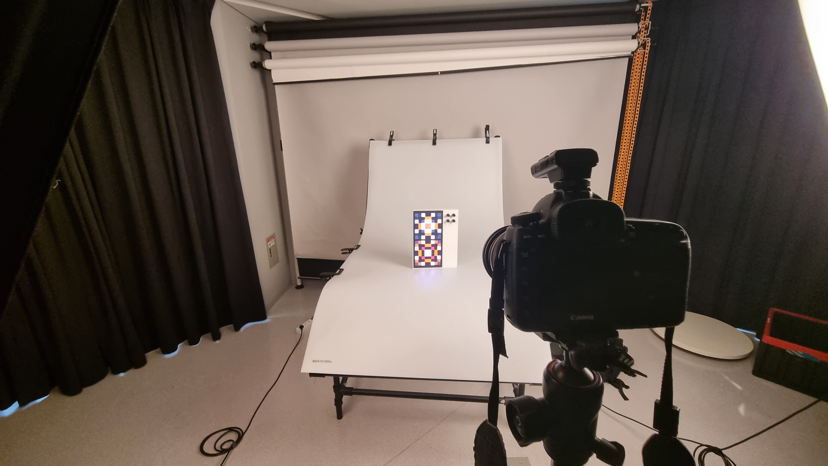
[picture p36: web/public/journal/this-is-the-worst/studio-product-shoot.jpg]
Patternflow set up in the photo studio with a camera on a tripod
  
  <figcaption>Patternflow set up in the photo studio. It's my first time with a proper camera, and it's still hard.</figcaption>
</figure>

Activating the community really matters too. Honestly, the biggest resource I have is the community. If I just set up an environment where they can help, they're people who would help as much as you like. But even that small ask is hard for me, and I have no idea how to lay the board out. If anything, when they bring something to me, I seem to feel burdened. If they fail, I even feel guilty. I know there's not a single reason to, and still I can't help it. It feels like the people who've kept showing interest and sharing the project, the ones I've thanked, will turn on me over a single failure and hold it against me. I hope I can work through that, through the Patternflow project.

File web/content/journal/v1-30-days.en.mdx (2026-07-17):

---
title: "Patternflow in 30 days"
date: "2026-04-29T20:41:00+09:00"
excerpt: "From tangled wires to open source."
cover: "/journal/v1-30-days/patternflow-v1-complete.jpg"
highlight: true
draft: false
---

## A pause to find the direction

An LED panel, an ESP32, a tangle of wires that had once seemed hopeless — somehow they'd been shaped into something that looked like a thing. There was no plan. It all started from a small mistake and a small experiment, and now, thirty days later, it has become the project I'll bet this year on.

Honestly, I might give up soon and chase something else. No — this time feels different. I've been getting positive signals from outside. An early prototype reel showing the core idea of Patternflow crossed 10,000 views in two days. The [Reddit post](https://www.reddit.com/r/arduino/comments/1so9er5/built_a_4knob_generative_pattern_controller_with/) I made afterwards filled up with generous comments and people asking where they could buy one. I saw a possibility. I decided to pour everything into it. To turn it into an open-source project, I worked without taking a single day off.

About thirty days in, I finally have something I can show. There's still a long way to go on the details. I'm a little worn out from running without rest. So I wanted to look back at the journey so far, and reset the direction ahead. As I looked back, I realized — this wasn't a thirty-day project. It had been gestating long before that. This is a piece that runs through all of it.

<div className="journal-figure-row">
  <figure className="journal-md-figure">
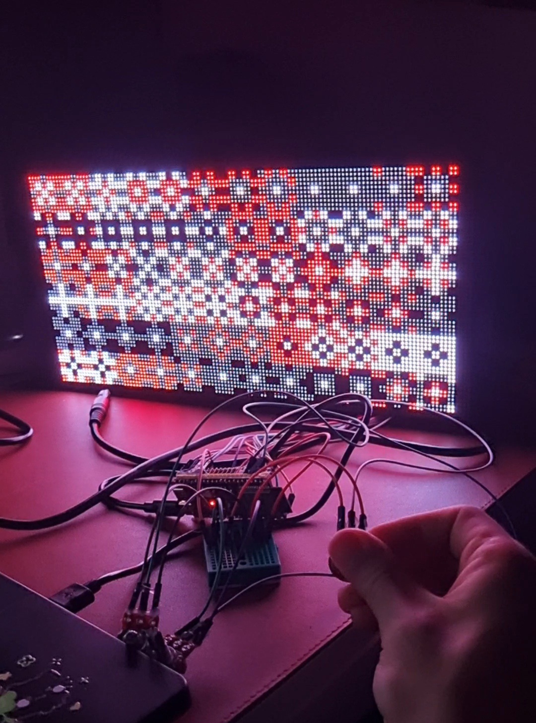
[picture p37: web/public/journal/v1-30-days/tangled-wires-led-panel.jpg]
Tangled wires and LED panel
    
    <figcaption>Tangled wires and LED panel</figcaption>
  </figure>
  <figure className="journal-md-figure">
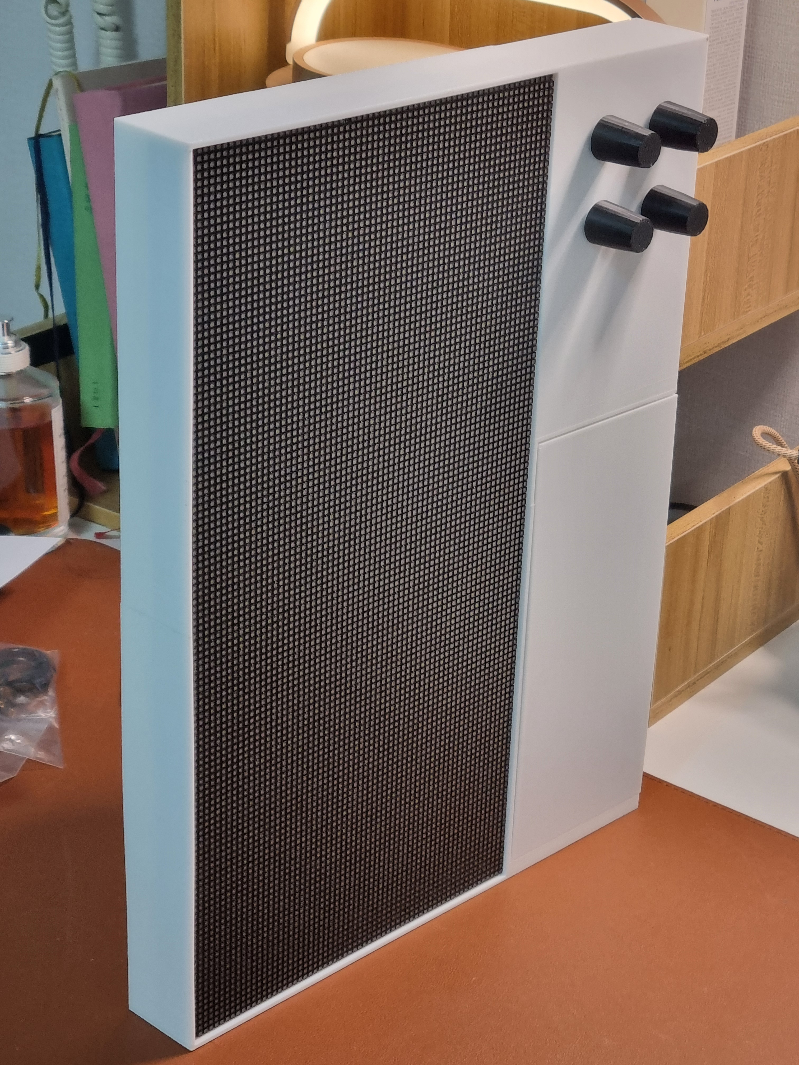
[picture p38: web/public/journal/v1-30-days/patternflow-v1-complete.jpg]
Patternflow v1.0.0 in its finished form
    
    <figcaption>Patternflow v1.0.0 in its finished form</figcaption>
  </figure>
</div>

---

## I want to be a new media artist

It became 26. This year, I really wanted to make my own work and become a new media artist. I wanted to stop the meaningless tech-flexing, stop developing other people's exhibition ideas. I went back to playing with Geometry Nodes and Shader Nodes in Blender 3D after a long while. I accidentally pushed a parameter to an extreme. The visual pattern that emerged held me. That's how [Patternflow: Origin](https://origin.patternflow.work/) was born.

<figure className="journal-md-figure">
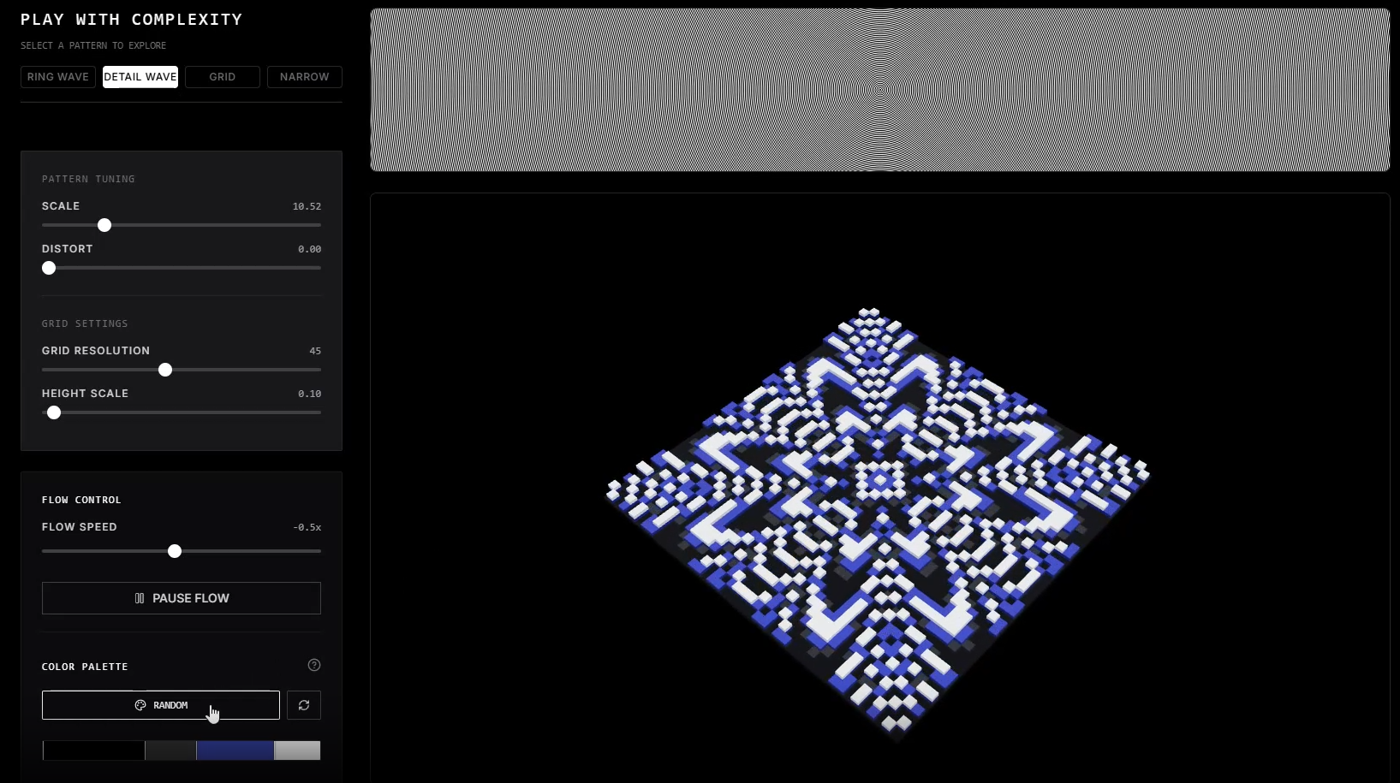
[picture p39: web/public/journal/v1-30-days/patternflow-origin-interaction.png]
Patternflow Origin interaction page
  
  <figcaption>Patternflow Origin interaction page</figcaption>
</figure>

I wanted to become an artist with this. As I always do, I built an interactive website. I dug into why the pattern had captured me and tried to find an artistic meaning in it. It was hard. I asked some professors to look it over. They said it felt more like design than fine art. So I extended it into 3D printing — I'd had this in mind from the start. I made [objects](https://www.instagram.com/p/DUe37KEE3IC/?next=%2Fpatternflow.work%2F) in forms that didn't exist in the world before. They were pretty cool, and pretty fun. I gathered all of this and applied to an exhibition support program run by ArtKorea Lab. The theme was creative coding, which felt like a good match. I had high expectations.

I went through the absurdly tedious and infuriating paperwork and made it all the way to the final review. I wasn't selected. Reading the result, I couldn't shake the feeling that they had picked from artists who were already established. I felt wronged. I cried a lot. I was angry. I felt empty. But I hadn't been working only for that one program, so I pulled myself together quickly. I went back to posting content steadily. At the time it was a daily ritual — you can still see it on my [Threads account](https://www.threads.com/@patternflow.work). These days it's been quieter, since I've been pouring time into the renewed Patternflow.

In late March, my younger brother Doyun, who studies electronics, mentioned in passing: "It would be cool if you put Patternflow on an LED matrix." I'd been planning a real interactive exhibition, so I'd already felt the need for some kind of physical interface. But I'd been hoping for projection, or a high-resolution monitor. An LED matrix would be too low-resolution to render the 3D look, so I wasn't drawn to it. Still, when I checked AliExpress, the price was affordable enough that I bought one to test. That's where the turning point began.

---
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

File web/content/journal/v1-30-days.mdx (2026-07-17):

---
title: "패턴플로우 30일"
date: "2026-04-29T20:41:00+09:00"
excerpt: "엉킨 전선에서 오픈소스까지."
cover: "/journal/v1-30-days/patternflow-v1-complete.jpg"
highlight: true
draft: false
---

## 숨고르며 방향잡기

LED패널과 ESP32, 엉킬대로 엉킨 전선들이 그럴싸한 모양으로 빚어졌다. 계획은 전혀 없었다. 모든게 가벼운 실수와 실험 하나에서 시작되었고 30일이 지난 지금은 올해를 걸어볼 프로젝트가 되었다.

실은 금방 또 그만두고 다른 것을 찾아 헤멜지도 모른다. 아니다, 이번에는 다를 것 같다. 외부에서 긍적적인 신호들을 받았다. 패턴플로우의 개념이 담긴 초기 프로토타입 릴스 하나가 이틀만에 1만 조회수를 넘겼다. 이후 올린 [레딧 글](https://www.reddit.com/r/arduino/comments/1so9er5/built_a_4knob_generative_pattern_controller_with/)에는 수많은 극찬과 구매의사가 담긴 댓글이 달렸다. 가능성이 보였다. 한 번 모든 걸 쏟아보기로 했다. 오픈소스로 전환하기 위하여 하루도 쉬지 않고 작업했다.

시작한 지 약 30일이 된 지금, 드디어 공개할 수 있을 만큼의 결과가 나왔다. 디테일은 앞으로 한참 채워야 한다. 쉬지 않고 달린 탓에 조금 지쳤다. 그래서 지금까지의 여정을 돌아보고 앞으로의 방향을 확고히 하고자 했다. 그 과정에서 돌아보니 30일짜리 프로젝트가 아니었다. 그보다 훨씬 전부터 태동하고 있었다. 이건 이 모든것을 훑어보는 글이다.
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

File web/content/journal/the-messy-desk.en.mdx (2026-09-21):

---
title: "The Messy Desk"
date: "2026-09-21T21:40:00+09:00"
excerpt: "Small talk"
cover: "/journal/the-messy-desk/messy-desk.jpg"
coverCaption: "The messy desk"
hideCover: true
highlight: true
draft: false
---

I'm not sure there's anything worth writing. Because everything's a jumble, like the messy desk in the photo below. The desk with the computer on it is in worse shape, so I won't be photographing that one.
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

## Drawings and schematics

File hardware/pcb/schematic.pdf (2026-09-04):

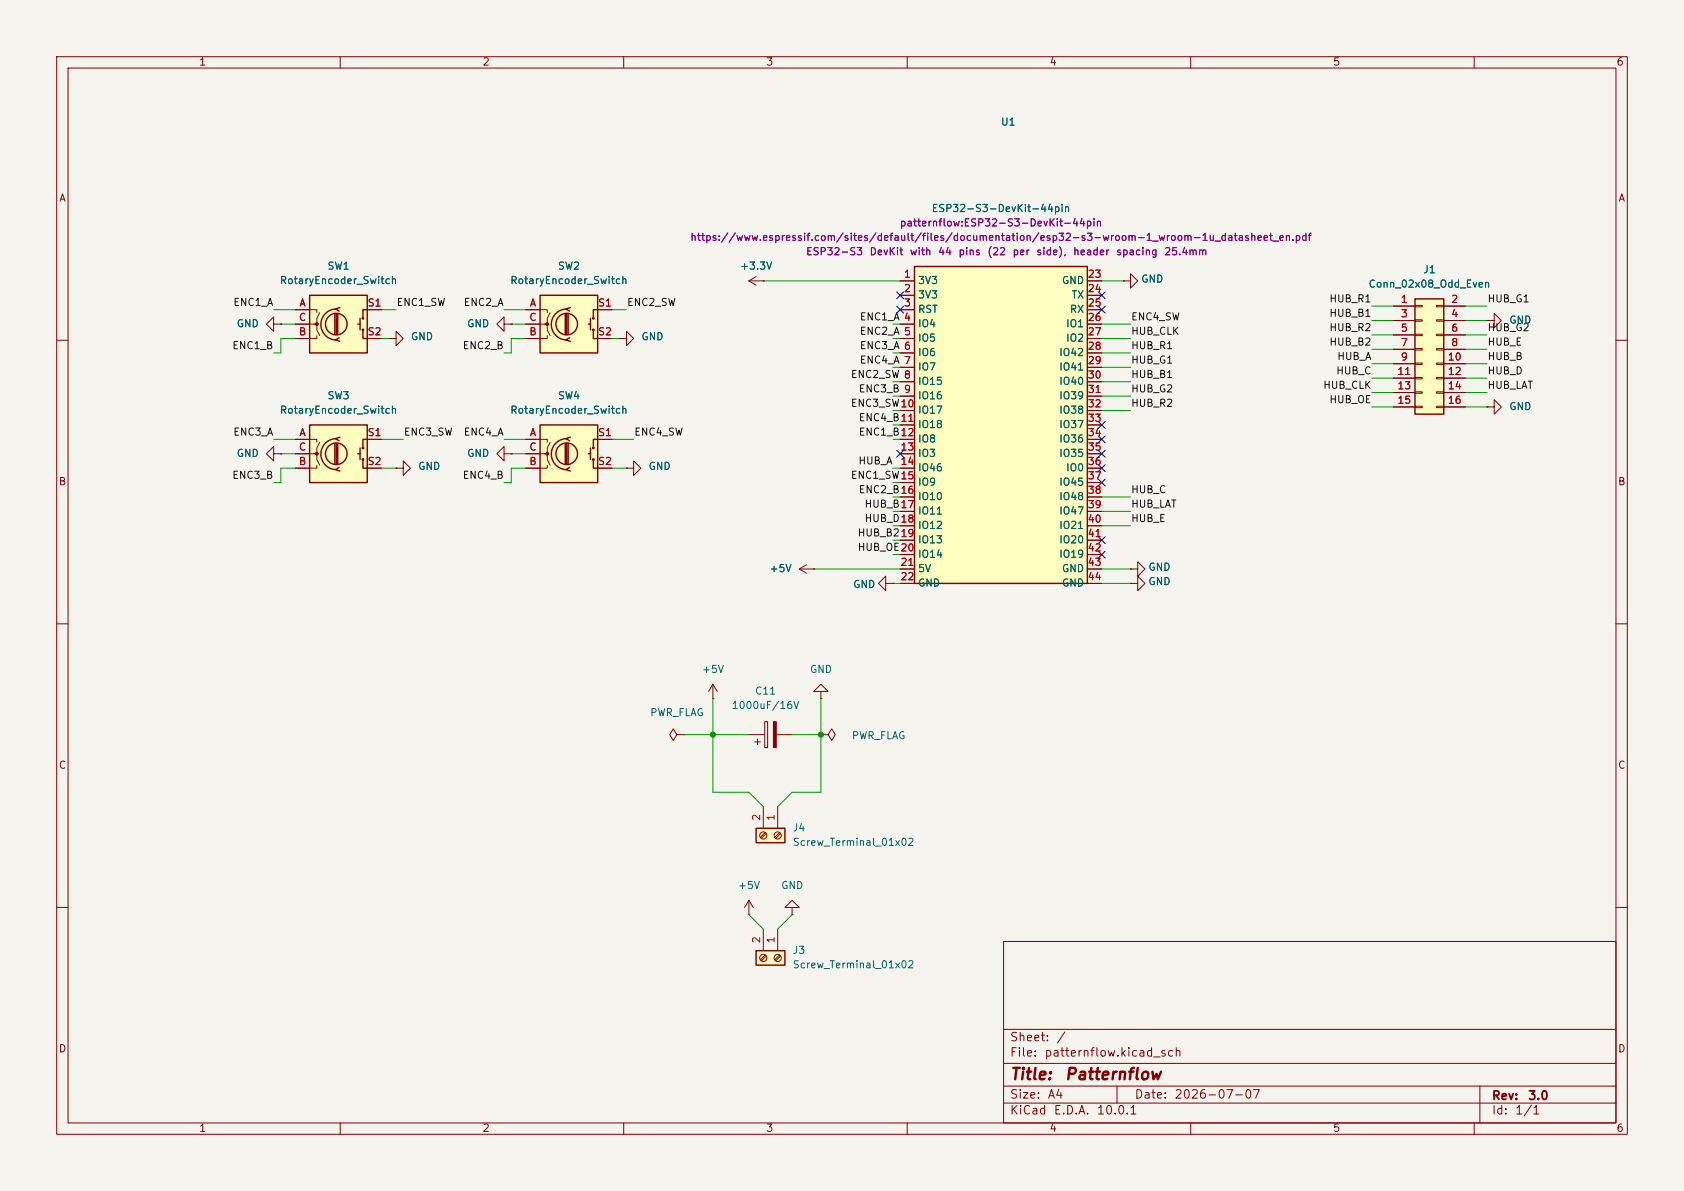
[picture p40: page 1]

https://www.espressif.com/sites/default/files/documentation/esp32-s3-wroom-1_wroom-1u_datasheet_en.pdf ESP32-S3 DevKit with 44 pins (22 per side), header spacing 25.4mm

Size: A4 | Rev: 3.0
KiCad E.D.A. 10.0.1 | Id: 1/1

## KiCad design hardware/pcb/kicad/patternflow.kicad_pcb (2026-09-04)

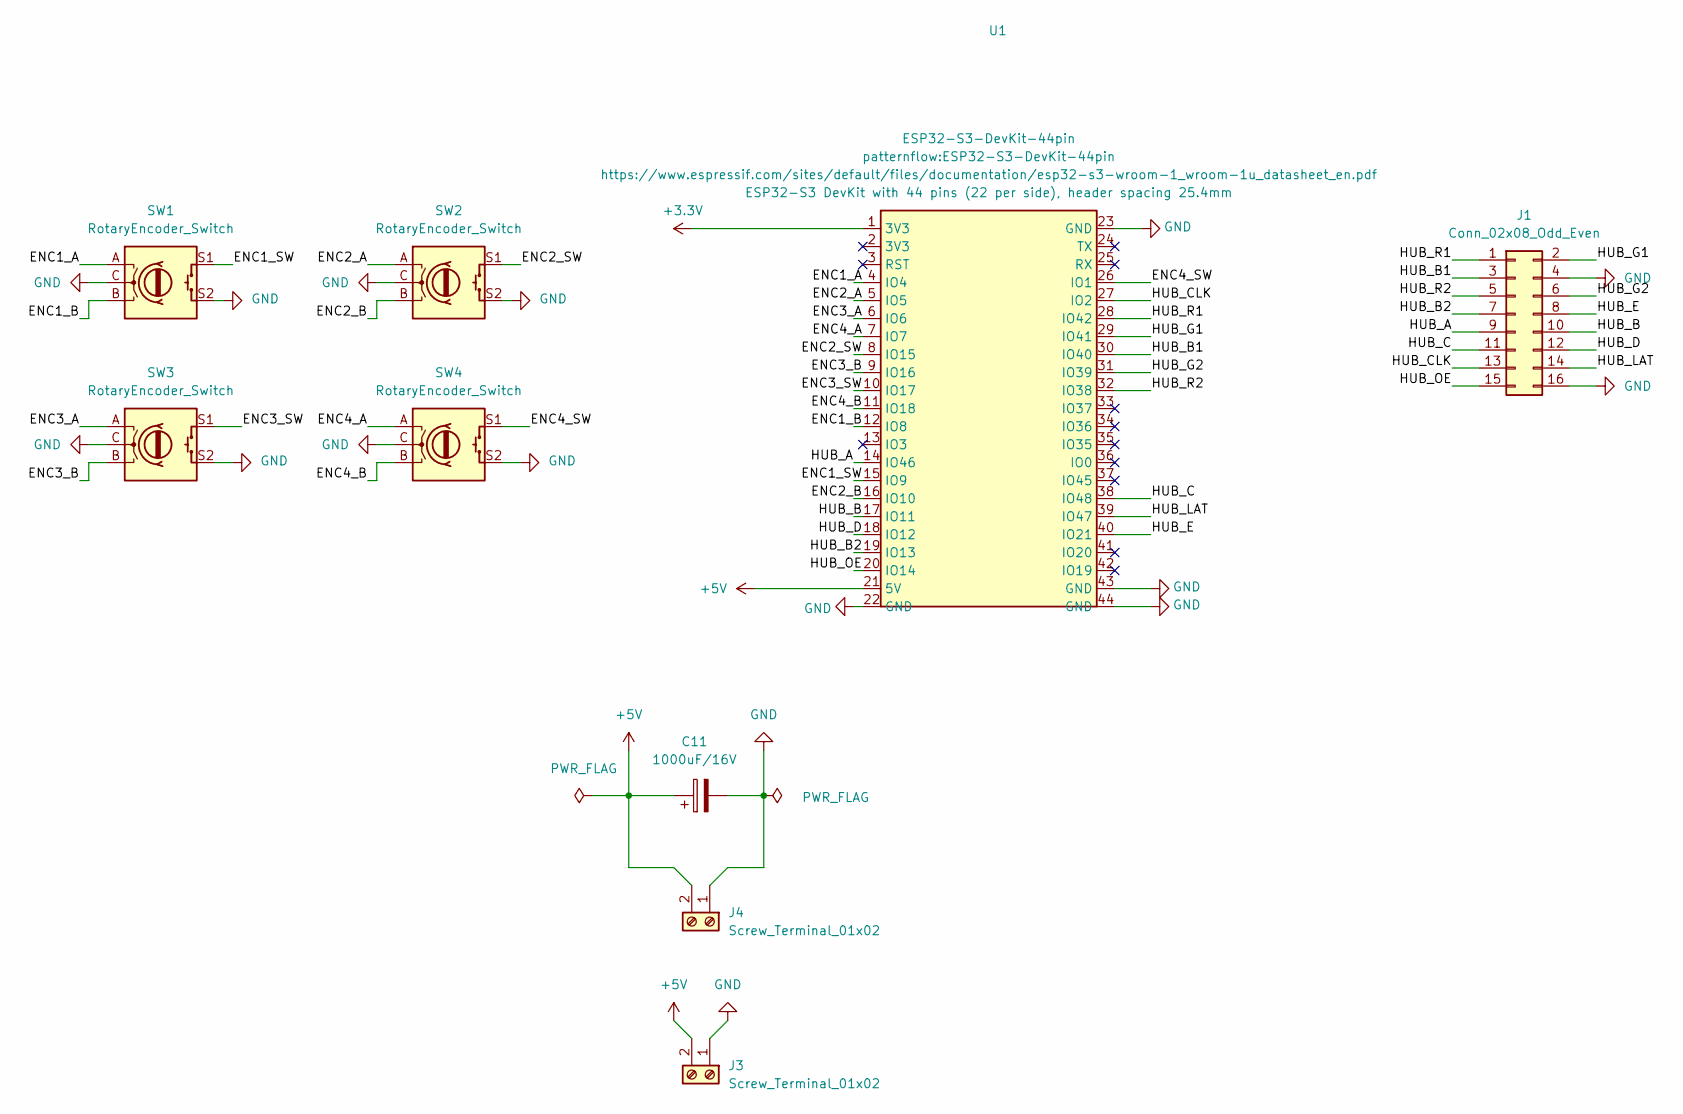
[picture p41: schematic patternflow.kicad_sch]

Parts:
C11: 1000uF/16V; CP_Radial_D10.0mm_P5.00mm
J1: Conn_02x08_Odd_Even; PinHeader_2x08_P2.54mm_Vertical
J3, J4: Screw_Terminal_01x02; TerminalBlock_MaiXu_MX126-5.0-02P_1x02_P5.00mm
SW1, SW2, SW3, SW4: RotaryEncoder_Switch; RotaryEncoder_Bourns_Vertical_PEC12R-3x17F-Sxxxx
U1: ESP32-S3-DevKit-44pin

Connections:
+3.3V: U1.1 (3V3)
+5V: C11.1, J3.2, J4.2, U1.21 (5V)
/ENC1_A: SW1.A, U1.4 (IO4)
/ENC1_B: SW1.B, U1.12 (IO8)
/ENC1_SW: SW1.S1, U1.15 (IO9)
/ENC2_A: SW2.A, U1.5 (IO5)
/ENC2_B: SW2.B, U1.16 (IO10)
/ENC2_SW: SW2.S1, U1.8 (IO15)
/ENC3_A: SW3.A, U1.6 (IO6)
/ENC3_B: SW3.B, U1.9 (IO16)
/ENC3_SW: SW3.S1, U1.10 (IO17)
/ENC4_A: SW4.A, U1.7 (IO7)
/ENC4_B: SW4.B, U1.11 (IO18)
/ENC4_SW: SW4.S1, U1.26 (IO1)
/HUB_A: J1.9, U1.14 (IO46)
/HUB_B: J1.10, U1.17 (IO11)
/HUB_B1: J1.3, U1.30 (IO40)
/HUB_B2: J1.7, U1.19 (IO13)
/HUB_C: J1.11, U1.38 (IO48)
/HUB_CLK: J1.13, U1.27 (IO2)
/HUB_D: J1.12, U1.18 (IO12)
/HUB_E: J1.8, U1.40 (IO21)
/HUB_G1: J1.2, U1.29 (IO41)
/HUB_G2: J1.6, U1.31 (IO39)
/HUB_LAT: J1.14, U1.39 (IO47)
/HUB_OE: J1.15, U1.20 (IO14)
/HUB_R1: J1.1, U1.28 (IO42)
/HUB_R2: J1.5, U1.32 (IO38)
GND: C11.2, J1.4, J1.16, J3.1, J4.1, SW1.C, SW1.S2, SW2.C, SW2.S2, SW3.C, SW3.S2, SW4.C, SW4.S2, U1.22 (GND), U1.23 (GND), U1.43 (GND), U1.44 (GND)

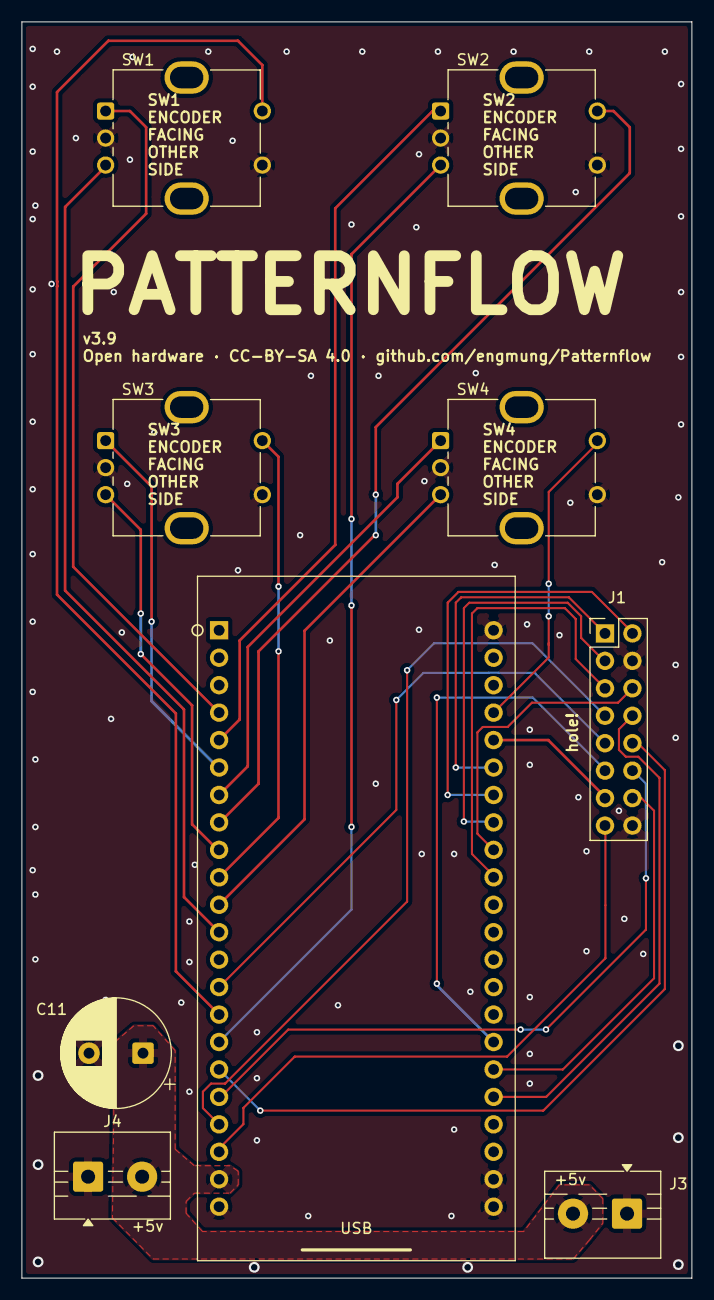
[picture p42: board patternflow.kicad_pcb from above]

Board: 2 copper layers, 62.0 x 116.2 mm, 9 parts (0 on the bottom side), 28 nets.

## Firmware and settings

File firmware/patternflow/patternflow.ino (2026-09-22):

// ═══════════════════════════════════════════════════════════
// PatternFlow — the device itself
//
// The panel, the four encoders, the pattern loader, Wi-Fi, sleep, /update and
// the web console. A build of this file with nothing else still does the thing
// Patternflow is for: load an interactive pattern and run it under four knobs.
//
// EVERY OTHER BUILD IN THIS REPOSITORY COMPILES THIS FILE UNCHANGED. Audio and
// Performance differ by two files in firmware/bundles/<name>/ and not one line
// here, so a change made for one edition lands in all of them. That is the
// whole point and also the whole risk. docs/EDITIONS.md is the reasoning;
// features/pf_feature.h is the interface; features/features.h is the composition.
//
// ── The rule ────────────────────────────────────────────────────────
//
// No feature is named in this file. Not in an #include, not in an #if, not in
// a string on the screen. Every feature reaches the core through the hooks in
// pf_feature.h, dispatched here as PFFeatures::something() that neither knows nor
// asks what is behind it. If you find yourself wanting `#if PF_OSC_ENABLED`
// here, the answer is a hook, or the feature does not belong in the core.
//
// The one thing this file DOES decide is where each hook fires in the frame.
// Which features run, and in what order, is the composition's business.
//
// ── If you are an AI agent editing this file ────────────────────────────
//
// You were probably asked to add or fix a feature, and this file is where the
// symptom showed up. That is not the same as this being where the fix goes.
//
// THIS FILE CHANGES FOR TWO REASONS ONLY: a bug in the device itself, or a
// real improvement to what the device is. A feature bends to fit the core.
// The core does not bend to fit a feature. If an edit here exists so that one
// feature can work, it is in the wrong file - put it behind a hook instead.
//
// The test takes one question: would this edit still be correct on a build
// that does not contain the feature you are working on? If the honest answer
// is "it would do nothing" or "it would be wrong", move it to features/.
//
// Three things that mislead agents in particular:
//
//   - A name is not a feature. `oscInfoShowing` is the NETWORK screen's own
//     flag and has had nothing to do with OSC for a long time. Do not follow
//     a name into a conclusion about what the code does, and do not rename
//     across this file to match a tidier mental model - that is a large diff
//     with no behaviour change, and it buries the real one underneath.
//
//   - The comments here explain WHY the code has its shape, and several are
//     the only surviving record of a bug that took hardware to find. They
//     are not clutter. Change the code and you update the comment; if you
//     cannot tell whether a comment is still true, leave it and say so.
//
//   - Compiling is not testing. Most of what has broken here broke silently
//     on a build that had no feature to notice. Build all three editions.
//
// ── What has actually gone wrong here ─────────────────────────────
//
// Four real regressions, all of them invisible on the build that was in front
// of the person who caused them. Read these before editing:
//
//   1. `InputFrame input{}` in the main loop. The braces are load-bearing. The
//      lane fields are written only by a feature that drives them, so without
//      the value-initialisation a build that has no such feature reads stack
//      garbage - and a garbage active-flag makes PFParams::apply return early,
//      which ignores the physical knobs. Shipped once. Do not drop the braces.
//
//   2. PFFeatures::loop(frame) must be dispatched every frame. It went missing
//      in v3.7.0 and every feature's loop silently stopped; nothing failed to
//      compile, and the default build had no features to notice.
//
//   3. Screen text that names a feature. "OSC / AUD" was hard-coded under the
//      NETWORK screen's toggle rows long after the rows themselves were built
//      from the feature list, so two of the three editions drew an instruction
//      for knobs that toggle nothing.
//
//   4. Widening a hook's signature. That is fine and the compiler will tell
//      you: build all three editions (firmware/bundles/build.sh, then `audio`
//      and `performance`) before you push. A hook change that compiles only
//      against the default is not tested.
//
// License: MIT
// ═══════════════════════════════════════════════════════════
#include <Arduino.h>
#include <Preferences.h>
#include "config.h"
#include "src/core_display.h"
#include "src/core_ui_text.h"
#include "src/core_encoders.h"
#include "src/core_wifi.h"
#include "src/core_hotspot.h"
#include "src/core_improv.h"
#include "src/core_ota.h"
#include "src/core_home_http.h"
#include "features/pf_features.h"
#include "src/core_web_update.h"
// Reads the demand the display driver measured while blitting, so it comes
// after core_display.h and before anything that sets brightness.
#include "src/core_power.h"
// Drives the panel and the CPU down for sleep mode. Needs core_display.h only,
// so it sits here rather than tangling with anything on the network side.
#include "src/core_sleep.h"
#include "src/core_banner.h"
#include "pattern_registry.h"
#include "src/core_thumbs.h"
// After the registry: the pattern manager serves and mutates that list.
#include "src/core_patterns_http.h"
#include "src/core_status_http.h"
#include "src/core_display_http.h"
#include "src/core_wifi_http.h"
#include "src/core_knobs_http.h"
#include "src/core_loop_sync.h"
#include "src/core_net_task.h"

// ── Device state ──────────────────────────────────────────────
//
// One flat block of globals rather than a struct, because every screen and
// the main loop read them and an .ino has no header to share a type through.
//
// These belong to the core and to nothing else. A feature that needs to know
// about them is TOLD, through PFFeatureFrame (features/pf_feature.h) - which is why
// that struct carries chromeVisible() and the mode instead of letting an
// feature reach in here. Adding a global for one feature's benefit is the most
// common way this file has drifted. The hook exists so you do not have to.
MatrixPanel_I2S_DMA *dma_display = nullptr;

int currentPatternIdx = 0;

enum AppMode {
  MODE_RUNNING,
  MODE_SELECTING
};

AppMode currentMode = MODE_RUNNING;
unsigned long lastMs = 0;
// Smoothed time to render one pattern frame, in microseconds. Read by /status;
// 0 until the first frame lands.
uint32_t renderFrameUs = 0;
float contentNoticeTimer = 0.0f;

// Global brightness: K1 longpress enters brightness mode, K1 rotation
// adjusts. Exits on a K1 click (instant), a second longpress, or 5s idle.
// The BRIGHTNESS notice stays on screen for the whole time the mode is
// active — the moment it disappears you're out. (It used to flash for
// 1.2s while the mode silently lived on for 5s, so you could never tell
// which state you were in.) Value persists in NVS.
Preferences prefs;
// NVS writes are the one kind of failure here whose symptom arrives a boot
// later, so they are counted rather than assumed. Published by /api/status:
// a board that is quietly failing to persist anything says so in a number
// instead of behaving strangely once, on somebody else's desk.
bool nvsUsable = false;
uint32_t nvsFailures = 0;
uint8_t currentBrightness = DEFAULT_BRIGHTNESS;
// What the panel is actually running at. Equal to currentBrightness unless the
// power clamp is holding it down (core_power.h) — kept separately so the
// clamp never rewrites the person's own setting.
uint8_t appliedBrightness = DEFAULT_BRIGHTNESS;
bool brightnessAdjusting = false;
uint32_t brightnessIdleAtMs = 0;
bool brightnessDirty = false;

// NETWORK screen: K2 longpress enters a status view. It lists whichever
// features declare a short name and a runtime switch — the sketch does not know
// what they are. Inside, TURNING K2 toggles the first row and K3 the second (right
// = on, left = off; both persist in NVS). Rotation, not clicks, so the K2
// longpress used to exit can't flip anything. Second K2 longpress or idle
// exits.
// NOTE ON THE NAME: this is the NETWORK screen's visibility flag, nothing
// more. OSC was hard-wired as that screen's first row back when it lived in
// the core; it is an ordinary feature now and the rows are built from whatever
// is loaded. The name survives because renaming it touches a dozen call sites
// for no behaviour change. It does NOT mean this file knows about OSC.
bool oscInfoShowing = false;
uint32_t oscInfoIdleAtMs = 0;

// NETWORK screen redraw pacing. The screen is static text: redrawing and
// flipping it every loop iteration (hundreds of Hz — no pattern renders in
// this mode) races the panel scanout and the text visibly flickers. Redraw
// only on entry, on a toggle, or at a slow poll so status changes still show.
uint32_t netInfoDrawnAtMs = 0;
bool netInfoDirty = false;

// KNOB MAP screen: K3 longpress shows which physical knob is which number
// (front view: K1 top-right, K2 top-left, K3 bottom-right, K4 bottom-left).
// Turning any knob lights its digit up green, so each knob can be verified
// without leaving the screen. K3 click, a second K3 longpress, or idle exits.
bool knobMapShowing = false;
uint32_t knobMapIdleAtMs = 0;
uint32_t knobMapDrawnAtMs = 0;
bool knobMapDirty = false;
uint32_t knobMapActiveAtMs[4] = {0, 0, 0, 0};

// SLEEP: panel off, board idle, still on the network (src/core_sleep.h).
// Entered by turning K1 on the NETWORK screen, by <prefix>/sleep over MQTT, or
// by GET /api/display?sleep=1. Woken by any PHYSICAL knob turn or button press
// — sleepKnobSnapshot is the reference the turn is measured against, because
// input.knobDeltas has remote deltas merged into it by then and a show still
// streaming knob values must not switch the lights back on.
long sleepKnobSnapshot[4] = {0, 0, 0, 0};

// The selected pattern, remembered across sleep and across power-off. Stored as
// a SLUG rather than an index: installing or deleting one .pfm renumbers the
// list, so an index would come back as somebody else's pattern. Written on a
// debounce for the same reason brightness is — spinning K4 through fifty
// patterns should not be fifty NVS writes.
bool patternDirty = false;
uint32_t patternChangedAtMs = 0;
const uint32_t PATTERN_SAVE_DELAY_MS = 3000;

// Restoring a module at boot is not the same risk as picking one by hand.
// Loading any .pfm drops internal heap from ~14 KB to ~5 KB (measured), which
// is under what the console needs to send a page and low enough that a printf
// can fail to allocate its lock and abort() — so a pattern that is merely
// marginal can take the board down a few seconds after it starts. Picked by
// hand that is a crash you reboot out of; remembered, the reboot restores the
// same pattern and does it again, every 4 seconds, with the console alive too
// briefly to fix anything. Only a full NVS erase gets out of that, which no
// owner can do.
//
// So the restore arms a latch first and disarms it once the pattern has run
// long enough to be trusted. A boot that finds the latch still armed knows the
// previous boot did not survive its own remembered pattern, and forgets it.
// Origin is compiled in and cannot fail this way, so remembering it costs no
// NVS traffic at all.
bool patternLatchArmed = false;

// ── SELECT-mode browsing ────────────────────────────────────────
// The knob moves the highlight; the pattern loads only once the knob has
// rested for SELECT_SETTLE_MS. Until it does, the panel shows the
// highlighted pattern's thumbnail (src/core_thumbs.h says why: a module's
// setup() can take seconds, and loading on every detent froze the loop for
// that long while the encoder kept counting). A thumbnail is taken when a
// pattern is LEFT, provided it has run for THUMB_MIN_RUN_MS and the canvas
// still holds its frame rather than another pattern's thumbnail.
const uint32_t SELECT_SETTLE_MS = 350;
// Detents per pattern while browsing. One per detent overshot: a hand that
// meant one pattern landed two or three along, and once the load stopped
// holding the frame that overshoot was the whole of what still felt wrong.
// Whole steps move the highlight; the remainder waits for the next detent
// and a change of direction cancels it, so nothing creeps.
const int SELECT_DETENTS_PER_STEP = 3;
int selectAccum = 0;
const uint32_t THUMB_MIN_RUN_MS = 2000;   // after setup() returns; a heavy module's first two seconds are already its picture
bool selectPending = false;         // the highlight moved and nothing has loaded since
uint32_t selectMovedAtMs = 0;
bool canvasShowsThumb = false;      // the canvas holds a thumbnail, not the running pattern
const uint32_t PATTERN_LATCH_CLEAR_MS = 15000;

// Shown whenever no pattern is resident: the web console paused it, or a module
// refused to load. Before this the render loop simply drew nothing and flipped
// the buffer anyway, so the panel showed a torn, flickering leftover frame —
// which read as "the pattern is broken" even when the cause was just an open
// browser tab.
uint32_t pausedDrawnAtMs = 0;
bool pausedDirty = true;

// UPDATE screen: entered from the NETWORK screen by turning K4. While it
// shows, the /update endpoint is ARMED — that is the whole security model
// (see core_web_update.h): flashing over the LAN requires someone at the
// device first. K4 click exits (disarming), except mid-flash. The idle
// timeout is long because the user is at their computer fetching a .bin.
bool updateShowing = false;
uint32_t updateIdleAtMs = 0;
uint32_t updateDrawnAtMs = 0;
bool updateDirty = false;
// The percentage the upload handler last reported, from the network core;
// loop() draws it. -1 when nothing is being received.
volatile int uploadPctShown = -1;

const uint32_t MODE_HOLD_MS = 1000;
const uint32_t BRIGHTNESS_IDLE_MS = 5000;
// How long the value has to be still before it is written to NVS - the
// console's slider sends a step for every pixel of a drag.
const uint32_t BRIGHTNESS_SAVE_DELAY_MS = 3000;
const uint32_t OSC_INFO_IDLE_MS = 8000;
const uint32_t NET_INFO_REDRAW_MS = 250;
const uint32_t KNOB_MAP_IDLE_MS = 8000;
const uint32_t KNOB_MAP_HILITE_MS = 600;
const uint32_t UPDATE_IDLE_MS = 600000;  // 10 min — downloading a build takes a while
const float CONTENT_NOTICE_SECONDS = 1.0f;
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
void loop() {
  PFRuntime::LoopScope runtime([] { return loadInFlight; });
  // Above the sleep block on purpose: a board that is asleep still has to be
  // able to disarm the latch, or a device told to sleep within the first few
  // seconds of boot would forget a pattern that never misbehaved.
  clearPatternLatchIfStable();

  // Wi-Fi, the console, Improv, OTA and the self-update's housekeeping are
  // serviced by the network task on Core 0. Only if that task could not be
  // created does loop() poll them itself, as it did before 3.9.1.
  if (!PatternflowNetTask::isDualCoreActive()) {
    PatternflowWifi::tick();
    PatternflowHotspot::tick();
    PatternflowImprov::handle();
    PatternflowOta::handle();
    PatternflowHttp::handle();
    PatternflowWebUpdate::handle();
    if (PatternflowNetTask::servicesReady) PatternflowNames::tick();
    PFThumbs::serviceDisk();
  }

  // Once connected (or reconnected), start the network services.
  if (PatternflowWifi::consumeJustConnected()) {
    if (!PatternflowNetTask::servicesReady) PatternflowNames::begin();
    PatternflowOta::begin();
    PatternflowHomeHttp::begin();
    PatternflowWebUpdate::begin();
    PatternflowPatternsHttp::begin();
    PatternflowStatusHttp::begin();
    PatternflowDisplayHttp::begin();
    PatternflowWifiHttp::begin();
    PatternflowKnobsHttp::begin();
    PatternflowHotspot::registerRoutes();
    PatternflowNames::announce();
    PFFeatures::onNetwork();
    Serial.println("[NET] services started");
    reportHeap("services up");
    // Every route exists: the network task may serve the console now.
    PatternflowNetTask::servicesReady = true;
  }

  // The frame boundary. Whatever a handler on the network core needed done
  // on this task — evicting or restoring the module, walking the pattern
  // list, touching a feature's client — runs here, before the frame.
  PFLoopSync::service();
  // A pattern the loader task finished with becomes the running one here,
  // before anything below looks at what is running.
  serviceAsyncLoad();
  PFThumbs::service();

  // Deferred module-list rebuilds requested by uploads/deletes — run here,
  // outside any HTTP transaction.
  PatternflowPatternsHttp::tick();

  unsigned long now = millis();
  // The one place dt is produced, so the one place it can be bounded. Every
  // pattern integrates against it - position += velocity * dt - and a frame
  // that took a quarter of a second moves everything a quarter of a second,
  // in one step, which reads as the picture jumping rather than running.
  //
  // Those frames are not hypothetical and they are not rare: installing a
  // pattern, an NVS commit and a thumbnail write all produce them. Measured
  // on a panel during an ordinary upload session, runtime.maxUs reached
  // 273,949 us against a 12,000 us nominal - 23x - and over50ms counted 1,661.
  //
  // 100 ms is twice the over50ms threshold this file already treats as long,
  // so an honestly slow pattern passes through untouched and only a stall is
  // caught. Clamping loses that time rather than spending it: animation runs
  // slow for one frame instead of teleporting, which is the right way round.
  // Do not remove this without watching a heavy pattern across an upload.
  constexpr unsigned long DT_MAX_MS = 100;
  unsigned long elapsed = now - lastMs;
  if (elapsed > DT_MAX_MS) elapsed = DT_MAX_MS;
  float dt = elapsed / 1000.0f;
  lastMs = now;
  runtime.housekeepingDone();
  const uint32_t frameStartedUs = micros();

  // Every feature's per-frame hook: the MQTT keepalive, the show player's tick,
  // the weather scheduler, the audio websocket's accept/handshake pump, the
  // on-board FFT.
  //
  // **This was missing.** The feature port removed the concrete calls that used
  // to live above — correctly, they belong to the features now — and never
  // added the dispatcher that replaced them, leaving two orphaned comments
  // where the calls had been. Nothing failed loudly: `begin()` still ran, so
  // :81 accepted TCP and every route answered; the websocket simply never
  // completed a handshake because nobody was pumping it, and MQTT never
  // reconnected. The features were all present, all initialised, and all
  // frozen. Ahead of the render so a slow pattern cannot starve a socket.
  {
    PFFeatureFrame frame{dt, currentContentName(),
                       currentMode == MODE_RUNNING, chromeVisible(),
                       currentPatternIdx, (int)currentMode};
    PFFeatures::loop(frame);
  }

  // Value-initialised, and it has to be. PFInputFrame is a plain ABI struct
  // with no default member initialisers, and `knobAudioActive` /
  // `knobAudioValue` are written only by a feature that drives a lane. The
  // old default build always carried audio, whose fillInput wrote them every
  // frame unconditionally, so nobody ever saw what happens without one:
  // indeterminate memory reaching PFParams::apply, where a garbage `active`
  // flag pins a pattern's parameter to a garbage value. Composing audio out
  // is what surfaced it — /api/status reported lanes of 1.576 on a build with
  // nothing driving them. Zeroing ~100 bytes a frame costs nothing.
  InputFrame input{};
  readInputFrame(input);

  // One-shot click events for the mode buttons, consumed every frame so a
  // click that lands outside its mode can't stay latched and fire later.
  bool k1Clicked = logicalButton(0)->clicked();
  bool k2Clicked = logicalButton(1)->clicked();
  bool k3Clicked = logicalButton(2)->clicked();
  bool k4Clicked = logicalButton(3)->clicked();
  // Any click during a wake/snooze alarm cycle dismisses it — the person in
  // the room outranks the schedule.
  if (!brightnessAdjusting && !oscInfoShowing && !knobMapShowing &&
      !updateShowing && (k1Clicked || k2Clicked || k3Clicked || k4Clicked)) {
    PFFeatures::onUserInput();
  }

  // ── SLEEP ──────────────────────────────────────────────────────────
  // Remote requests land here, not in the MQTT callback that produced them:
  // stopping a DMA engine and reclocking the CPU inside client.loop() is the
  // kind of thing this file's history warns about.
  {
    bool wantSleep;
    if (PFFeatures::requestSleep(&wantSleep)) PatternflowSleep::request(wantSleep);
  }
  // Flashing beats sleeping, in both directions: a device that is being
  // reflashed does not fall asleep underneath the upload, and one that is
  // already asleep when an image starts arriving wakes up for it. Sleep stops
  // the DMA engine, drops the CPU to 80 MHz and paces the loop — none of which
  // an image being written to flash should have to put up with, and whoever is
  // flashing wants the UPDATE screen anyway.
  const bool flashInFlight = PatternflowWebUpdate::isUploading() ||
                             PatternflowWebUpdate::isRebootPending() ||
                             PatternflowOta::isInProgress();
  if (!flashInFlight && PatternflowSleep::applyPending() &&
      PatternflowSleep::isSleeping()) {
    // Whatever the knobs read at this moment is "not touched since".
    for (int i = 0; i < 4; i++) sleepKnobSnapshot[i] = input.knobs[i];
  }
  PFFeatures::onSleep(PatternflowSleep::isSleeping());
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

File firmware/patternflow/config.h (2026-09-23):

// ═══════════════════════════════════════════════════════════
// PatternFlow - Hardware Configuration & Constants
// License: MIT
// ═══════════════════════════════════════════════════════════

#ifndef CONFIG_H
#define CONFIG_H

#include <Arduino.h>

// ── A variant's settings, before anything has a default ─────────────────
// Every tunable in this file and in net_config.h is `#ifndef`-guarded, which
// only helps somebody who can define the value FIRST. config.h is the first
// project header the sketch includes, so this is the earliest point that
// exists — and a variant that wants a different panel clock, a different
// transmit power or a different brightness cap drops an features/overrides.h
// and changes nothing else in the tree.
//
// The RFC named this file (§2.4) and it was never built; the first variant
// that wanted a setting rather than a feature is what surfaced it. Pair with
// features/features_local.h, which does the same job for the feature list.
#if defined(__has_include)
#if __has_include("features/overrides.h")
#include "features/overrides.h"
#endif
#endif

// --- Arduino macro detox ---
// Arduino.h defines PI / TWO_PI / HALF_PI / DEG_TO_RAD / RAD_TO_DEG / EULER as
// bare object-like macros, so a pattern that declares its own constant with
// one of those names ("static constexpr float PI = ...") gets preprocessor-
// mangled into a compile error — AI-generated patterns do this all the time.
// Replace the macros with typed constants: every existing use of PI keeps
// working, and a pattern namespace may now legally shadow them with its own
// definitions. (Function-like macros such as min/max/abs/constrain are left
// alone — patterns rely on them and they only expand before a parenthesis.)
//
// float, not double: Arduino's macros are double literals, which silently
// promotes float expressions like `hash * TWO_PI` to SOFTWARE-emulated double
// math on the S3 (its FPU is single-precision only). Patterns are float math
// throughout, so float constants keep the pixel loop on the hardware FPU;
// the precision difference is in the 8th significant digit — invisible.
#ifdef PI
#undef PI
#endif
#ifdef TWO_PI
#undef TWO_PI
#endif
#ifdef HALF_PI
#undef HALF_PI
#endif
#ifdef DEG_TO_RAD
#undef DEG_TO_RAD
#endif
#ifdef RAD_TO_DEG
#undef RAD_TO_DEG
#endif
#ifdef EULER
#undef EULER
#endif
constexpr float PI         = 3.14159265358979323846f;
constexpr float TWO_PI     = 6.28318530717958647693f;
constexpr float HALF_PI    = 1.57079632679489661923f;
constexpr float DEG_TO_RAD = 0.01745329251994329577f;
constexpr float RAD_TO_DEG = 57.29577951308232087680f;
constexpr float EULER      = 2.71828182845904523536f;

// --- Display Specifications ---
// Logical canvas (PANEL_RES_W/H) is what patterns, menus and modules see.
// Physical size + chain is what the HUB75 driver is told. A native 128×64
// module and two 64×64 modules daisy-chained are the same 128×64 canvas,
// but the driver must be configured differently — hence PANEL_GEOMETRY.
// PlatformIO: -DPANEL_GEOMETRY=PANEL_GEOM_64x64_CHAIN2 for firmware64x2.
// Arduino IDE: uncomment a PANEL_GEOMETRY line below, then build.
//
// A pattern composed for a grid that ISN'T the panel — a 64x128 portrait
// pattern on this 128x64 panel, say — is a separate matter, handled per
// pattern with PFCanvas::setFrame(). See README.md.
// Running a non-stock panel? Please report how it went, working or not:
// https://github.com/engmung/Patternflow/issues/224
#define PANEL_GEOM_128x64_SINGLE 1  // one 128×64 module (stock)
#define PANEL_GEOM_64x64_SINGLE  2  // one 64×64 module
#define PANEL_GEOM_64x64_CHAIN2  3  // two 64×64 modules daisy-chained → 128×64

// #define PANEL_GEOMETRY PANEL_GEOM_64x64_CHAIN2
#ifndef PANEL_GEOMETRY
#define PANEL_GEOMETRY PANEL_GEOM_128x64_SINGLE
#endif

#if PANEL_GEOMETRY == PANEL_GEOM_64x64_SINGLE
  #define PANEL_PHYS_W 64
  #define PANEL_PHYS_H 64
  #define PANEL_CHAIN  1
  #define PANEL_RES_W  64
  #define PANEL_RES_H  64
#elif PANEL_GEOMETRY == PANEL_GEOM_64x64_CHAIN2
  #define PANEL_PHYS_W 64
  #define PANEL_PHYS_H 64
  #define PANEL_CHAIN  2
  #define PANEL_RES_W  128
  #define PANEL_RES_H  64
#else
  #define PANEL_PHYS_W 128
  #define PANEL_PHYS_H 64
  #define PANEL_CHAIN  1
  #define PANEL_RES_W  128
  #define PANEL_RES_H  64
#endif

#if PANEL_RES_W != (PANEL_PHYS_W * PANEL_CHAIN)
#error "PANEL_RES_W must equal PANEL_PHYS_W * PANEL_CHAIN"
#endif
#if PANEL_RES_H != PANEL_PHYS_H
#error "PANEL_RES_H must equal PANEL_PHYS_H"
#endif
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

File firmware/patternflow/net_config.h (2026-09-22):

// ═══════════════════════════════════════════════════════════
// PatternFlow - Network configuration (core)
//
// Everything the DEVICE needs to be on a network: the shared Wi-Fi
// connection, Improv provisioning, its own name and version, OTA, the
// browser self-update page, and the scale of the absolute bus.
//
// Nothing here belongs to a feature. Each feature's tunables — OSC ports,
// the audio WebSocket port, MQTT broker settings, weather polling — live in
// features/<name>/<name>_config.h, next to the code that reads them, and are
// only compiled when a composition carries that feature. Until 2026-09 they
// sat in this file, which made a core header 40 % feature settings and gave
// every flag two places to be defaulted.
//
// Per-device secrets and toggles live in patternflow_secrets.h (gitignored).
// That file is included FIRST below, so anything it #defines wins; the
// #ifndef blocks here — and in every feature's config header — only fill in
// defaults for whatever it left unset. No #undef gymnastics required: leave a
// line out of the secrets file to accept the default.
//
// Copy patternflow_secrets.example.h to patternflow_secrets.h to start.
// License: MIT
// ═══════════════════════════════════════════════════════════
#pragma once

// Per-device overrides first. Without this file every default below applies
// (Wi-Fi placeholders, OTA on).
//
// A feature's settings TUNE it; they never decide whether it is in the build.
// That is the composition's job — see features/features.h and docs/EDITIONS.md.
#if __has_include("patternflow_secrets.h")
#include "patternflow_secrets.h"
#endif

// ── Wi-Fi ────────────────────────────────────────────────────────────
// Whether the panel has a radio at all. 0 makes a USB-only instrument:
// everything network-side (console, OTA, every feature that dials out)
// compiles out behind PF_WIFI_NEEDED in core_wifi.h.
#ifndef PF_WIFI_ENABLED
#define PF_WIFI_ENABLED 1
#endif

// Credentials normally come from patternflow_secrets.h. The placeholders
// here only keep a secret-less checkout compiling.
#ifndef PF_WIFI_SSID
#define PF_WIFI_SSID "YOUR_WIFI_SSID"
#endif
#ifndef PF_WIFI_PASS
#define PF_WIFI_PASS "YOUR_WIFI_PASSWORD"
#endif
// Maximum Wi-Fi transmit power, applied in core_wifi.h right after the join.
// The ESP32 default, 19.5 dBm, is the maximum the radio does.
//
// History: from 2026-08 to 2026-09-22 this was WIFI_POWER_13dBm, a cut taken
// from a radio test report against the EU 20 dBm EIRP limit. On 2026-09-22
// the hotspot bench showed what that cost: a phone right next to the panel
// received the panel's data frames so badly that a 10 KB console page took
// 4-9 s over the panel's own AP, and 0.5-1 s at full power (the uplink, the
// phone's own 20 dBm, was fine either way; a router's antenna and receiver
// had hidden the asymmetry on the home network). The owner retired the cap:
// full performance, conformance to be handled elsewhere. Valid values
// (WiFiGeneric.h): WIFI_POWER_19_5dBm, _19dBm, _18_5dBm, _17dBm, _15dBm,
// _13dBm, _11dBm, _8_5dBm, _7dBm, _5dBm, _2dBm.
#ifndef PF_WIFI_TX_POWER
#define PF_WIFI_TX_POWER WIFI_POWER_19_5dBm
#endif

// Wi-Fi is non-blocking (see core_wifi.h): boot never waits for the join.
// While disconnected, core_wifi.h re-issues WiFi.begin() at this interval
// until it links up.
#ifndef PF_WIFI_RETRY_INTERVAL_MS
#define PF_WIFI_RETRY_INTERVAL_MS 5000
#endif

// ── Improv-Serial Wi-Fi provisioning ─────────────────────────
// Lets the browser flasher (ESP Web Tools, behind the website's "Flash"
// button) set Wi-Fi over USB serial right after flashing, instead of baking
// credentials into the binary. The SSID/password are stored in NVS and used
// in preference to the placeholders above on the next boot. See
// src/core_improv.h. On by default; only compiled in when Wi-Fi is actually
// used (i.e. at least one of OTA/OSC/audio is enabled).
// ── Hotspot ───────────────────────────────────────────────────────────
// The panel as a network of its own (src/core_hotspot.h). `auto` raises
// it once the station has had no link for PF_HOTSPOT_AUTO_AFTER_MS and
// drops it when the station joins and nobody is on it; the mode and the
// password are settings on /wifi, these are their defaults. The SSID is
// the board alias (patternflow-a1b2). The password is the same on every
// panel by default, like FlowLocal's, so a person can join from memory;
// anyone who wants it private changes it on the console.
#ifndef PF_HOTSPOT_PASS
#define PF_HOTSPOT_PASS "patternflow"
#endif
#ifndef PF_HOTSPOT_AUTO_AFTER_MS
#define PF_HOTSPOT_AUTO_AFTER_MS 15000
#endif
// Station retries while the hotspot is up and empty: each one is a scan
// with the AP off the air for a second or two, so they are rare. With
// someone on the hotspot there are none (core_wifi.h).
#ifndef PF_HOTSPOT_STA_RETRY_MS
#define PF_HOTSPOT_STA_RETRY_MS 300000
#endif
#ifndef PF_HOTSPOT_MAX_CLIENTS
#define PF_HOTSPOT_MAX_CLIENTS 4
#endif
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

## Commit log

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2026-05-21 firmware: extract core_math / core_color / core_noise shared libs
    Origin and WaveSaw each carried their own sin LUT, HSV→RGB converter,
    and Perlin noise table — same code, duplicated, with different LUT
    sizes and slightly different APIs. Lift them into three reusable
    headers so new patterns inherit them by include, and so memory is
    spent once instead of per-pattern.
    - core_math.h: PFMath:: { sinLUT[256], buildSinLUT, fastSin, fastCos, fract, lerp }
    - core_color.h: PFColor:: { hsvToRgb, ColorStop, sampleRamp }
    - core_noise.h: PFNoise:: { perlin2D, fractal2D, perm[512], fade, grad2 }
    buildSinLUT is idempotent (guarded), so patterns keep calling it from
    their setup() without coordination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
    [pattern_origin.h, pattern_wave_saw.h]
2026-05-21 firmware: make OSC a sidechannel instead of a content mode
    OSC never draws to the LED — it only emits knob/button/status messages
    over UDP. Treating it as a third ContentMode alongside Pattern and
    Video forced the user to switch into "OSC EXP" mode to enable the
    output, which meant the matrix went blank while OSC was active.
    Now:
    - ContentMode is back to PATTERN ↔ VIDEO only (toggle on K3 longpress).
    - PatternflowOsc::update() is called every frame, in every mode.
    - When PF_OSC_ENABLED is 0 the call compiles down to nothing.
    - drawOscMode() and the CONTENT_OSC enum are removed.
    External effect: enabling OSC no longer hides the visuals. A laptop
    running Max for Live receives knob deltas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
    [patternflow.ino]
2026-05-21 firmware: route patterns through PFCanvas instead of dma_display
    Patterns used to write directly to dma_display, which made every
    pattern responsible for the LED driver. Output post-processing
    (gamma, color temperature, global brightness, dithering) had nowhere
    to live except duplicated inside each draw() — and any pattern
    written by a contributor (or LLM-generated from CUSTOM_PATTERNS.md)
    could destabilize the matrix output by getting the call sequence
    wrong.
    New flow:
    - core_canvas.h owns a 128×64 RGB888 buffer.
    - Patterns call PFCanvas::setPixel(x, y, r, g, b) — no driver knowledge.
    - Patterns call PFCanvas::present() once at the end of draw(); that
    is the single point that touche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
    [pattern_origin.h, pattern_wave_saw.h]
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2026-05-21 firmware: K2 longpress = OSC info screen + runtime toggle (NVS persisted)
    Previously, OSC could only be turned on/off by rebuilding the firmware
    with PF_OSC_ENABLED. That's fine for a one-time decision, but it makes
    "is OSC working right now?" a guess — you can't see the IP, can't tell
    if Wi-Fi connected, can't tell why the laptop isn't receiving anything.
    K2 longpress now opens a full-screen OSC status view:
    - OSC ON / OFF (color-coded green/red)
    - Wi-Fi state (CONNECTING / READY / WIFI TIMEOUT / WIFI LOST / OFF)
    - Local IP (— if not connected)
    - Configured TX remote: host:port
    - Footer: "K2 = TOGGLE LONG = EXIT"
    Inside the screen, K2 short press flips OSC on or off at runtime.
    This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
    [patternflow.ino]
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2026-05-24 add per-channel gamma + white balance + saturation boost in pfcanvas
    js pattern lab preview goes through monitor gamma (~2.2 sRGB) and uses
    sRGB primaries; the led panel does linear PWM with LED primaries. same
    RGB triplets render perceptibly different — typically cyans drift green,
    whites go warm-pink because the red LED is brighter per duty cycle than
    green/blue. one global gamma=2.4 LUT can't address either issue.
    split the canvas's gamma LUT into three (R/G/B) and pre-multiply a
    per-channel white-balance gain into each LUT, so the inner present()
    loop pays the same cost as before. defaults are a mild correction tuned
    for typical HUB75 panels (steeper R gamma, gentler B gamma, R/G trim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
    [config.h]
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2026-05-26 add arduinoota wireless flashing and move osc_secrets to top level
    new src/core_ota.h wraps ArduinoOTA so the main sketch only needs
    PatternflowOta::begin() in setup() and PatternflowOta::handle() at the
    top of loop(). wifi connection is shared with osc — whichever module
    runs first brings it up, the other reuses it. both modules can be
    enabled independently via PF_OSC_ENABLED / PF_OTA_ENABLED. ota is on
    by default; the idle cost is one non-blocking udp poll per frame.
    mdns hostname defaults to "patternflow.local" via PF_OTA_HOSTNAME, no
    upload password by default (fine on a trusted lan, easy to add inside
    core_ota.h if needed). progress and errors print to serial.
    moved osc_secrets.exam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
    [config.h, patternflow.ino]
2026-05-26 add default ota upload password to satisfy arduino ide 2.x
    arduino ide 2.x's network-upload dialog won't submit with an empty
    password field even when the device has no auth configured, so the
    previous "no password" default left users locked out of the IDE path
    (the espota.py CLI still works fine without). ship a known default
    "patternflow" and document it. PF_OTA_PASSWORD is overridable from
    osc_secrets.h; set to "" to disable auth entirely (only useful with the
    CLI). guarded with a length check so an empty override doesn't set an
    empty-string MD5 hash and confuse the handshake.
    [OTA] Ready serial log now reports whether auth is on or off so
    debugging is faster.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
    [config.h]
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2026-05-27 add audio-react foundation: ws server + opt-in knob override (phase 1)
    phase 1 lays the pipeline end-to-end with a manual 4-slider test page;
    phase 2 will swap that page for the real audio-react ui (file / tab /
    mic capture + per-band fft + base ± range mapping).
    firmware additions:
    - src/core_audio_ws.h. small wrapper around WebServer (port 80, serves
    the html bundle) and WebSocketsServer (port 81, receives knob frames).
    reuses the wi-fi connection brought up by osc or ota — neither has to
    be enabled for audio to work, and any combination of the three coexists.
    - src/audio_index.h. PROGMEM html bundle. four sliders, status indicator,
    auto-reconnect ws client, "release all" butto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
    [config.h, pattern_origin.h, patternflow.ino]
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2026-05-27 audio-react phase 3: rewrite on async libraries so traffic doesn't stall the pattern loop
    phase 1/2 used WebServer + WebSocketsServer (Links2004). they're
    synchronous: every wsServer.loop() in our handle() drained pending
    frames on whichever core called loop() — which is core 1, the same
    core that runs pattern render. with no traffic everything looked fine,
    but the moment the browser started sending knob updates (~30 frames/s
    per band x 4 bands) the parse + atomic-write work piled up on core 1
    and squeezed pattern fps and encoder reads down to multi-second
    intervals. that's the bug the user hit.
    switch to ESPAsyncWebServer + AsyncTCP. these dispatch HTTP and WS
    events from the lwIP task o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
    [config.h]
2026-05-27 Revert "audio-react phase 3: rewrite on async libraries so traffic doesn't stall the pattern loop"
    This reverts commit 27bb8389f0d7393074cb24d81994e194bc9e18aa.
    [config.h]
2026-05-29 Reorganize network config and secrets
    Wi-Fi now backs three features (OTA, OSC, audio-react), so the
    "osc_secrets" name and the OSC-centric layout no longer fit.
    - Rename osc_secrets.{h,example.h} -> patternflow_secrets.{h,example.h},
    organized into Wi-Fi / OTA / OSC / Audio sections.
    - Extract all connectivity config out of config.h into net_config.h,
    which includes the secrets file FIRST and then fills #ifndef defaults.
    This drops the old #undef/#define override dance; config.h is now
    hardware-only.
    - Default OTA to no password (PF_OTA_PASSWORD ""). The device no longer
    challenges for auth; README documents the Arduino IDE 2.x prompt quirk
    and the espota.py / arduino-cli no-pr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
    [config.h, net_config.h]
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2026-06-02 Audio-react + Wi-Fi: non-blocking connect, single-threaded server, scalable knob mapping
    - Wi-Fi is now non-blocking with auto-reconnect (core_wifi.h begin()/tick()):
    boot no longer stalls ~8s waiting for the join, and a dropped/failed
    connection recovers on its own. OSC/OTA/audio services start on the
    connect edge and are idempotent across reconnects.
    - Audio-react server rebuilt single-threaded (serviced in the main loop via
    handle()), dropping the pinned core-0 task + portMUX spinlock that could
    wedge the render loop / trip the interrupt watchdog when a client
    connected. Lightweight hand parsing (no sscanf).
    - WS protocol accepts both absolute (k=N,v=F) and delta (d=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
    [net_config.h, patternflow.ino]
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2026-06-11 docs(firmware): add HUB75 driver-IC selection and panel compatibility guidance
    Add a PANEL_PROFILE switch in config.h (PANEL_STANDARD = 74HC595,
    PANEL_HIGHREFRESH = FM6126A/FM6124) wired to a HUB75_DRIVER macro that
    core_display.h passes to the matrix library. Defaults to PANEL_STANDARD,
    which expands to SHIFTREG — identical to the prior implicit behavior, so
    existing builds are unaffected.
    Document that GCLK PWM "video wall" panels (FM6363C/FM6373C, sold as
    1920/3840Hz modules) are unsupported by direct ESP32 HUB75 driving and
    stay dark regardless of config. Add a buy-time compatibility warning to
    the BUILD.md BOM/sourcing section and a short pointer in firmware README.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
    [config.h]
2026-06-14 feat(hardware): regenerate gerbers v2.1 with silkscreen fixes
    Clean up silkscreen for assembly clarity: align switch numbering and
    disambiguate R9/R10/C14/C15 labels. Re-export gerbers from updated PCB.
    [patternflow.kicad_pcb]
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2026-06-18 feat(hardware): rework ESP32<->J1 (HUB75) routing, regenerate v2.1 gerbers
    Re-route the tangled ESP32-to-J1 area in the PCB and schematic. Pin
    assignments unchanged (firmware config.h untouched). Regenerate and
    overwrite the v2.1 gerber package from the updated board.
    [patternflow.kicad_pcb, patternflow.kicad_sch]
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2026-06-22 feat(patterns): preset/custom structure, licensing metadata, drop video mode
    Establish the pattern format/ownership contract (issue #116) and remove the
    unused video mode.
    - Split patterns into curated presets/ (preset_*.h, "../src" includes) and
    root custom_*.h (editable as Arduino IDE tabs), renamed from origin/wave_saw
    and the old dev1/2/3 slots.
    - pattern_registry.h: PRESETS / CUSTOM sections + NUM_PRESETS.
    - Add _TEMPLATE.h (skeleton + SPDX/author/lineage header) and README.md
    (convention + CC-BY-SA-4.0 licensing, inbound=outbound, no CLA).
    - Remove the video / serial-upload content mode from the sketch and delete
    pattern_video.h.
    Web (JS is the source of truth):
    - L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
    [patternflow.ino]
2026-06-22 feat(patterns): preset library + reusable custom slots, custom-first registry
    - Ship the curated preset library under presets/ (~21 patterns) with
    SPDX/author license headers; the few that lag on hardware are excluded
    (documented in README.md).
    - Make custom patterns reusable slots: custom1/2/3.h with namespaces
    Custom1/2/3 — overwrite a slot's body and NAME to swap patterns without
    renaming files or touching the registry.
    - Order the registry custom-first (boots into slot 0 = your custom pattern);
    expose NUM_CUSTOM / NUM_PRESETS alongside NUM_PATTERNS.
    - Update README/_TEMPLATE to the reusable-slot convention.
    [preset_0511.h, preset_0512.h, preset_0515.h]
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2026-06-22 fix(firmware): keep Origin as pattern 1, list custom slots last
    The custom slots stay at the top of pattern_registry.h for easy editing, but
    they are now a separate customPatterns[] array. buildPatternList() (called once
    in setup) assembles the runtime list presets-then-custom, so the device boots
    into pattern 1 = Origin and the custom slots come last.
    [patternflow.ino]
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2026-06-23 feat(case): add one-shot print rib and wall-mount hanger hole
    - Reinforce one-shot (single-print) experiment models with ribs
    - Add wall-mounting frame hanger hole
    [oneshot_test_1.stl, oneshot_test_2.stl]
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2026-06-23 feat(firmware): live pattern preview behind the SELECT screen
    Holding K4 to browse patterns now renders the highlighted pattern full-screen
    behind the overlay so you can see what you're choosing, instead of just the
    number/name/hint on black.
    - Render the preview in the native landscape orientation (rotation 0, like
    running mode) so it fills the whole panel, then switch to portrait
    (rotation 1) only for the SELECT text — keeping the original text
    orientation. Frame ends back at rotation 0.
    - Feed the preview a neutral input frame so browsing with K4 doesn't drive
    the pattern's own parameters; it just animates over time.
    - Draw the labels on a small dark scrim for legibility over t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
    [patternflow.ino]
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2026-06-24 wip(case): refine one-piece enclosure (rib + experiment prints)
    Iterate on the single-piece print for #113: update the Blender source and
    regenerate the one-shot experiment STLs. Print verification pending —
    warping (shrinkage) and visible layer lines are not yet resolved.
    [oneshot_test_1.stl, oneshot_test_2.stl]
2026-06-24 wip(case): thicker walls + outer fillets + small snap-pins (anti-warp pass)
    Targeting the warping / seam-line issues on #113:
    - Wall thickness 2mm -> 3mm.
    - Round (fillet) the outer corners only.
    - Add small snap-pins at 3 slide joints (kept to 3 so assembly stays easy).
    Mouse-ear brims and slicing-side warp tuning still to come. Print
    verification pending.
    [oneshot_test_1.stl, oneshot_test_2.stl]
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2026-06-25 fix(firmware): invert encoder direction for Bourns PEC11R
    The simplified revision board uses the official Bourns PEC11R-4220F-S0024
    encoders, whose A/B phase is opposite the previous AliExpress clones, so
    rotation read reversed. Set INVERT_ENCODER to 0 (config.h) and match the
    encoder_test diagnostic sketch.
    Closes #146
    [config.h]
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2026-06-27 feat(pcb): v2.2 USB Type-C power input, SMD-free board
    Rework the board per the power-supply change in #114:
    - Switch power input to USB Type-C (SHOU HAN TYPE-C 14P CC-2.6,
    LCSC C5187475); add its footprint and 3D models.
    - Remove all SMD passives; the two 5.1k USB-C CC pull-downs are
    hand-soldered, so the whole board is hand-solderable.
    - Move the Type-C connector toward center for easier cable insertion.
    - Reduce overall board size; bump silkscreen to v2.2.
    Generate fab output patternflow_v2.2_test_gerber.zip (DRC clean: 0
    violations / 0 unconnected). The _test suffix stays until a fabricated
    board is verified.
    Refs #114
    [TYPE-C-TH_TYPE-C-14P-CC-2.6.step, patternflow.kicad_pcb, patternflow.kicad_sch]
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2026-06-28 feat(case): fit enclosure to v2.2 board; prune stale experiments
    Rework the enclosure to match the v2.2 PCB (USB Type-C opening
    repositioned, overall size reduced) in the Blender source and re-export
    the oneshot_test_1 print. Remove the obsolete big_oneshot and
    flat_version experiments, keeping only the oneshot_test parts.
    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
    [big_oneshot.stl, flat_version_1.stl, flat_version_2.stl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]
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2026-07-02 firmware: replace Arduino angle macros with typed constants
    Arduino.h defines PI / TWO_PI / HALF_PI / DEG_TO_RAD / RAD_TO_DEG /
    EULER as bare object-like macros, so any pattern that declares its own
    constant with one of those names is preprocessor-mangled into a compile
    error — AI-converted patterns hit this constantly (real case: DeepSeek's
    "static constexpr float PI" broke the build).
    config.h now #undefs them right after Arduino.h and redefines them as
    constexpr doubles with identical values: existing uses (wave_saw, 0518,
    0601 presets) keep working, and pattern namespaces may legally shadow
    them with their own definitions. Function-like macros (min/max/abs/
    constrain) are left untouch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
    [config.h]
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2026-07-03 firmware: safer select wrap, fastPow, steadier overlays + instant mode exit
    Correctness:
    - SELECT pattern index now uses floored modulo, so a large negative OSC
    knob delta can't land a negative index into patterns[] and crash.
    - Latch Wi-Fi failure status and drop the em dash from the IP line so the
    NETWORK screen text stops flickering between retry states / garbage glyphs.
    Perf:
    - Add PFMath::fastPow for per-pixel varying exponents (exp2/log2 bit-trick,
    ~0.1% error) — an order of magnitude cheaper than libm powf in the loop.
    UX:
    - Button gets a debounced clicked() edge; brightness and NETWORK modes exit
    instantly on a click instead of only on the 1s hold.
    - BRIGHTNESS notice now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
    [patternflow.ino]
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2026-07-03 chore(repo): adopt Git LFS for .blend/.stl going forward
    Binary CAD/print assets now go through Git LFS (.gitattributes filter), so
    future case revisions stop bloating the main history. Existing history is
    left untouched — no rewrite, no force-push — since a routine gc already
    reclaimed the local loose-object cruft (792MB -> 211MB .git).
    [01_plate_main.stl, 01_plate_main_easyfit.stl, 02_plate_dividers.stl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]
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2026-07-04 firmware(osc): drain rx queue, ping/announce, auto-learn remote host
    - pollReceive() drains up to 8 datagrams per frame (was 1) so fast Live
    automation no longer builds up queue latency
    - /patternflow/ping replies with a full announce (hello/version/ip +
    pattern state) so hosts that start after the device get current state
    - remote host is learned from any valid OSC sender; PF_OSC_REMOTE_HOST
    is now optional (default empty), K2 screen shows WAIT HOST until paired
    - incoming numeric args accepted as int or float (floats were silently
    dropped before); /patternflow/version sent alongside hello
    [net_config.h]
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2026-07-05 hardware(case): promote one-piece snap-fit enclosure to print-ready option (#113)
    - Move oneshot STLs out of experiment/ to print-ready/oneshot/ as an official
    build option: single-piece body + snap-fit closure, no bonding step.
    Requires a large-format bed (~330mm+, H2S-class); does not fit P1S/256mm.
    - Add divided_test_1..5.stl to experiment/: the one-piece design split into
    5 parts for 256mm beds (P1S-class, community printers). Modeled, not yet
    print-tested.
    - Document both in hardware/case/README.md and docs/assembly/enclosure/3d-print.md
    - Update Blender source with the new modeling
    [divided_test_1.stl, divided_test_2.stl, divided_test_3.stl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]
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2026-07-05 firmware(knobs): fix K1/K2 logical mapping, add K3 knob-map screen
    The LOGICAL_TO_PHYSICAL_KNOB table still mirrored K1<->K2 (a leftover
    left-right-mirroring assumption), so every K1 feature — brightness hold,
    OSC /knob/1, pattern hue — landed on the physical K2 encoder and vice
    versa. The PCB routes ENCn straight to the Kn position; make the table an
    identity and document why. Pin defines stay untouched, which keeps
    patternflow_stream and encoder_test (no remap layer) correct too.
    The web hero simulator had the same 1<->2 swap baked into the GLB mesh
    names; remap mesh name → knob id at the interaction layer in HeroScene.
    Also add a KNOB MAP screen on K3 longpress: numbered circles a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
    [config.h, patternflow.ino]
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2026-07-06 hardware(case): fix USB-C adapter clearance after encoder position change
    The enclosure models were drawn before the rotary encoder's position
    was updated, so the USB-C adapter cutout landed slightly off from a
    real assembled board. Adjusted height/clearance around that area on
    the source model and regenerated the affected print-ready STLs
    (oneshot + divided experiment set).
    [divided_test_1.stl, divided_test_2.stl, divided_test_3.stl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]
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2026-07-07 hardware(pcb): v3.0 test board — hybrid power input (USB-C + 2-pin screw terminal)
    Per the plan in issue #114: instead of splitting into two PCBs, one board now
    carries both power-input options.
    - Add a 2-pin screw terminal footprint on the back as a beginner-friendly
    bypass for the difficult USB-C THT soldering (strip a USB cable, screw it in)
    - Clean up routing
    - Bump silkscreen version text to v3.0
    - Bake v3.0 test Gerbers (DRC clean: 0 violations, 0 unconnected) into
    hardware/pcb/gerber/experiment/ with a do-not-order README
    - Delete patternflow_v2.2_test_gerber.zip so nobody orders the superseded
    test revision by mistake; BUILD_GUIDE warning updated to match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
    [patternflow.kicad_pcb, patternflow.kicad_sch]
2026-07-08 hardware(case): add v2 one-shot enclosure, quarantine v3-wip, warn on easyfit defect
    - oneshot/ renamed to oneshot_v3-wip/ — those STLs are dimensioned for the
    upcoming v3.0 board and won't fit a v2.x PCB
    - add oneshot_v2_1/2.stl to variants/ — the one-shot snap-fit enclosure
    for current v2.x boards (330mm+ bed)
    - case README restructured with a which-files-do-I-print overview table;
    one-shot section now covers v2 vs v3-wip and the separate black knob caps
    - easyfit main plate marked do-not-print-as-is with a link to Issue #154
    (missing LED matrix divider slot) in README and BUILD_GUIDE
    [oneshot_1.stl, oneshot_2.stl, oneshot_v2_1.stl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]
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2026-07-08 fix(case): store STLs as regular git files, not LFS
    GitHub's Download ZIP ships LFS objects as 1KB pointer files, so anyone
    grabbing the repo as a ZIP got unusable 3D models (reported on Discord).
    The STLs total ~1.6MB — no reason for LFS. Untrack *.stl and commit the
    real binaries so ZIP downloads always contain printable files with zero
    LFS bandwidth cost.
    The 45MB Blender source stays in LFS; the case README now points ZIP
    users to the release assets for it.
    [01_plate_main.stl, 01_plate_main_easyfit.stl, 02_plate_dividers.stl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]
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2026-07-17 fix(pcb): correct C11 value typo 1000uF/1.6V -> 1000uF/16V
    The part is a 16V Rubycon PX (16PX1000MEFC10X12.5); the schematic
    value read 1.6V, which would be under-spec on the 5V rail.
    [patternflow.kicad_pcb, patternflow.kicad_sch]
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2026-07-17 refactor(case): reorganize by build option, drop print-ready nesting
    hardware/case/ now has one folder per build option — standard/ (split
    plates, 256mm bed), oneshot/ (one-piece snap-fit, 330mm+), divided/
    (P1S-bed split, untested), knobs/ (shared, 15mm + 20mm) — replacing the
    print-ready/variants/experiment buckets whose semantics had drifted.
    - Drop numeric plate prefixes; knob files named by shaft length
    (knobs_20mm.stl was the unsuffixed 03_plate_knobs.stl)
    - Rename Blender source patternflow_v1.blend -> patternflow_case.blend
    (it holds v2/v3 geometry, the v1 name misled)
    - Remove empty parts/ and print-ready/ placeholders
    - Update every path reference: BUILD_GUIDE, assembly do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
    [bom_v3.0.csv, divided_test_1.stl, divided_test_2.stl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]
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2026-07-17 docs(pcb): add PCB README with schematic and board renders
    - hardware/pcb/README.md: board overview, front/back kicad-cli renders,
    schematic SVG inline, gerber revision table, kicad-cli regeneration
    recipes
    - Regenerate schematic.pdf from the current v3.0 sources (the old copy
    predated the v2.1 routing rework)
    - Fix J1 3D model: the real part is a 2x8 female socket, not a male
    box header — visual-only change (footprint pads untouched) so renders
    match assembled boards
    [patternflow.kicad_pcb]
2026-07-17 fix(pcb): J1 3D model is a shrouded IDC box header after all
    The board part was right all along (male box header, per the BOM's
    Würth 61201621621) — only the 3D model lacked the shroud walls, which
    made renders look unlike the real part. Swap the bare PinHeader model
    for the KiCad IDC-Header_2x08 model and re-render. Visual only.
    [patternflow.kicad_pcb]
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

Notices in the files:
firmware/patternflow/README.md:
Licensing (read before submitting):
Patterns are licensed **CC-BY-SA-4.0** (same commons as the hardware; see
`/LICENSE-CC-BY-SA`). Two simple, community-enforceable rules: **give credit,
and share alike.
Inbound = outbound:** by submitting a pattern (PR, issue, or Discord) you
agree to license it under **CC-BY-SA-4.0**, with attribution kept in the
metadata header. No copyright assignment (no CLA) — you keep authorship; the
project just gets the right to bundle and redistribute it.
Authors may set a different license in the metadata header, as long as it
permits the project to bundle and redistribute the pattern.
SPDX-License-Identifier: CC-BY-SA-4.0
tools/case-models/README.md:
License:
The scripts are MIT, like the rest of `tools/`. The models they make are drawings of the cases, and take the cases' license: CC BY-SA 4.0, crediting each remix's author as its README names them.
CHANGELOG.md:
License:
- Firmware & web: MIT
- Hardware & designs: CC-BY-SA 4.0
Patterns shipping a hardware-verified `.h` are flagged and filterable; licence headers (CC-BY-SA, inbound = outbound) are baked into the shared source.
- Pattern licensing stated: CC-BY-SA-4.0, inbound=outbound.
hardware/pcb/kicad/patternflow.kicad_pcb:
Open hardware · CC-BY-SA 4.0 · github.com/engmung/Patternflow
